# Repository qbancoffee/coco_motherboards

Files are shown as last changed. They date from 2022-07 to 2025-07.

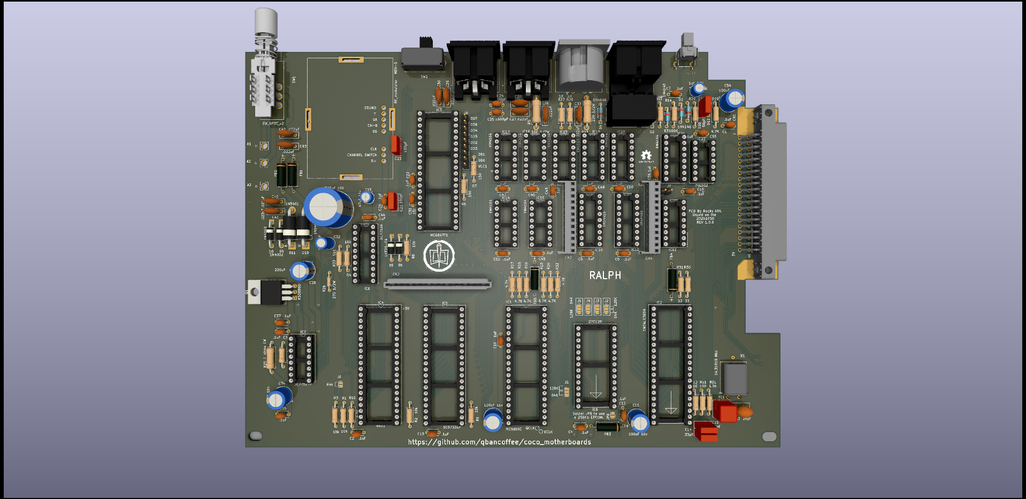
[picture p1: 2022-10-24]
images/26-313xB_rendered.png

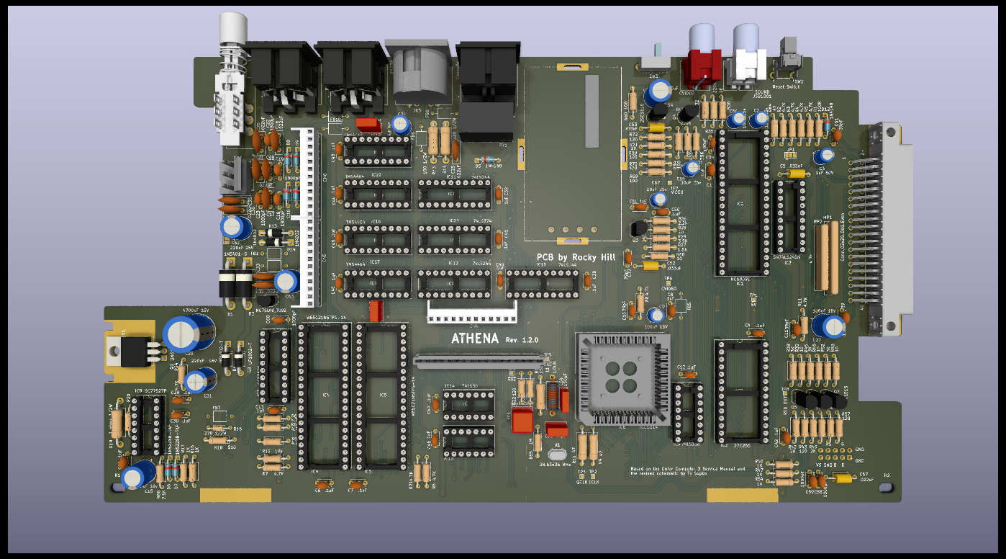
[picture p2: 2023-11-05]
images/26-3334_rendered.png

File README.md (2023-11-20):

# CoCo Motherboards
This repository contains KiCAD project files that contain schematics and board designs for the TRS-80 Tandy Color Computers that I have recreated.
If you want to view and edit these KiCAD projects you'll need KiCAD 7 or higher.
You can generate gerber files and order these boards fom your favorite PCB manufacturer.<br>

In order to get the design files you can either use git to clone the repository or you can click on the code button above and download
a zip file containing the projects.

To use git, open a terminal and type the following.
```bash
git clone https://github.com/qbancoffee/coco_motherboards.git
```
---

# Color Computer 2
- [26-302x](#26-302x)
- [26-313xA](#26-313xA)
- [26-313xB](#26-313xB)
---

# Color Computer 3
- [26-3334](#26-3334)
---

## 26-302x
- [Schematic](pdfs/26-302x_schematic.pdf)
- [Board Layout](pdfs/26-302x_layout.pdf)
- [Rendered Image](images/26-302x_rendered.png)
- [Interactive BOM](https://htmlpreview.github.io/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)
- [Bill Of Materials](https://github.com/qbancoffee/coco_motherboards/blob/main/bom/26-302x_bill_of_materials.csv)
### Current status
- [x] Ordered
- [x] Assembled
- [x] Tested
### Videos
- [Testing the first revision of the board](https://youtu.be/QcRTDDZ0i-s)
- [Testing the second revision of the board](https://youtu.be/V18fohn3YzE)
- [Testing the first revision of the Daiquiri on this board. The Daiquiri has since been fixed ](https://youtu.be/-PZM2CGa1yw)
---

## 26-313xA
- [Schematic](pdfs/26-313xA_schematic.pdf)
- [Board Layout](pdfs/26-313xA_layout.pdf)
- [Rendered Image](images/26-313xA_rendered.png)
- [Interactive BOM](https://htmlpreview.github.io/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)
- [Bill Of Materials](https://github.com/qbancoffee/coco_motherboards/blob/main/bom/26-313xA_bill_of_materials.csv)
### Current status
- [x] Ordered
- [x] Assembled
- [x] Tested
### Videos
- [Copying the board layout and original path of the traces 1](https://youtu.be/ZVgJEOnWDyY)
- [Copying the board layout and original path of the traces 2](https://youtu.be/GyRi-DuZtJM)
- [Checking the board design against an actual board](https://youtu.be/TTYBf1dwHVs)
- [Testing the assembled board](https://youtu.be/1itwh79Q89k)
---

## 26-313xB
- [Schematic](pdfs/26-313xB_schematic.pdf)
- [Board Layout](pdfs/26-313xB_layout.pdf)
- [Rendered Image](images/26-313xB_rendered.png)
- [Interactive BOM](https://htmlpreview.github.io/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)
- [Bill Of Materials](https://github.com/qbancoffee/coco_motherboards/blob/main/bom/26-313xB_bill_of_materials.csv)
### Current status
- [x] Ordered
- [x] Assembled
- [x] Tested/works but draws too much current and I don't know why yet.
### Videos
- [A timelapse of the assembly](https://youtu.be/u0PwnJCS3qc)
---

## 26-3334
- [Changes](log/26-3334_log.txt)
- [Schematic](pdfs/26-3334_schematic.pdf)
- [Board Layout](pdfs/26-3334_layout.pdf)
- [Rendered Image](images/26-3334_rendered.png)
- [Interactive BOM](https://htmlpreview.github.io/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)
- [Bill Of Materials](https://github.com/qbancoffee/coco_motherboards/blob/main/bom/26-3334_bill_of_materials.csv)
### Current status
- [x] Ordered
- [ ] Assembled
- [ ] Tested
### Videos
- [Testing the first revision of the board](https://youtu.be/vjpey5T-lSU)
- [Testing the RGB port](https://youtu.be/EB2sbTMWF-Q)
- [Booting NitrOS 9 Ease Of Use](https://youtu.be/wSlYcxvCpys)
- [Live build of Rev 1.1.0](https://www.youtube.com/live/8h18PMZnpsQ?si=pRSccAcrxts3vaQu)
- [Live build of Rev 1.1.0 part two it's alive!](https://www.youtube.com/live/c8nBd60M5xo?si=J7Mg_S3EWyWba8Rm)
- [Rev 1.2.0 test fit](https://youtube.com/shorts/IoNqxNSzjd0)
---

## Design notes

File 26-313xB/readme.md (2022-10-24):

# TRS-80 Color Computer 2 [26-3134B / 26-3136B]

This directory contains a KiCad project
for the schematic & PCB of the TRS-80 Color Computer 2
models 26-3134B and 26-3136B.

## Sources

### Schematic

Schematics are not available for this model:
The reference board was donated by MrDave6309

## Completed
- [N/A]
 
## Tested
- [N/A]

## Videos
- [N/A]

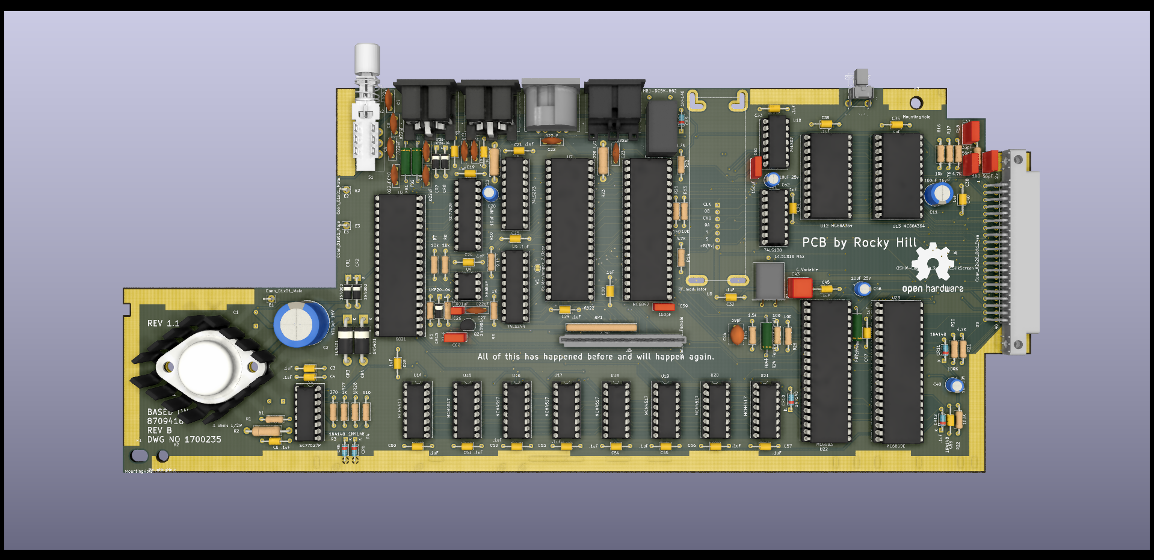
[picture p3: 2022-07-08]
images/26-302x_rendered.png

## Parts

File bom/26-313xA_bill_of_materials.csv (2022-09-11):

Requested Quantity 1 | Part Number | Vendor | Manufacturer Part Number | Description | Reference Designator
1 | ED11524-ND | Digikey | 6331-0-00-15-00-00-08-0 | CONN PC PIN CIRC 0.093DIA GOLD | A1
1 | ED11524-ND | Digikey | 6331-0-00-15-00-00-08-0 | CONN PC PIN CIRC 0.093DIA GOLD | A2
1 | ED11524-ND | Digikey | 6331-0-00-15-00-00-08-0 | CONN PC PIN CIRC 0.093DIA GOLD | A3
21 | 490-8814-ND | Digikey | RDER71H104K0K1H03B | CAP CER 0.1UF 50V X7R RADIAL | C1 C5 C6 C4 C10 C55 C12 C54 C99915 C16 C56 C31 C22 C20 C35 C2 C18 C44 C37 C7 C39
1 | 490-9014-1-ND | Digikey | RDE5C1H390J0M1H03A | CAP CER 39PF 50V C0G/NP0 RADIAL | C13
1 | 445-180775-1-ND | Digikey | FA28NP01H330JNU06 | CAP CER 33PF 50V NP0 RADIAL | C14
2 | 490-9030-1-ND | Digikey | RDE5C1H560J0M1H03A | CAP CER 56PF 50V C0G/NP0 RADIAL | C15 C17
1 | 493-16246-1-ND | Digikey | ULD1C470MDD1TD | CAP ALUM 47UF 20% 16V RADIAL | C19
2 | 445-180756-1-ND | Digikey | FA28C0G2E151JNU06 | CAP CER 150PF 250V C0G RADIAL | C23 C21
2 | 445-180714-1-ND | Digikey | FA28C0G1H182JNU06 | CAP CER 1800PF 50V C0G RADIAL | C24 C25
1 | 493-10824-1-ND | Digikey | UES1E100MDM1TD | CAP ALUM 10UF 20% 25V RADIAL | C32
1 | 1189-2204-ND | Digikey | 16ZLJ4700M16X25 | CAP ALUM 4700UF 20% 16V RADIAL | C36
1 | 493-15896-1-ND | Digikey | URS1C221MPD1TA | CAP ALUM 220UF 20% 16V RADIAL | C38
12 | 399-14073-1-ND | Digikey | C317C223M5U5TA7301 | CAP CER 0.022UF 50V Z5U RADIAL | C57 C59 C27 C33 C26 C28 C29 C30 C40 C41 C42 C43
1 | 399-13913-1-ND | Digikey | C315C102K1R5TA7301 | CAP CER 1000PF 100V X7R RADIAL | C58
1 | 718-2229-ND | Digikey | 515D105M050JA6AE3 | CAP ALUM 1UF 20% 50V RADIAL | C8
3 | P10369CT-ND | Digikey | ECA-1CM101B | CAP ALUM 100UF 20% 16V RADIAL | C9 C11 C34
1 | S9672-ND | Digikey | EBC20DRAS | CONN EDGE DUAL FMALE 40POS 0.100 | CN1
1 | A144434-ND | Digikey | 6-520415-6 | CONN FFC VERT 16POS 2.54MM PCB | CN2
2 | 23-0022182121-ND | Digikey | 22182121 | CONN RCPT 12POS 0.1 GOLD PCB | CN4 CN3
2 | 1N5401GDICT-ND | Digikey | 1N5401G-T | DIODE GEN PURP 100V 3A AXIAL | D10 D11
6 | 1N4148FS-ND | Digikey | 1N4148 | DIODE GEN PURP 100V 200MA DO35 | D12 D4 D13 D2 D1 D3
3 | 1N4148FS-ND | Digikey | 1N4148 | DIODE GEN PURP 100V 200MA DO35 | D7 D5 D6
2 | 1N4002GDICT-ND | Digikey | 1N4002G-T | DIODE GEN PURP 100V 1A DO41 | D8 D9
6 | 1934-1364-ND | Digikey | 2743007111 | FERRITE BEAD AXIAL 1LN | FB6 FB4 FB3 FB5 FB2 FB1
1 | ED3048-5-ND | Digikey | ED40DT | CONN IC DIP SOCKET 40POS TIN | IC1
2 | AE9995-ND | Digikey | A 18-LC-TT | CONN IC DIP SOCKET 18POS TIN | IC10 IC11
1 | A120349-ND | Digikey | 1-2199298-4 | CONN IC DIP SOCKET 16POS TIN | IC12
1 | 296-1639-5-ND | Digikey | SN74LS138N | IC DECODER/DEMUX 1X3:8 16DIP | IC12
2 | AE9989-ND | Digikey | A 14-LC-TT | CONN IC DIP SOCKET 14POS TIN | IC13 IC99913
2 | 296-12770-5-ND | Digikey | CD74HC02E | IC GATE NOR 4CH 2-INP 14DIP | IC13 IC99913
1 | 1175-1479-ND | Digikey | 243-20-1-03 | CONN IC DIP SOCKET 20POS TIN | IC15
1 | 296-1657-5-ND | Digikey | SN74LS273N | IC FF D-TYPE SNGL 8BIT 20DIP | IC15
1 | AE9986-ND | Digikey | A 08-LC-TT | CONN IC DIP SOCKET 8POS TIN | IC16
1 | 296-NE555P-ND | Digikey | NE555P | IC OSC SINGLE TIMER 100KHZ 8-DIP | IC16
1 | ED3048-5-ND | Digikey | ED40DT | CONN IC DIP SOCKET 40POS TIN | IC2
1 | ED3048-5-ND | Digikey | ED40DT | CONN IC DIP SOCKET 40POS TIN | IC3
1 | ED3048-5-ND | Digikey | ED40DT | CONN IC DIP SOCKET 40POS TIN | IC4
1 | ED3048-5-ND | Digikey | ED40DT | CONN IC DIP SOCKET 40POS TIN | IC5
1 | 1175-1479-ND | Digikey | 243-20-1-03 | CONN IC DIP SOCKET 20POS TIN | IC6
1 | A120349-ND | Digikey | 1-2199298-4 | CONN IC DIP SOCKET 16POS TIN | IC7
1 | AE10004-ND | Digikey | A 28-LC-TT | CONN IC DIP SOCKET 28POS TIN | IC8
1 | CP-2360-ND | Digikey | SDS-60J | CONN RCPT FMALE DIN 6POS SOLDER | JK1
1 | CP-2360-ND | Digikey | SDS-60J | CONN RCPT FMALE DIN 6POS SOLDER | JK2
1 | CP-2340-ND | Digikey | SDS-40J | CONN RCPT FMALE DIN 4POS SOLDER | JK3
1 | CP-2350-ND | Digikey | SDS-50J | CONN RCPT FMALE DIN 5POS SOLDER | JK4
1 | KSD880OFS-ND | Digikey | KSD880O | TRANS NPN 60V 3A TO220-3 | Q1
1 | 1514-PN2222APBFREE-ND | Digikey | PN2222A PBFREE | TRANS NPN 40V 0.8A TO92-3 | Q2
3 | 100XBK-ND | Digikey | MFR-25FBF52-100R | RES 100 OHM 1% 1/4W AXIAL | R11 R12 R29
2 | CF14JT100KCT-ND | Digikey | CF14JT100K | RES 100K OHM 5% 1/4W AXIAL | R14 R13
8 | CF14JT4K70CT-ND | Digikey | CF14JT4K70 | RES 4.7K OHM 5% 1/4W AXIAL | R20 R17 R15 R16 R18 R19 R6 R10
1 | 1.50KXBK-ND | Digikey | MFR-25FBF52-1K5 | RES 1.5K OHM 1% 1/4W AXIAL | R21
1 | CF14JT510RCT-ND | Digikey | CF14JT510R | RES 510 OHM 5% 1/4W AXIAL | R22
1 | CF12JT220RCT-ND | Digikey | CF12JT220R | RES 220 OHM 5% 1/2W AXIAL | R23
1 | 2019-CF1/4CT52R510JCT-ND | Digikey | CF1/4CT52R510J | RES 51 OHM 5% 1/4W AXIAL | R24
1 | RSMF1JTR100CT-ND | Digikey | RSMF1JTR100 | RES 0.1 OHM 5% 1W AXIAL | R25
1 | BC4316CT-ND | Digikey | SFR16S0002700JA500 | RES 270 OHM 1/2W 5% AXIAL | R28
2 | CF14JT33R0CT-ND | Digikey | CF14JT33R0 | RES 33 OHM 5% 1/4W AXIAL | R30 R31
3 | CF14JT1K00CT-ND | Digikey | CF14JT1K00 | RES 1K OHM 5% 1/4W AXIAL | R32 R27 R26
1 | CF14JT9K10CT-ND | Digikey | CF14JT9K10 | RES 9.1K OHM 5% 1/4W AXIAL | R33
1 | 13-MFR-25FRF52-2K2CT-ND | Digikey | MFR-25FRF52-2K2 | RES 2.2K OHM 1% 1/4W AXIAL | R34
1 | CF12JT100RCT-ND | Digikey | CF12JT100R | RES 100 OHM 5% 1/2W AXIAL | R5
1 | CF14JT150RCT-ND | Digikey | CF14JT150R | RES 150 OHM 5% 1/4W AXIAL | R7
6 | CF14JT10K0CT-ND | Digikey | CF14JT10K0 | RES 10K OHM 5% 1/4W AXIAL | R8 R2 R3 R4 R9 R1
1 | 2449-J0971CS5VDC.45-ND | Digikey | J0971CS5VDC.45 | RELAY GEN PURPOSE SPDT 10A 5V | RY1
1 | 401-1223-ND | Digikey | F2UEE | SWITCH PUSH DPDT 0.5A 125V | SW1
1 | 563-1558-ND | Digikey | MFS201N-16-Z | SWITCH SLIDE DPDT 1A 125V | SW2
1 | SW410-ND | Digikey | B3F-3152 | SWITCH TACTILE SPST-NO 0.05A 24V | SW3
1 | SW451-ND | Digikey | B32-1010 | CAP TACTILE SQUARE BLACK | SW3
1 | 2447-GKG50015-ND | Digikey | GKG50015 | CAP TRIMMER 10-50PF 100V TH | TC1
1 | CTX088-ND | Digikey | MP143 | CRYSTAL 14.31818MHZ SERIES TH | X1
1 | 595-SN74LS623N | Mouser | SN74LS623N | Transceiver, Non-Inverting | IC14

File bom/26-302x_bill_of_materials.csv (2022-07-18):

Requested Quantity 1 | Digi-Key Part Number 1 | Manufacturer Part Number | Description
1 | 1.50KXBK-ND | MFR-25FBF52-1K5 | RES 1.5K OHM 1% 1/4W AXIAL
3 | 100XBK-ND | MFR-25FBF52-100R | RES 100 OHM 1% 1/4W AXIAL
50 | 1109PHCT-ND | A104K15X7RF5TAA | CAP CER 0.1UF 50V X7R AXIAL
3 | 1175-1479-ND | 243-20-1-03 | CONN IC DIP SOCKET 20POS TIN
2 | 1175-2551-ND | 243-24-1-06 | CONN IC DIP SOCKET 24POS TIN
1 | 1189-1145-ND | 16YXJ4700M16X25 | CAP ALUM 4700UF 20% 16V RADIAL
4 | 1934-1364-ND | 2743007111 | FERRITE BEAD AXIAL 1LN
1 | 2019-CF1/4CT52R510JCT-ND | CF1/4CT52R510J | RES 51 OHM 5% 1/4W AXIAL
1 | 2447-GKG50015-ND | GKG50015 | CAP TRIMMER 10-50PF 100V TH
1 | 2449-J0971CS5VDC.45-ND | J0971CS5VDC.45 | RELAY GEN PURPOSE SPDT 10A 5V
1 | 296-1627-5-ND | SN74LS02N | IC GATE NOR 4CH 2-INP 14DIP
1 | 296-1639-5-ND | SN74LS138N | IC DECODER/DEMUX 1X3:8 16DIP
1 | 296-1653-5-ND | SN74LS244N | IC BUF NON-INVERT 5.25V 20DIP
1 | 296-1657-5-ND | SN74LS273N | IC FF D-TYPE SNGL 8BIT 20DIP
3 | 36-1211-ND | 1211 | CONN QC TAB 0.110 SOLDER
1 | 401-1223-ND | F2UEE | SWITCH PUSH DPDT 0.5A 125V
2 | 445-180756-1-ND | FA28C0G2E151JNU06 | CAP CER 150PF 250V C0G RADIAL
2 | 445-180775-1-ND | FA28NP01H330JNU06 | CAP CER 33PF 50V NP0 RADIAL
1 | 490-9014-1-ND | RDE5C1H390J0M1H03A | CAP CER 39PF 50V C0G/NP0 RADIAL
2 | 490-9030-1-ND | RDE5C1H560J0M1H03A | CAP CER 56PF 50V C0G/NP0 RADIAL
1 | 493-10824-1-ND | UES1E100MDM1TD | CAP ALUM 10UF 20% 25V RADIAL
2 | 493-1809-ND | UPW1E100MDD | CAP ALUM 10UF 20% 25V RADIAL
1 | 718-2229-ND | 515D105M050JA6AE3 | CAP ALUM 1UF 20% 50V RADIAL
11 | A120349-ND | 1-2199298-4 | CONN IC DIP SOCKET 16POS TIN
1 | A144434-ND | 6-520415-6 | CONN FFC VERT 16POS 2.54MM PCB
1 | CF12JT100RCT-ND | CF12JT100R | RES 100 OHM 5% 1/2W AXIAL
1 | CF12JT220RCT-ND | CF12JT220R | RES 220 OHM 5% 1/2W AXIAL
2 | CF14JT100KCT-ND | CF14JT100K | RES 100K OHM 5% 1/4W AXIAL
10 | CF14JT10K0CT-ND | CF14JT10K0 | RES 10K OHM 5% 1/4W AXIAL
1 | CF14JT150RCT-ND | CF14JT150R | RES 150 OHM 5% 1/4W AXIAL
3 | CF14JT1K00CT-ND | CF14JT1K00 | RES 1K OHM 5% 1/4W AXIAL
1 | CF14JT270RCT-ND | CF14JT270R | RES 270 OHM 5% 1/4W AXIAL
10 | CF14JT4K70CT-ND | CF14JT4K70 | RES 4.7K OHM 5% 1/4W AXIAL
1 | CF14JT510RCT-ND | CF14JT510R | RES 510 OHM 5% 1/4W AXIAL
1 | CF14JT9K10CT-ND | CF14JT9K10 | RES 9.1K OHM 5% 1/4W AXIAL
1 | CP-2340-ND | SDS-40J | CONN RCPT FMALE DIN 4POS SOLDER
1 | CP-2350-ND | SDS-50J | CONN RCPT FMALE DIN 5POS SOLDER
2 | CP-2360-ND | SDS-60J | CONN RCPT FMALE DIN 6POS SOLDER
1 | CTX088-ND | MP143 | CRYSTAL 14.31818MHZ SERIES TH
5 | ED3048-5-ND | ED40DT | CONN IC DIP SOCKET 40POS TIN
1 | HS110-ND | 501603B00000G | HEAT SINK TO-3 1.25" COMPACT
1 | S9672-ND | EBC20DRAS | CONN EDGE DUAL FMALE 40POS 0.100
1 | SW410-ND | B3F-3152 | SWITCH TACTILE SPST-NO 0.05A 24V
1 | SW451-ND | B32-1010 | CAP TACTILE SQUARE BLACK
1 | AE9989-ND | A 14-LC-TT | CONN IC DIP SOCKET 14POS TIN
1 | AE9986-ND | A 08-LC-TT | CONN IC DIP SOCKET 8POS TIN
2 | P10369CT-ND | ECA-1CM101B | CAP ALUM 100UF 20% 16V RADIAL
1 | A105964CT-ND | LR1LJR10 | RES 0.1 OHM 5% 1/2W AXIAL
6 | 1N4148FS-ND | 1N4148 | DIODE GEN PURP 100V 200MA DO35
11 | 399-14073-1-ND | C317C223M5U5TA7301 | CAP CER 0.022UF 50V Z5U RADIAL
1 | 4610X-1-472LF-ND | 4610X-101-472LF | RES ARRAY 9 RES 4.7K OHM 10SIP
1 | 399-13913-1-ND | C315C102K1R5TA7301 | CAP CER 1000PF 100V X7R RADIAL
2 | 1N4002GDICT-ND | 1N4002G-T | DIODE GEN PURP 100V 1A DO41
2 | 1N5401GDICT-ND | 1N5401G-T | DIODE GEN PURP 100V 3A AXIAL
1 | 2N3055GOS-ND | 2N3055G | TRANS NPN 60V 15A TO204
1 | 1514-PN2222APBFREE-ND | PN2222A PBFREE | TRANS NPN 40V 0.8A TO92-3
1 | 296-NE555P-ND | NE555P | IC OSC SINGLE TIMER 100KHZ 8-DIP
3 | 1N4148FS-ND | 1N4148 | DIODE GEN PURP 100V 200MA DO35
1 | 493-12679-1-ND | UVP1C100MDD1TD | CAP ALUM 10UF 20% 16V RADIAL
1 | CP1-3533NG-ND | SJ1-3533NG | CONN JACK STEREO 3.5MM R/A
1 | S9716-ND | SBH11-NBPC-D03-ST-BK | CONN HEADER VERT 6POS 2.54MM
1 | 401-1215-ND | F0201 | CAP PUSHBUTTON ROUND BLACK

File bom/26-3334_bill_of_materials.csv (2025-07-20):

Qty | Reference(s) | Value | Manufacturer part# | Vendor | Vendor 2nd part# | Vendor part# | Description 2nd part | MPN | Manufacturer 2nd part#
24 | C1, C4, C6, C7, C8, C12, C13, C14, C26, C28, C30, C38, C39, C40, C41, C42, C43, C44, C45, C46, C47, C48, C50, C51 | .1uF | RDER71H104K0M1H03A | digikey |  | 490-9144-1-ND
4 | C2, C55, C56, C67 | 10uF 25v | UPW1E100MDD | digikey |  | 493-1809-ND
1 | C3 | 1uF 50V | 515D105M050JA6AE3 | digikey |  | 718-2229-ND
3 | C5, C52, C53 | .033uF | C410C333K5R5TA7200 | digikey |  | 399-4470-1-ND
1 | C9 | 100uF 16V | 16ZLH100MEFC5X11 | digikey |  | 1189-1148-ND
4 | C10, C11, C37, C61 | 39pF | K390J15C0GF5TL2 | digikey |  | BC1008CT-ND
2 | C15, C27 | 100uF 16v | UST1C101MDD1TA | digikey |  | 493-17434-1-ND
10 | C16, C17, C20, C21, C25, C32, C33, C35, C36, C49 | .022uF | C317C223M5U5TA7301 | digikey |  | 399-14073-1-ND
4 | C18, C19, C22, C23 | 1800pF | FA28C0G1H182JNU06 | digikey |  | 445-180714-1-ND
1 | C24 | 10uF NP | UVP1E100MDD1TD | digikey |  | 493-12688-1-ND
1 | C29 | 4700uF 16V | 16PK4700MEFC12.5X25 | digikey |  | 1189-1123-ND
1 | C31 | 220uF 16V | URS1C221MPD1TA | digikey |  | 493-15896-1-ND
1 | C34 | 100pF | K101J15C0GF5TH5 | digikey |  | BC1042CT-ND
1 | C54 | 470uF | ECA-1CM471 | digikey |  | P5141-ND
1 | C57 | .022uF | C410C223K5R5TA7200 | digikey |  | 399-4464-1-ND
3 | C58, C59, C68 | 1000pF | K102K10X7RF5UH5 | digikey |  | BC2659CT-ND
1 | C60 | 33pF | FA28NP01H330JNU06 | digikey |  | 445-180775-1-ND
2 | C62, C63 | 220uF 25V | ECA-1EM221 | digikey |  | P5153-ND
1 | C64 | 150pF | FA28C0G2E151JNU06 | digikey |  | 445-180756-1-ND
1 | C65 | 82pF | K820J15C0GF5TH5 | digikey |  | BC1041CT-ND
1 | C66 | 27pF | K270J15C0GF5TH5 | digikey |  | BC1035CT-ND
1 | CN1 | Conn_02x20_Odd_Even | EBC20DRAS | digikey |  | S9672-ND
1 | CN2 | Conn_01x16_Female | 6-520415-6 | digikey |  | A144434-ND
1 | CN3 | Conn_02x05_Odd_Even | PRPC005DAAN-RC | digikey |  | S2011EC-05-ND
3 | CN4, CN5, CN6 | Conn_01x12_Female | 22182121 | digikey |  | 23-0022182121-ND
1 | CN7 | Conn_01x03_Male | 9652038 | digikey |  | WM18824-ND
2 | D1, D2 | 1N5401-G | 1N5401 | digikey |  | 641-1314-1-ND
2 | D3, D4 | UF1002-T | UF1002-T | digikey |  | UF1002DICT-ND
2 | D5, D12 | 1N4148 | 1N4148 | digikey |  | 1N4148FS-ND
2 | D6, D7 | 1N5228B-TAP | 1N5228B-TAP | digikey |  | 1N5228B-TAPGICT-ND
4 | D8, D9, D10, D11 | 1N4148 | DIODE GEN PURP 100V 200MA DO35 | digikey |  | 1N4148FS-ND
2 | D13, D14 | 1N4002 | 1N4002-TP | digikey |  | 1N4002-TPMSCT-ND
8 | FB1, FB2, FB5, FB6, FB7, FB8, FB9, FB10 |  | 28L0138-10R-10 | digikey |  | 240-2438-1-ND
1 | IC1 | MC6809E | ED40DT | digikey |  | ED3048-5-ND
1 | IC2 | 27C256 | AT27C256R-45PU | digikey |  | AT27C256R-45PU-ND
1 | IC3 | SN74LS245N | SN74LS245N | digikey |  | 296-1655-5-ND |  | SN74LS245N
1 | IC4 | W65C21N6TPG-14 | W65C21N6TPG-14 | mouser |  | 955-W65C21N6TPG-14
1 | IC5 | W65C21N6TPG-14 | W65C21N6TPG-14 | mouser |  | 955-W65C21N6TPG-14
1 | IC6 | TCC1014 | A-CCS 068-G-T | digikey |  | AE11249-ND
1 | IC7 | SC77526 | 243-20-1-03 | digikey |  | 1175-1479-ND
1 | IC8 | SC77527P | 1-2199298-4 | digikey |  | A120349-ND
1 | IC9 | 74LS138 | SN74LS138N | digikey |  | 296-1639-5-ND
3 | IC10, IC11, IC12 | 74LS244 | SN74LS244N | digikey |  | 296-1653-5-ND
1 | IC13 | 74LS374 | SN74ALS374AN | digikey |  | 296-1498-5-ND
1 | IC14 | 74LS30 | SN74LS30N | digikey |  | 296-3693-5-ND
1 | IC15 | 74LS04 | SN74LS04N | digikey |  | 296-1629-5-ND
4 | IC16, IC17, IC18, IC19 | TMS4464 | A 18-LC-TT | digikey |  | AE9995-ND
1 | IC36 | MC78L08_TO92 | UA78L08ACLPRE3 | digikey |  | 296-UA78L08ACLPRE3CT-ND
1 | J5A1001 | CVIDEO | KLPX-0848A-2-R | digikey |  | 2092-KLPX-0848A-2-R-ND
1 | J5B1001 | SOUND | KLPX-0848A-2-W | digikey |  | 2092-KLPX-0848A-2-W-ND
1 | JK1 | Left Joystick | 1N4148 | digikey |  | 1N4148FS-ND
1 | JK2 | Right Joystick | SDS-60J | digikey |  | CP-2360-ND
1 | JK3 | RS232 | SDS-40J | digikey |  | CP-2340-ND
1 | JK4 | Cassette | SDS-50J | digikey |  | CP-2350-ND
1 | JP1 | SolderJumper_3_Bridged12
1 | JP2 | SolderJumper_2_Open
1 | L1 | 1.8uH | 1537-18K | digikey |  | 1134-1090-1-ND
1 | MP1 | 4.7k | 770101472P | digikey |  | 770-101-R4.7KP-ND
1 | MP2 | 4.7k | 4609H-101-472LF | digikey |  | 4609H-101-472LF-ND
1 | Q1 | 2N6123 | 2N6123 PBFREE | digikey |  | 1514-2N6123PBFREE-ND | Heatsink
5 | Q2, Q3, Q5, Q6, Q7 | 2SC1815 | 2SC1815 PBFREE | digikey |  | 1514-2SC1815PBFREE-ND
1 | Q4 | BCX38C | BCX38C | digikey |  | BCX38C-ND
1 | R1 | 100K | MFR-25FBF52-100K | digikey |  | 100KXBK-ND
13 | R2, R3, R4, R5, R6, R7, R8, R11, R21, R24, R59, R61, R62 | 4.7K | Stackpole Electronics Inc | digikey |  | CF14JT4K70CT-ND
2 | R9, R10 | 47 | CF12JT47R0 | digikey |  | CF12JT47R0CT-ND
1 | R12 | 10k | CF14JT10K0 | digikey |  | CF14JT10K0CT-ND
1 | R13 | 100 1/2W | CF12JT100R | digikey |  | CF12JT100RCT-ND
1 | R14 | 220 1/2W | CF12JT220R | digikey |  | CF12JT220RCT-ND
1 | R15 | 270 1/2W | SFR16S0002700JA500 | digikey |  | BC4316CT-ND
6 | R16, R17, R36, R40, R47, R54 | 1K | CF14JT1K00 | digikey |  | CF14JT1K00CT-ND
1 | R18 | 510 | CF14JT510R | digikey |  | CF14JT510RCT-ND
1 | R19 | .1 ohms 1/2W | LR1LJR10 | digikey |  | A105964CT-ND
1 | R20 | 51 | CF1/4CT52R510J | digikey |  | 2019-CF1/4CT52R510JCT-ND
5 | R22, R43, R50, R57, R72 | 120 | CF14JT120R | digikey |  | CF14JT120RCT-ND
1 | R23 | 82 | CF1/4CT52R820J | digikey |  | 2019-CF1/4CT52R820JCT-ND
1 | R26 | 2.2K | CF14JT2K20 | digikey |  | CF14JT2K20CT-ND
1 | R27 | 1.5K | RNF14FTD1K50 | digikey |  | RNF14FTD1K50CT-ND
6 | R28, R39, R46, R53, R68, R71 | 10 | CFR-25JB-52-10R | digikey |  | 10QBK-ND
1 | R29 | 3.9K | CF14JT3K90 | digikey |  | CF14JT3K90CT-ND
4 | R30, R34, R60, R69 | 100 | CF14JT100R | digikey |  | CF14JT100RCT-ND
1 | R31 | 39K | CFR-25JB-52-39K | digikey |  | 39KQBK-ND
1 | R32 | 20K | CFR-25JB-52-20K | digikey |  | 20KQBK-ND
2 | R33, R35 | 220K | CF14JT220K | digikey |  | CF14JT220KCT-ND
3 | R38, R45, R52 | 3K | CFR-25JB-52-3K | digikey |  | 3.0KQBK-ND
3 | R42, R49, R56 | 2K | RNF14FTD2K00 | digikey |  | RNF14FTD2K00CT-ND
1 | R63 | 150 | CF12JT150R | digikey |  | CF12JT150RCT-ND
1 | R64 | 47 | CF14JT47R0 | digikey |  | CF14JT47R0CT-ND
1 | R65 | 1M | RNF14FTD1M00 | digikey |  | RNF14FTD1M00CT-ND
1 | R66 | 7.5K | RNF14FTD7K50 | digikey |  | RNF14FTD7K50CT-ND
1 | R70 | 470 | CF14JT470R | digikey |  | CF14JT470RCT-ND
1 | RF1 | CoCo3RFModulator
1 | RY1 | J0971CS5VDC.45 | J0971CS5VDC.45 | digikey |  | 2449-J0971CS5VDC.45-ND
1 | SW1 | SW_DPDT_x2 | F2UEE | digikey |  | 401-1223-ND
1 | SW2 | Reset Switch | B3F-3152 | digikey | SW451-ND | SW410-ND |  |  | B32-1010
1 | SW3 | SW3 | EG1213 | digikey |  | EG1906-ND
1 | TC1 | 10pF-50pF | GKG60015 | digikey |  | 2447-GKG60015-ND
1 | TP1 | 5V
1 | TP2 | ECLK
1 | TP3 | QCLK
1 | TP4 | ~{RAS}
1 | TP5 | ~{CAS}
1 | TP6 | CVIDEO
1 | TP7 | VIDEO
1 | TP8 | RED OUT
1 | X1 | 28.63636 MHz | ECS-286.3-20-46X | digikey |  | XC1766-ND

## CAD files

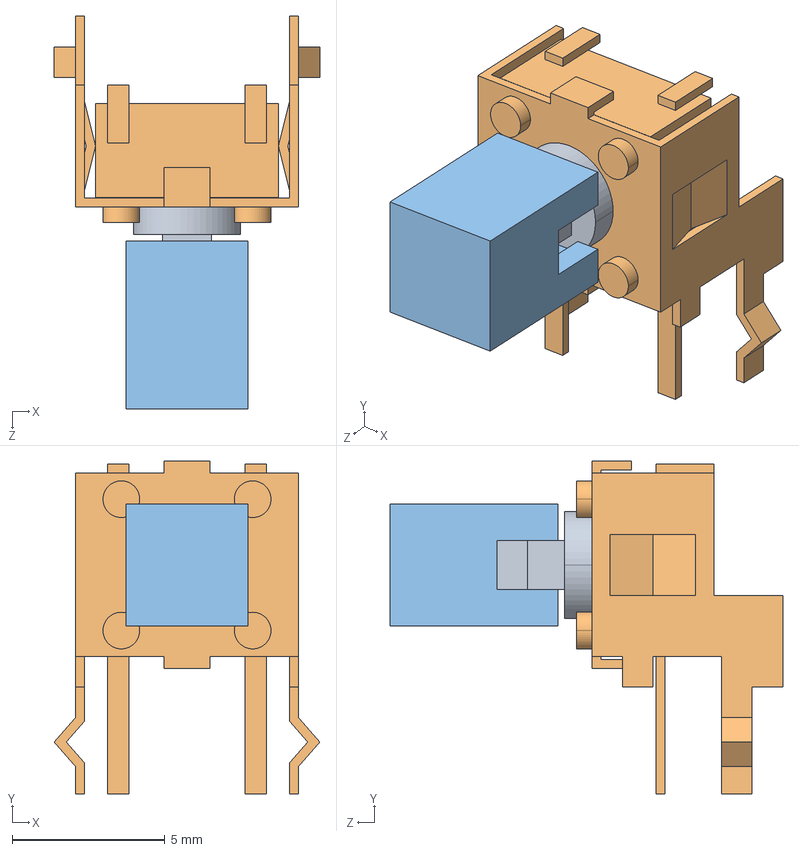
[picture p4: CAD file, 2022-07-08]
26-313xB/3d_models/B3F-3152.step
8.70 x 10.9 x 12.9 mm
B3F_3152_BUTTON
B3F_3152_BASE
B32_1000

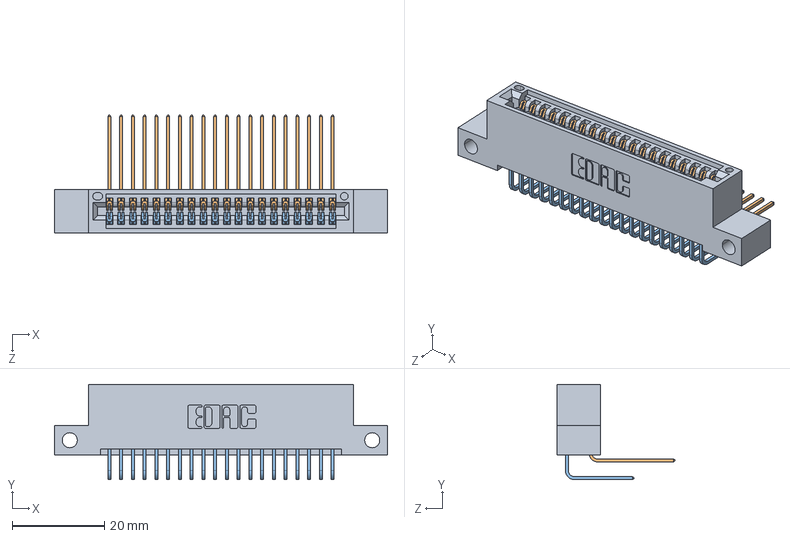
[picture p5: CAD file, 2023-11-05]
26-3334/3d_models/EDAC Card_Edge_Connector.step
72.0 x 20.6 x 25.5 mm
345 Part_Flush Mounting Lugs - Side Mount
345-292-001_558 559 Tail - 1 x 20
345-292-001_559 Tail - 2 x 20

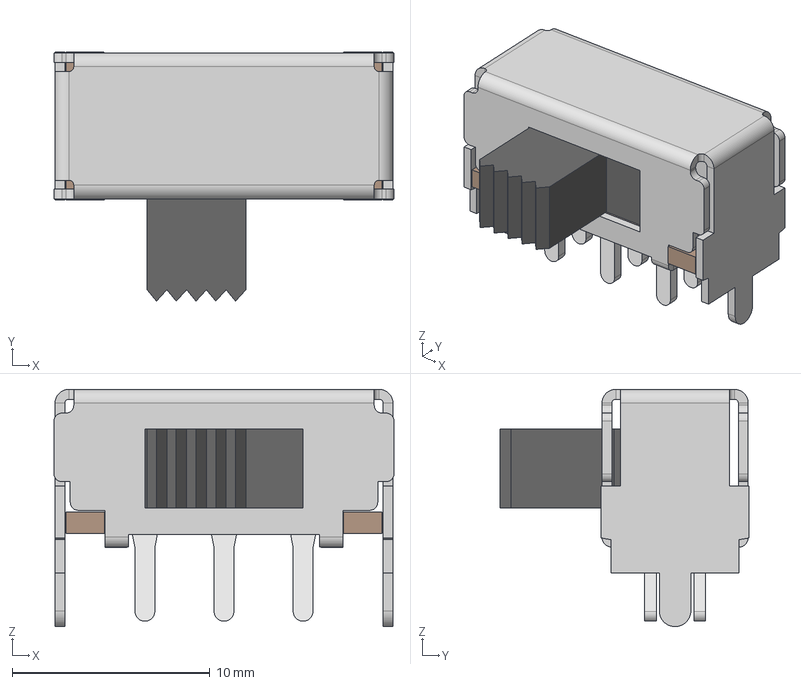
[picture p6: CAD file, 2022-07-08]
26-313xB/3d_models/MFS201N-19-Z.step
17.2 x 12.6 x 12.0 mm
BodyBottomPlate

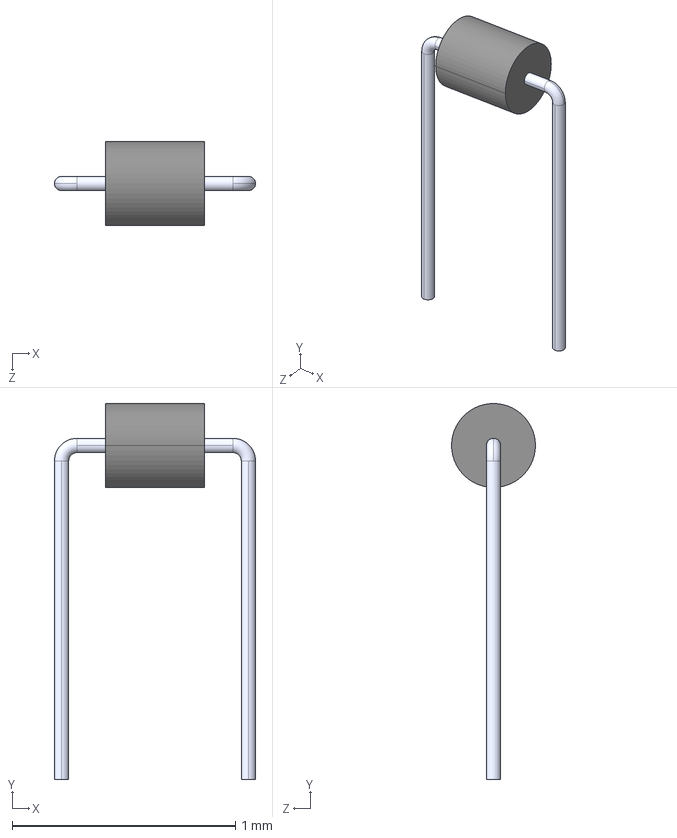
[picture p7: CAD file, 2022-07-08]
26-3334/3d_models/28L0138-10R-10.step
0.901 x 1.68 x 0.376 mm

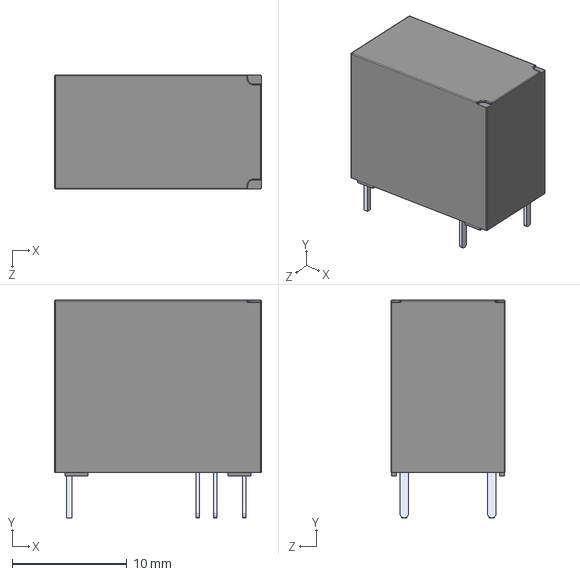
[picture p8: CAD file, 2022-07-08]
26-313xB/3d_models/J0971CS5VDC.45.step
18.0 x 19.0 x 9.95 mm

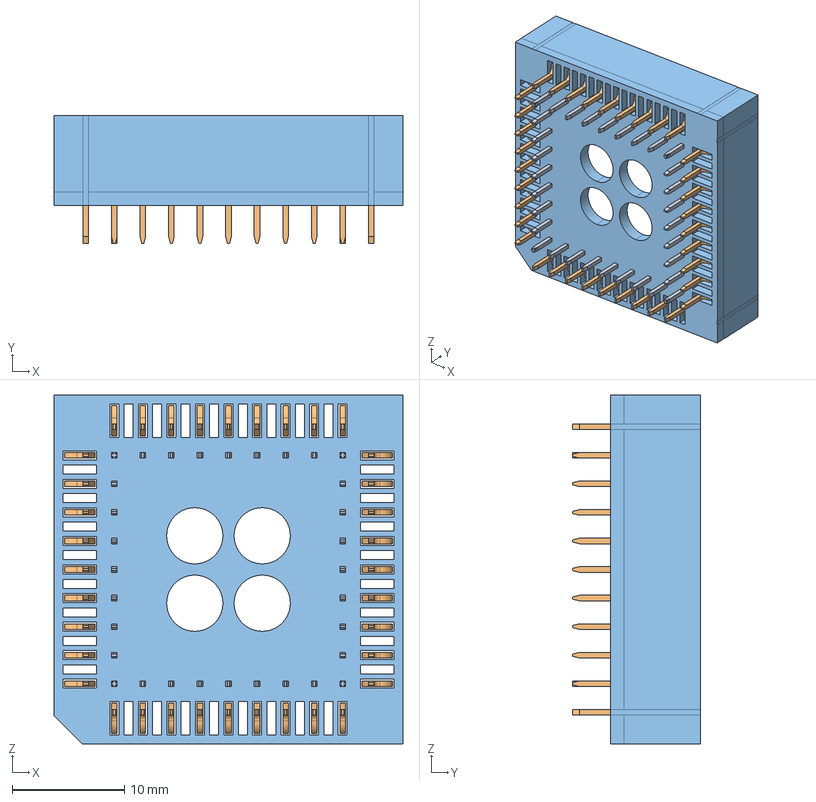
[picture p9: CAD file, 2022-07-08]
26-3334/3d_models/a-ccs_068-z-t.stp
31.1 x 11.4 x 31.1 mm

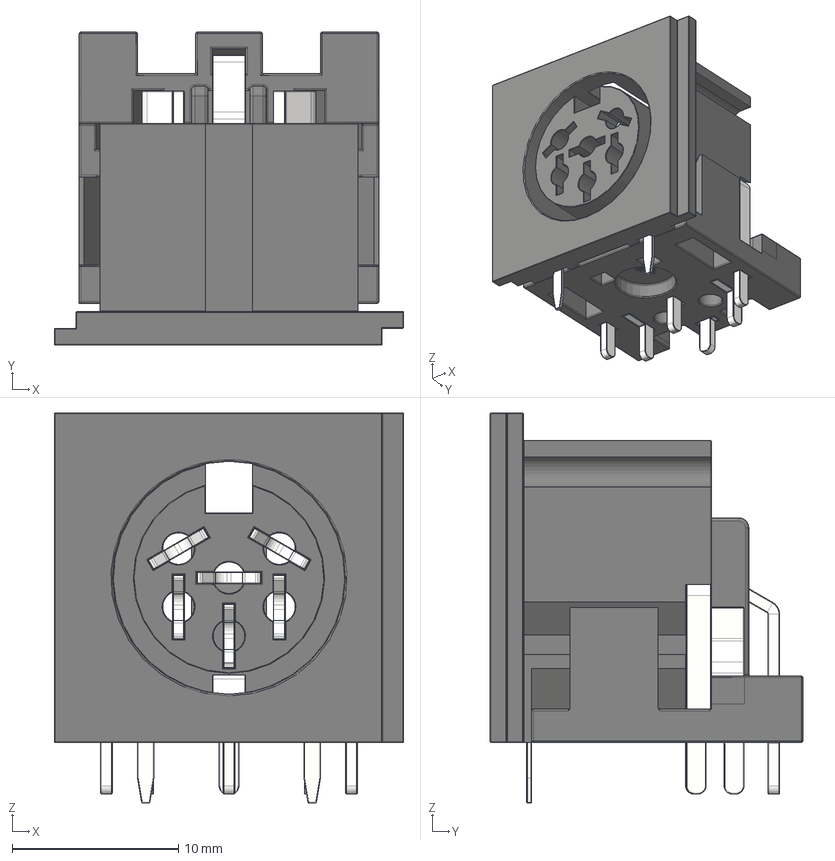
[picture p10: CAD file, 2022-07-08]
26-313xB/3d_models/DIN-6.step
21.0 x 18.8 x 23.4 mm
Baseplate IEC
Pin3
Pin4_2
Pin5_1
Pin6
Gnd pins
Housing

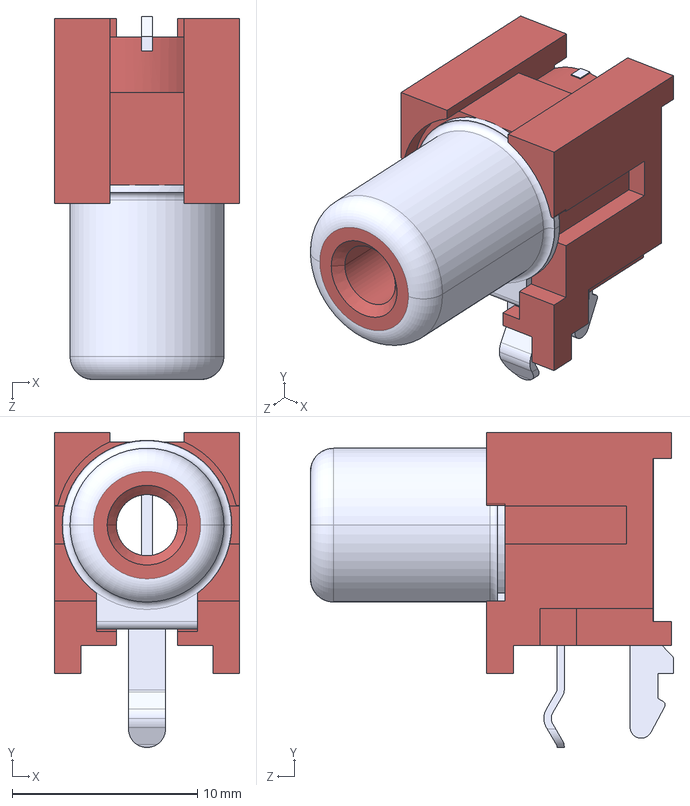
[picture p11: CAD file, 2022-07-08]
26-3334/3d_models/KLPX-0848A-2-R_rA4.STEP
10.0 x 17.0 x 19.6 mm

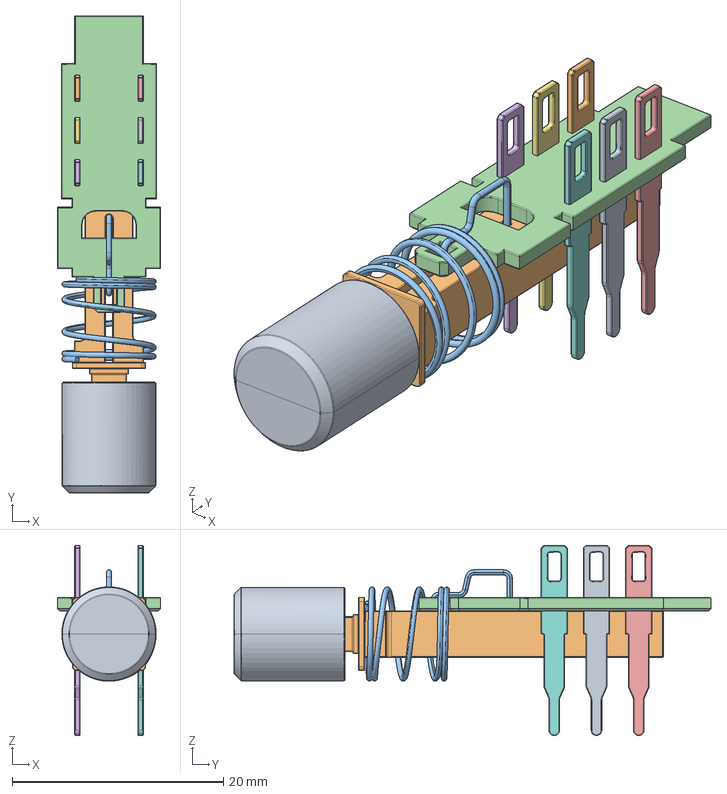
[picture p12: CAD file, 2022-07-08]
26-313xB/3d_models/switch.step
9.80 x 45.2 x 18.0 mm

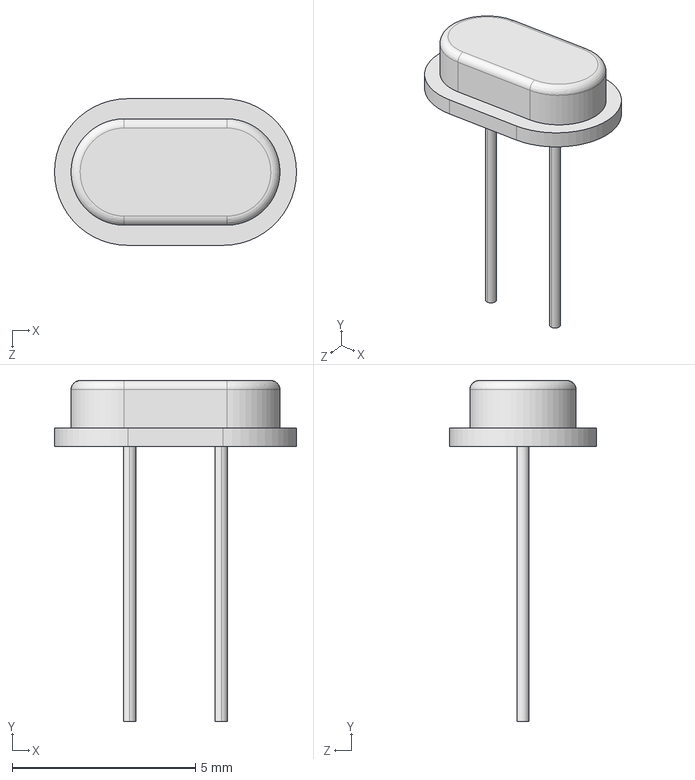
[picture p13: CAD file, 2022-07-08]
26-3334/3d_models/ECS-286.3-20-46X.step
6.60 x 9.30 x 4.00 mm

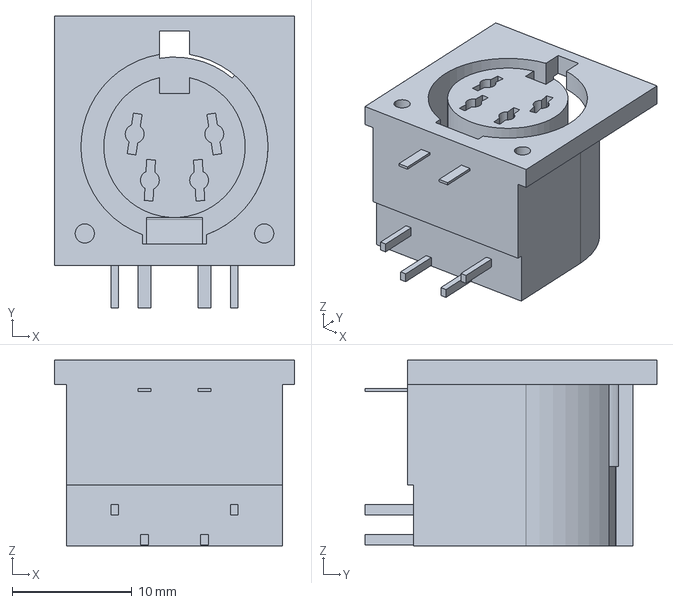
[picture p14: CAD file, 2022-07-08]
26-313xB/3d_models/DIN-4.stp
20.1 x 24.4 x 15.5 mm

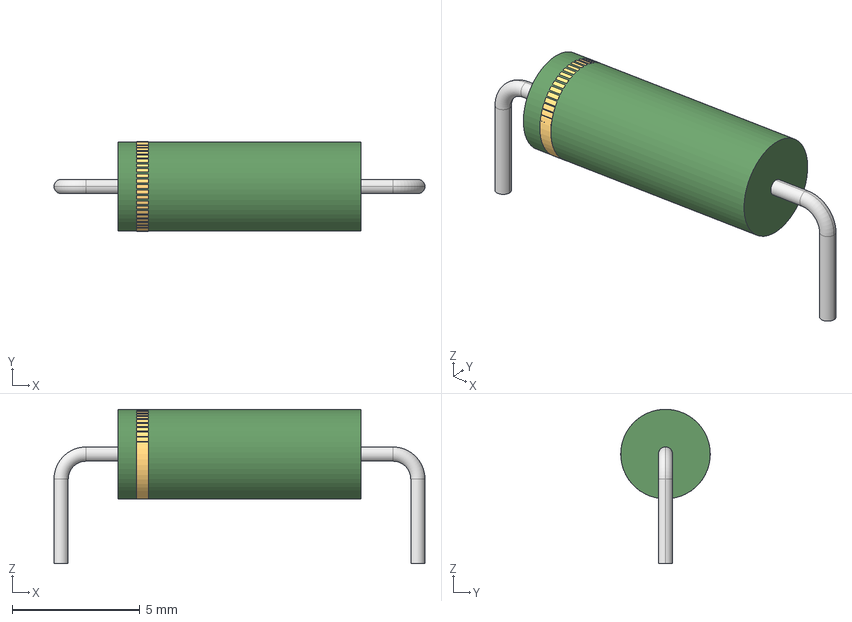
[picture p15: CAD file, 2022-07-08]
26-313xB/3d_models/ferrite_bead.step
14.5 x 3.51 x 6.05 mm

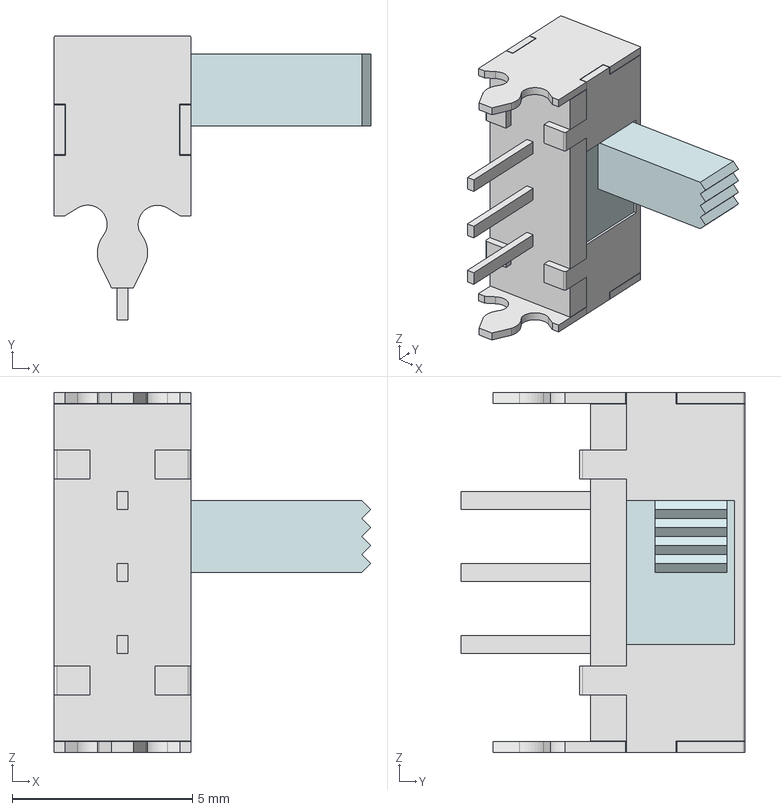
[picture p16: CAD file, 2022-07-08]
26-3334/3d_models/EG1213.stp
8.80 x 7.90 x 10.0 mm
EG1213 SHELL
EG1213 TERM
EG1213 ACTUATOR

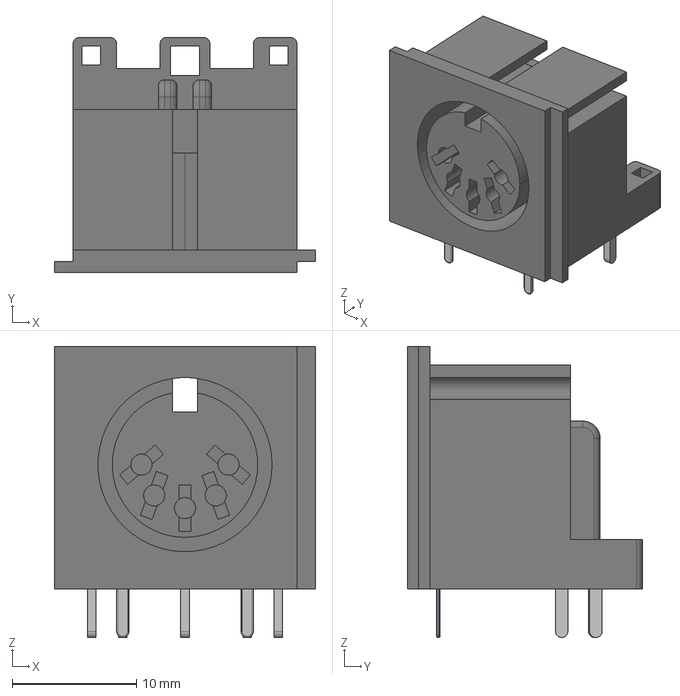
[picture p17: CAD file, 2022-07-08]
26-313xB/3d_models/din-5-jack.step
21.0 x 18.9 x 23.4 mm

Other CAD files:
26-3334/3d_models/KLPX-0848A-2-W_rA4.STEP
26-313xB/3d_models/reset_switch.step
26-313xB/3d_models/channel_switch.stp
26-313xB/3d_models/keyboard_connector.stp
26-313xB/3d_models/022182121.stp
26-313xB/3d_models/power_post.STEP
26-3334/3d_models/009652038.stp
26-3334/3d_models/022182121.step

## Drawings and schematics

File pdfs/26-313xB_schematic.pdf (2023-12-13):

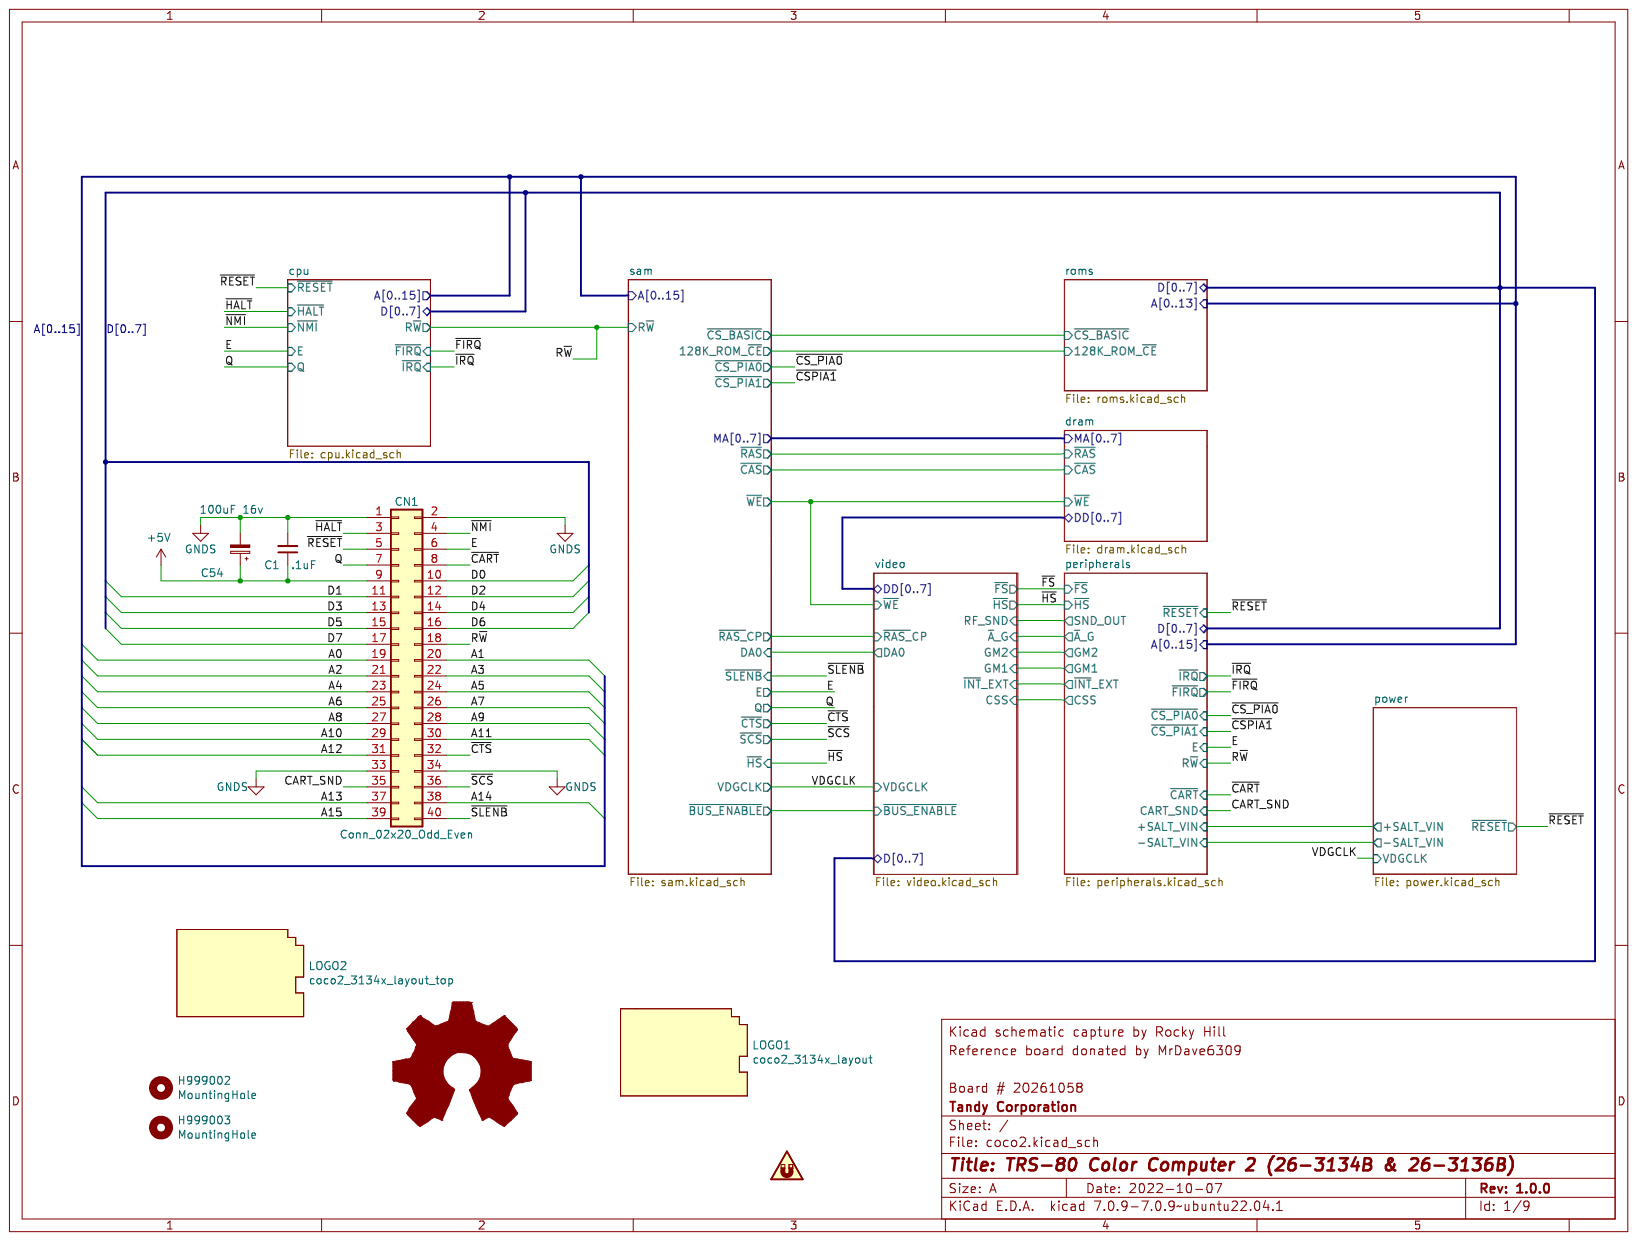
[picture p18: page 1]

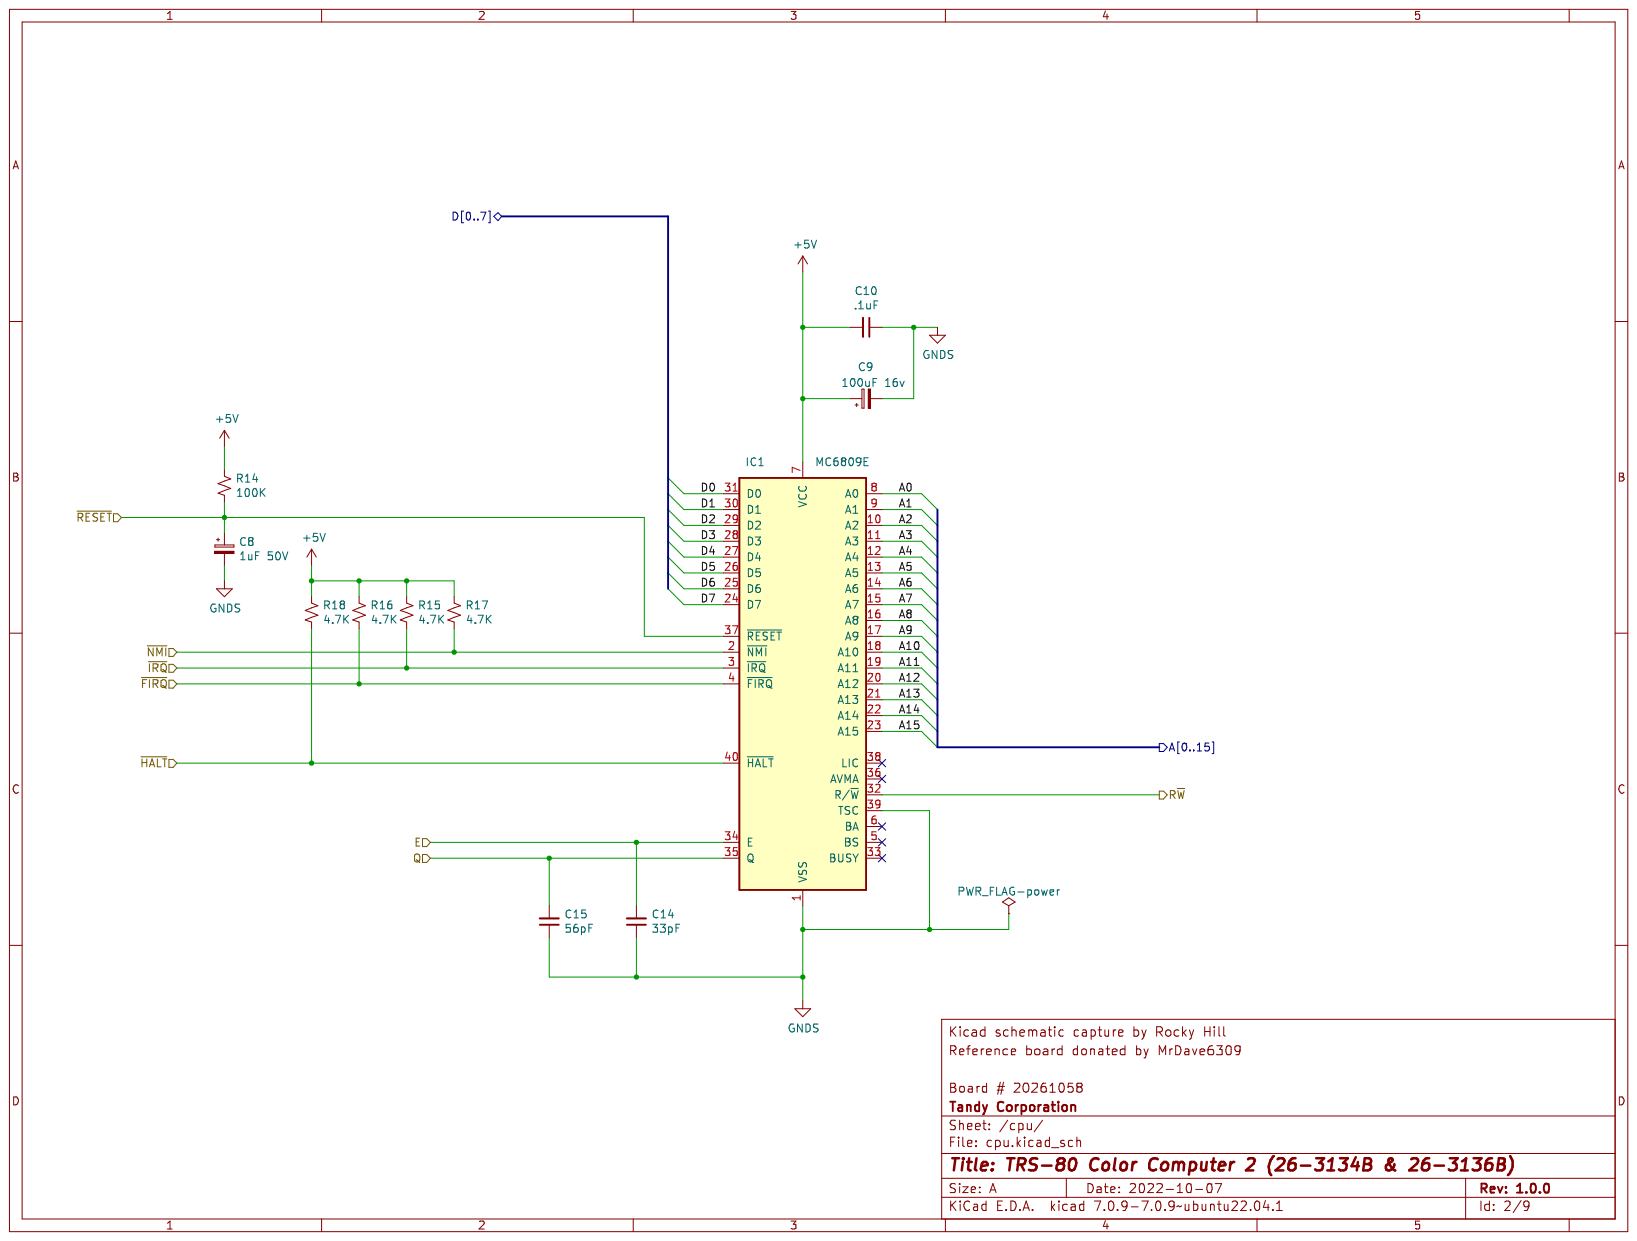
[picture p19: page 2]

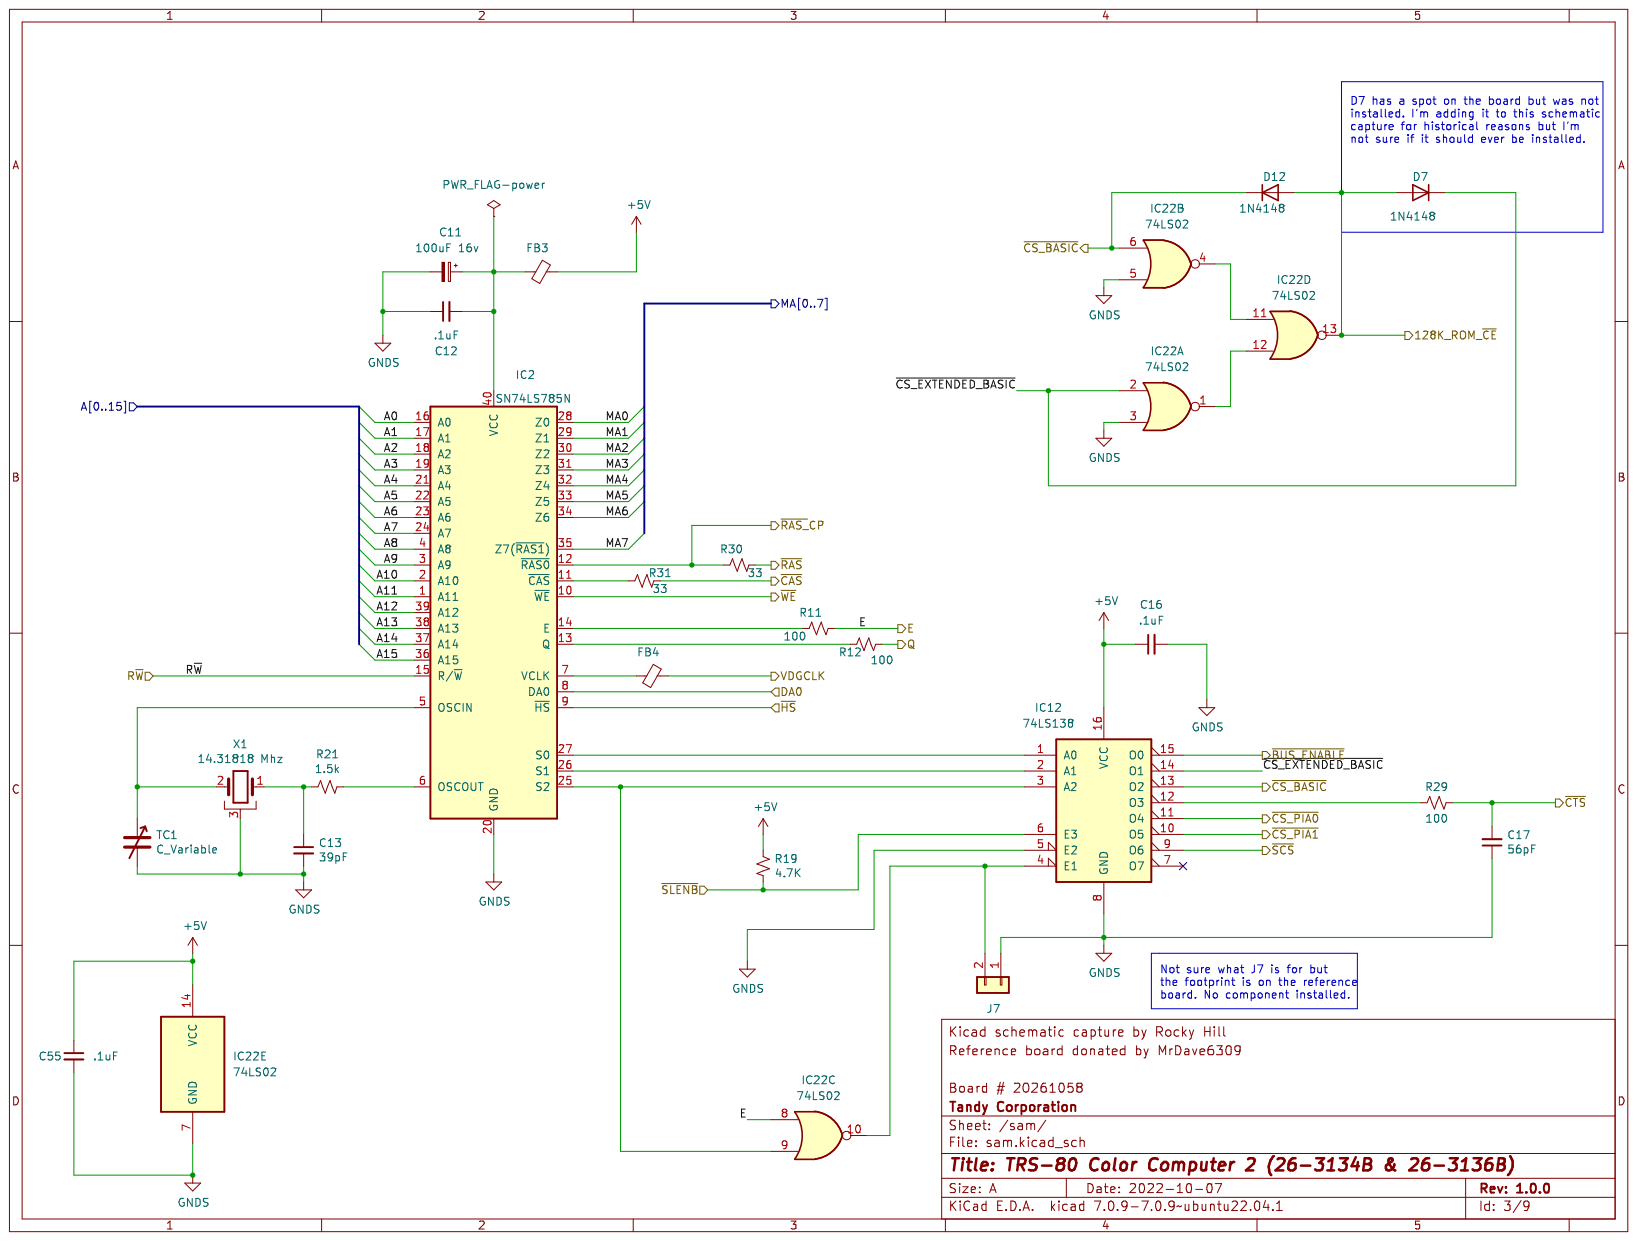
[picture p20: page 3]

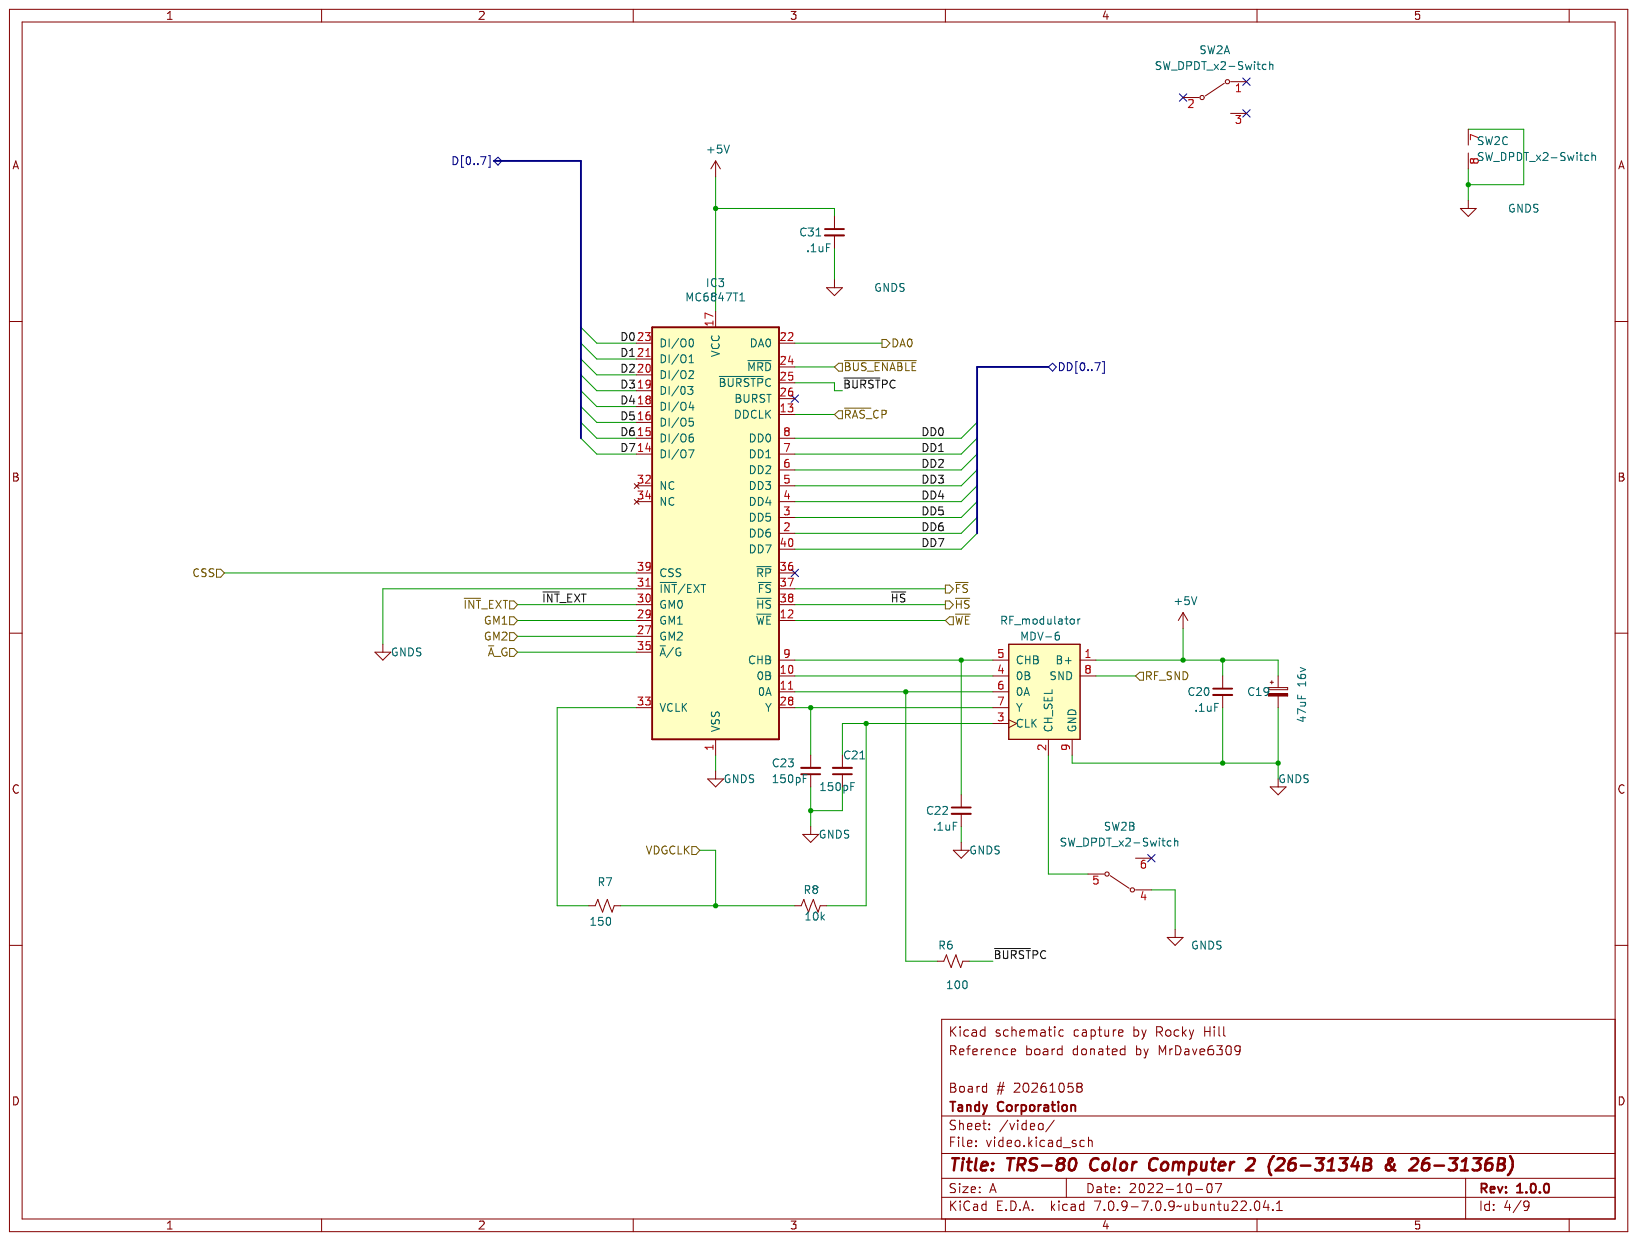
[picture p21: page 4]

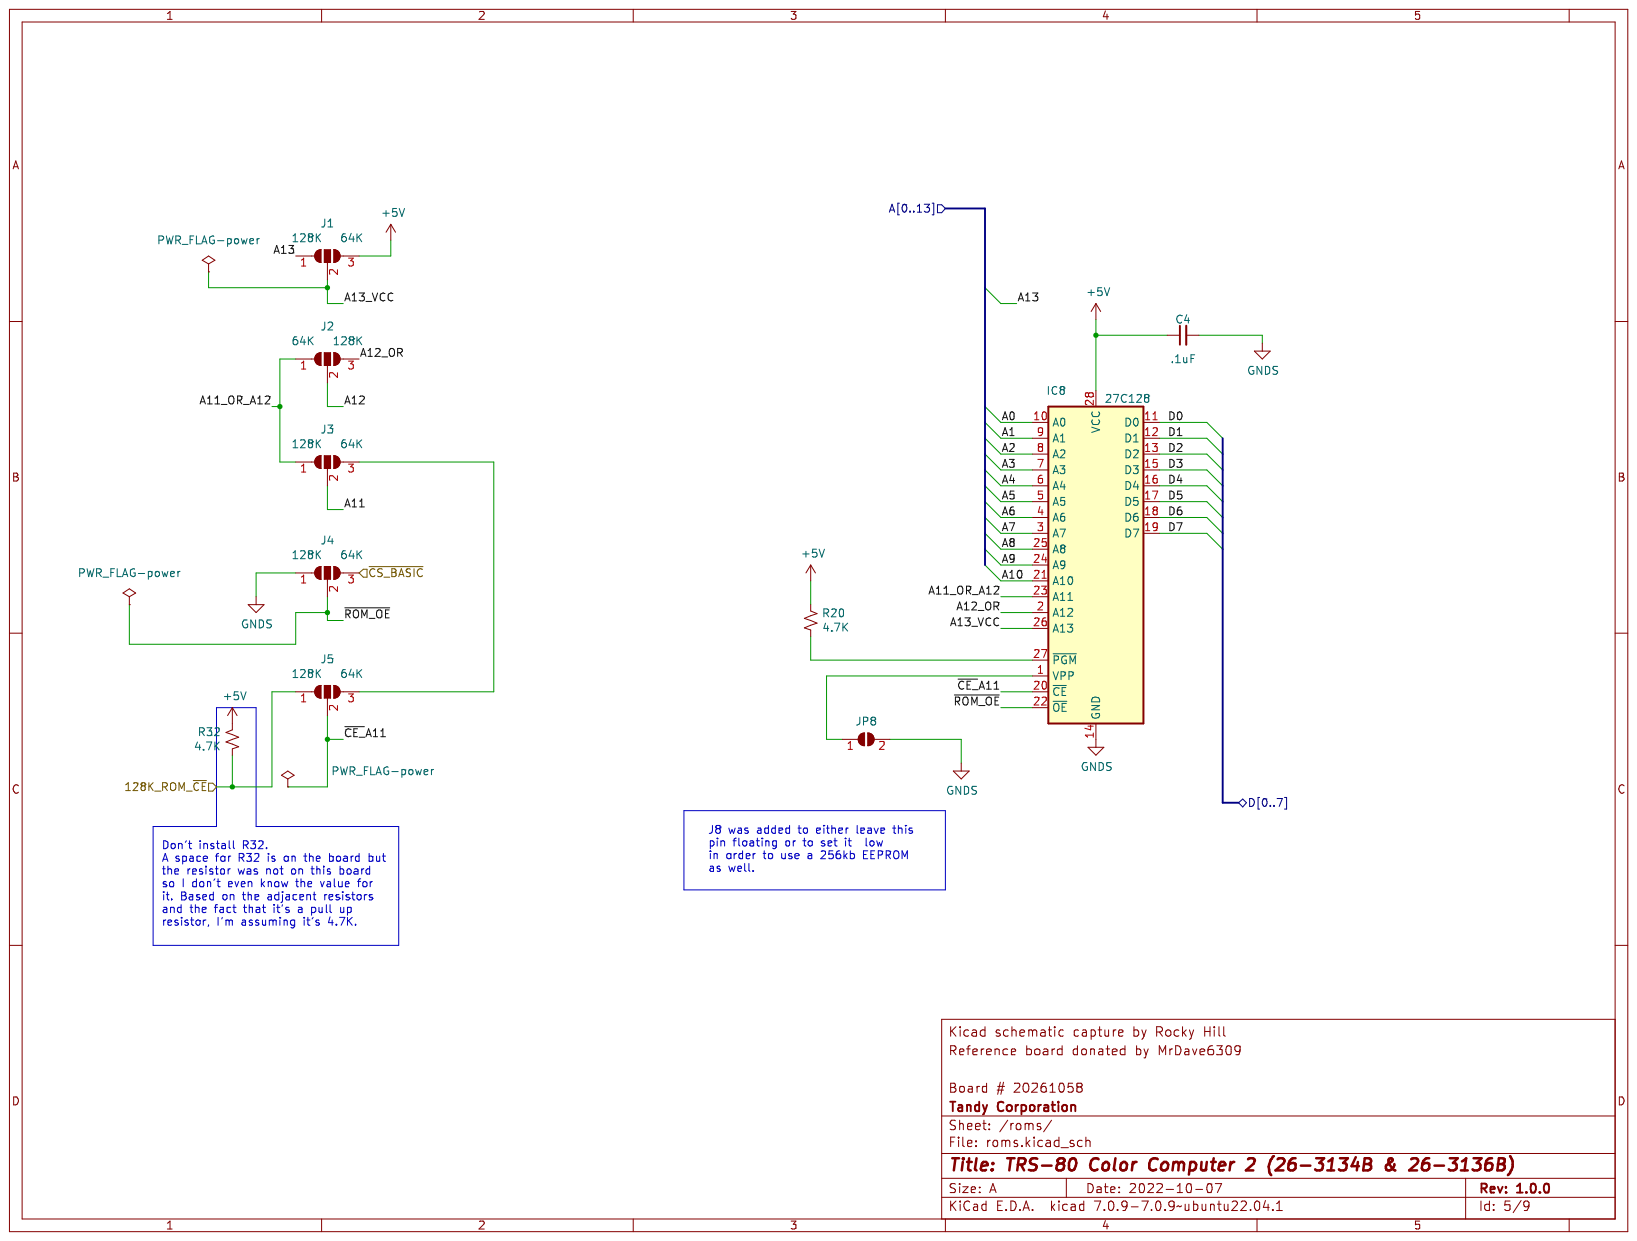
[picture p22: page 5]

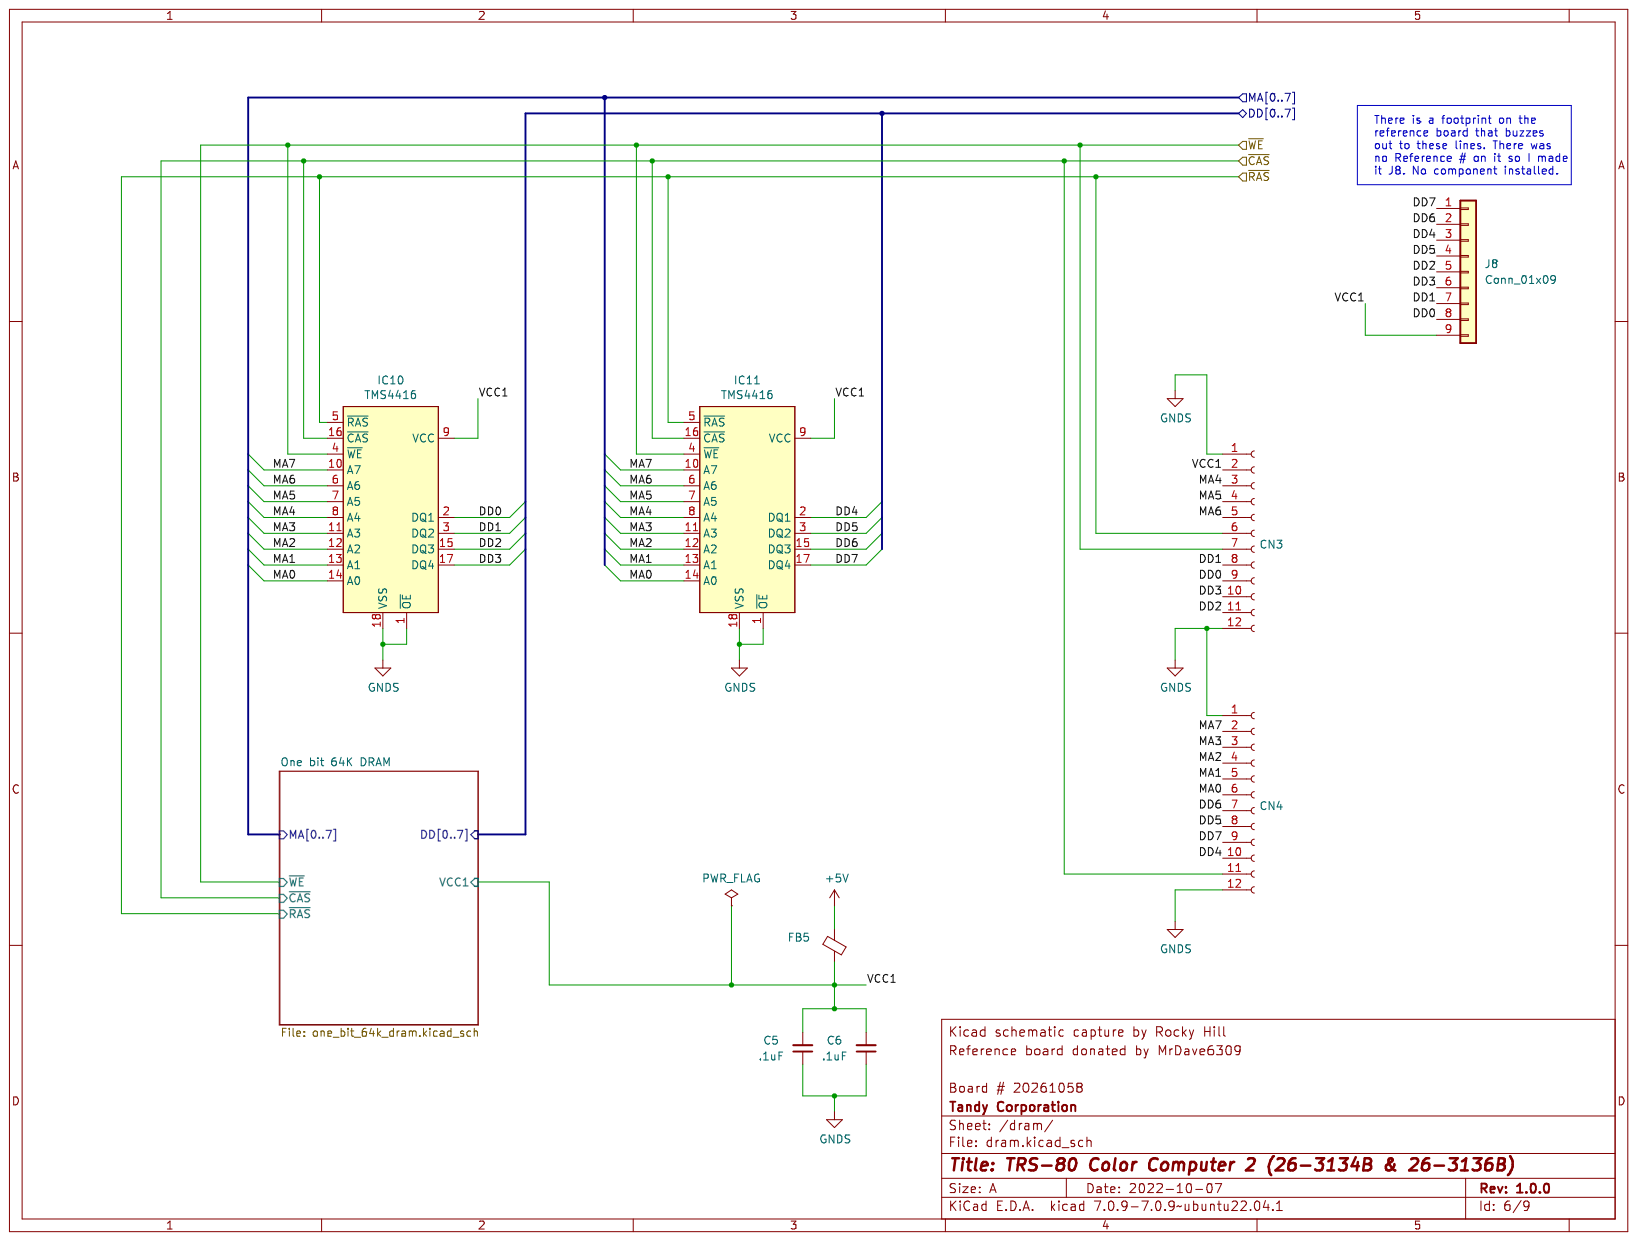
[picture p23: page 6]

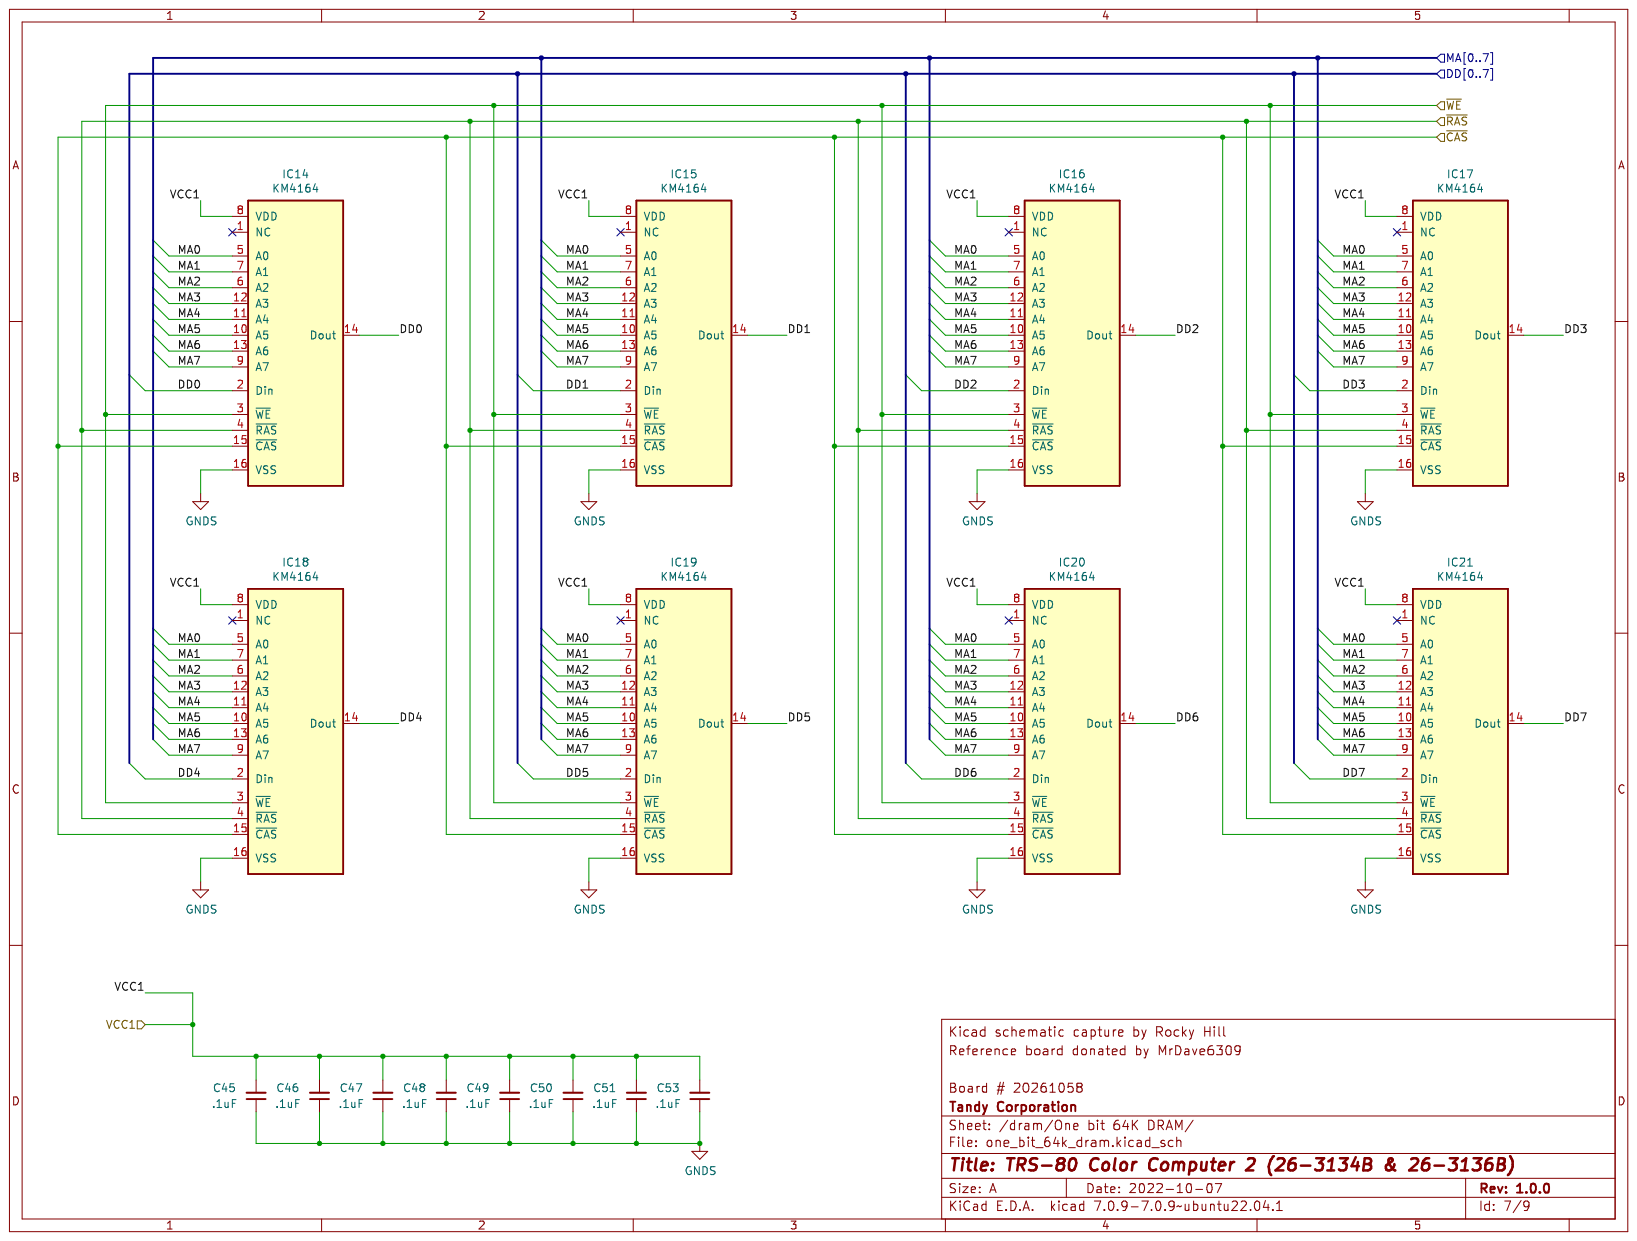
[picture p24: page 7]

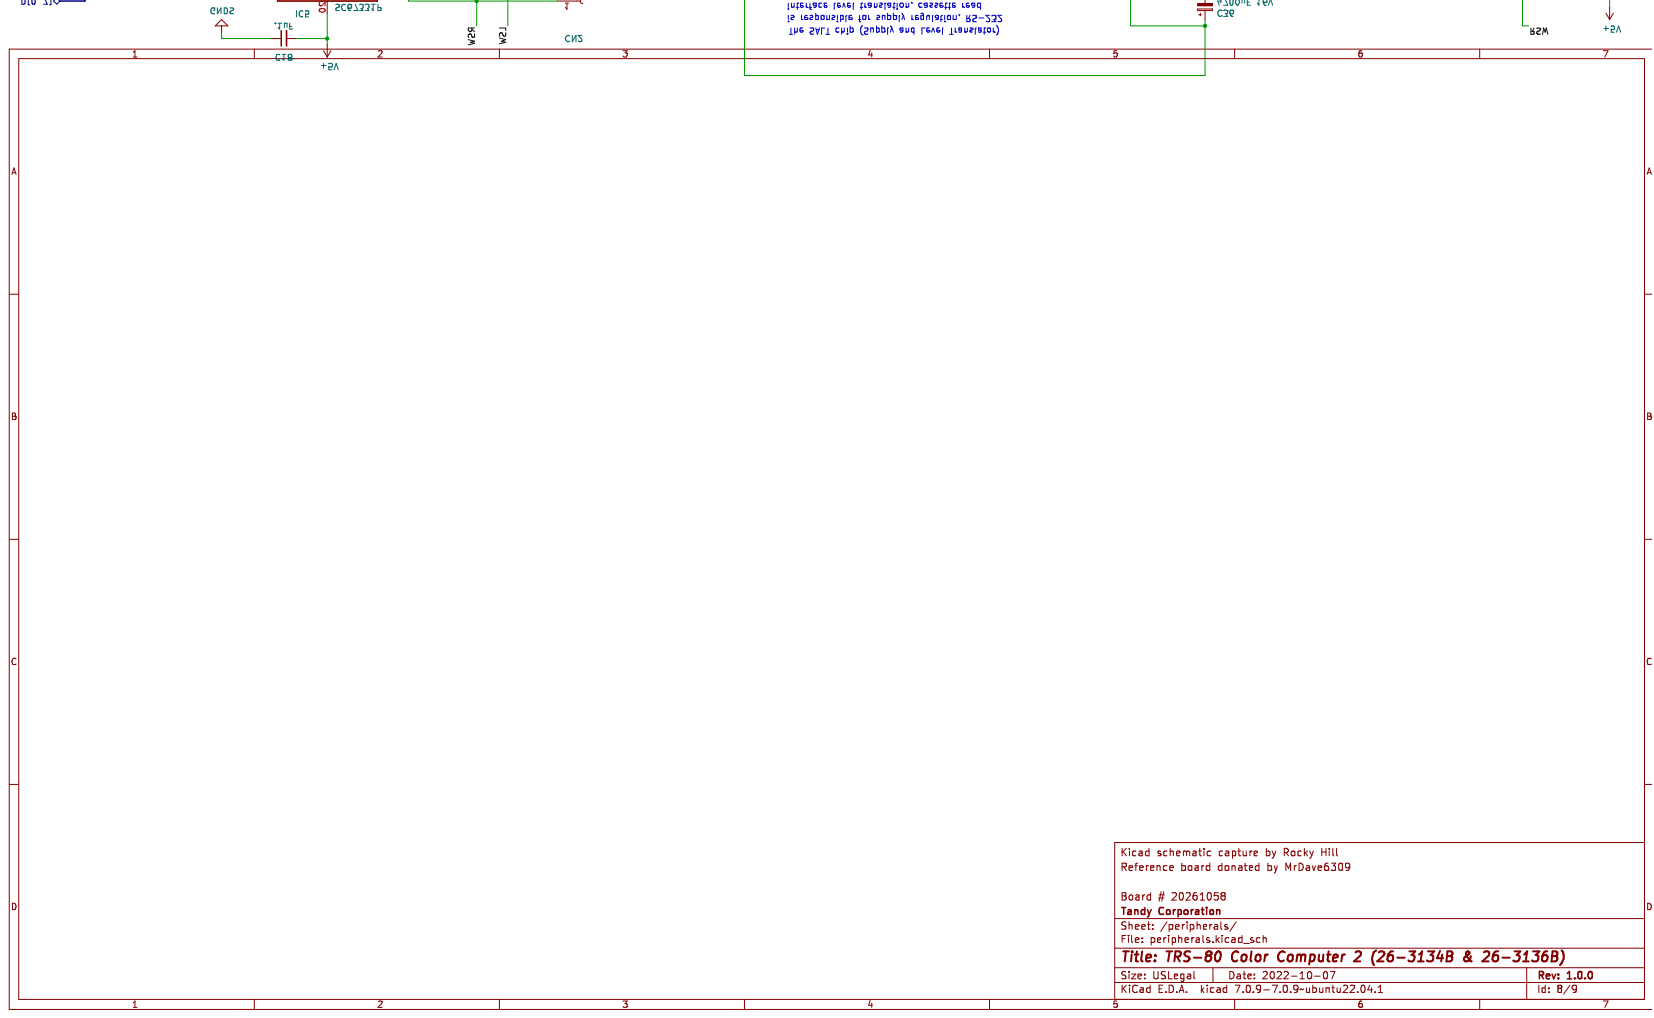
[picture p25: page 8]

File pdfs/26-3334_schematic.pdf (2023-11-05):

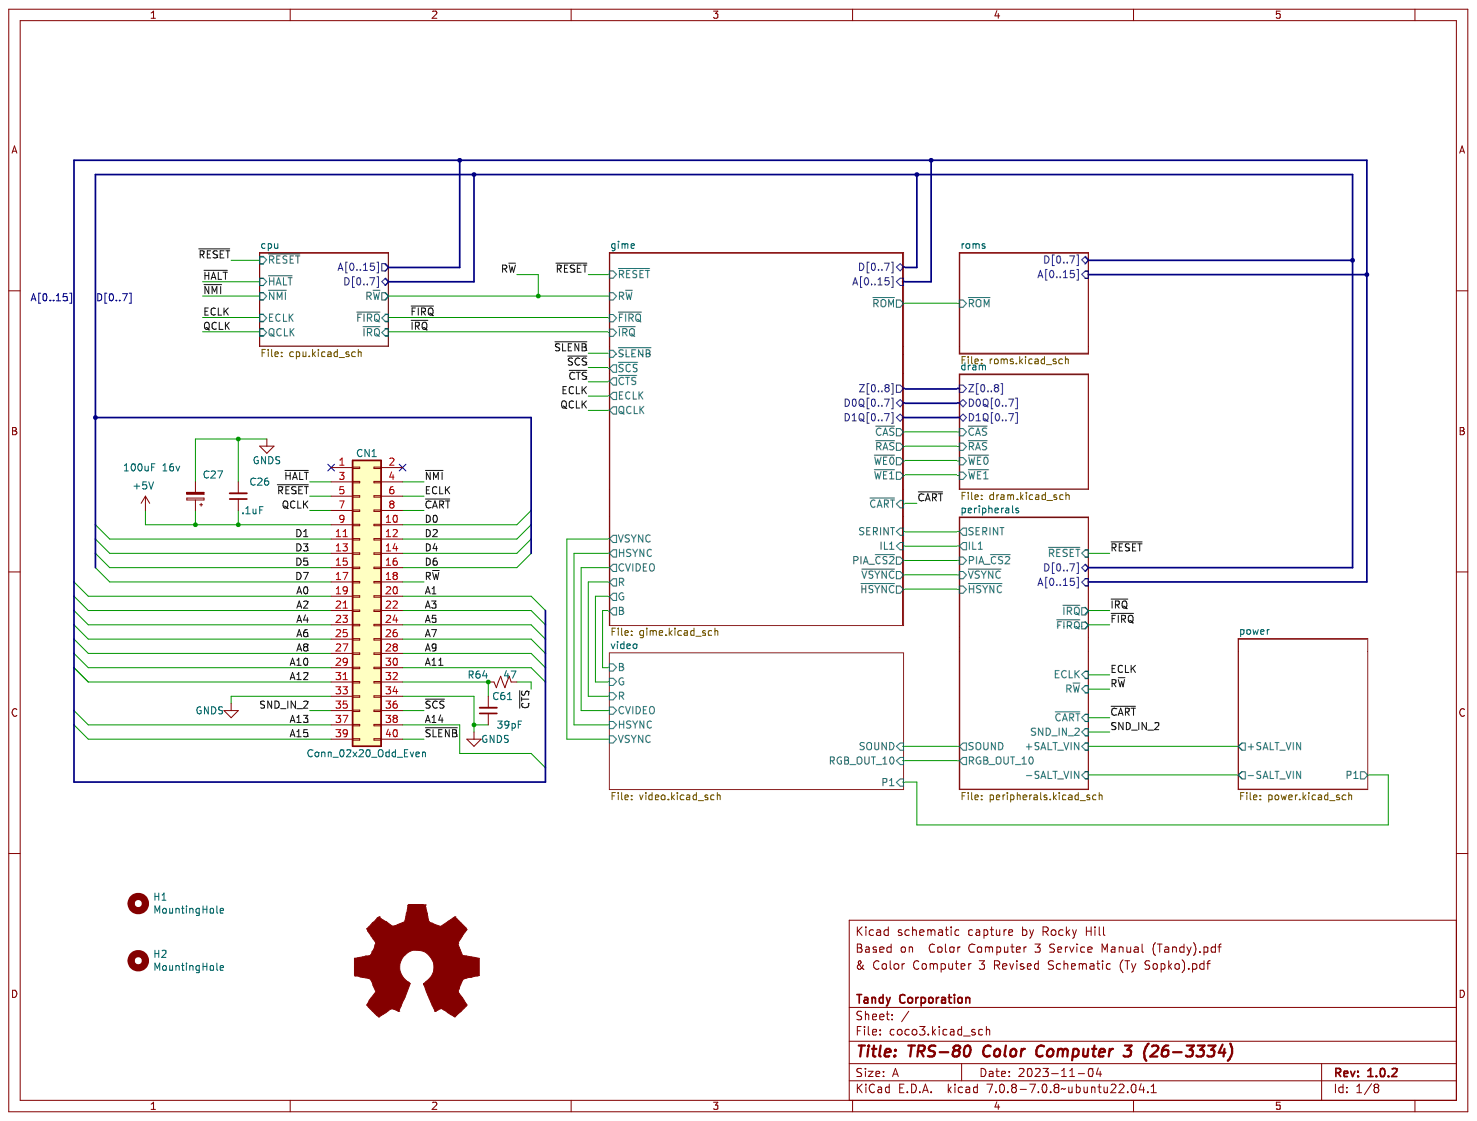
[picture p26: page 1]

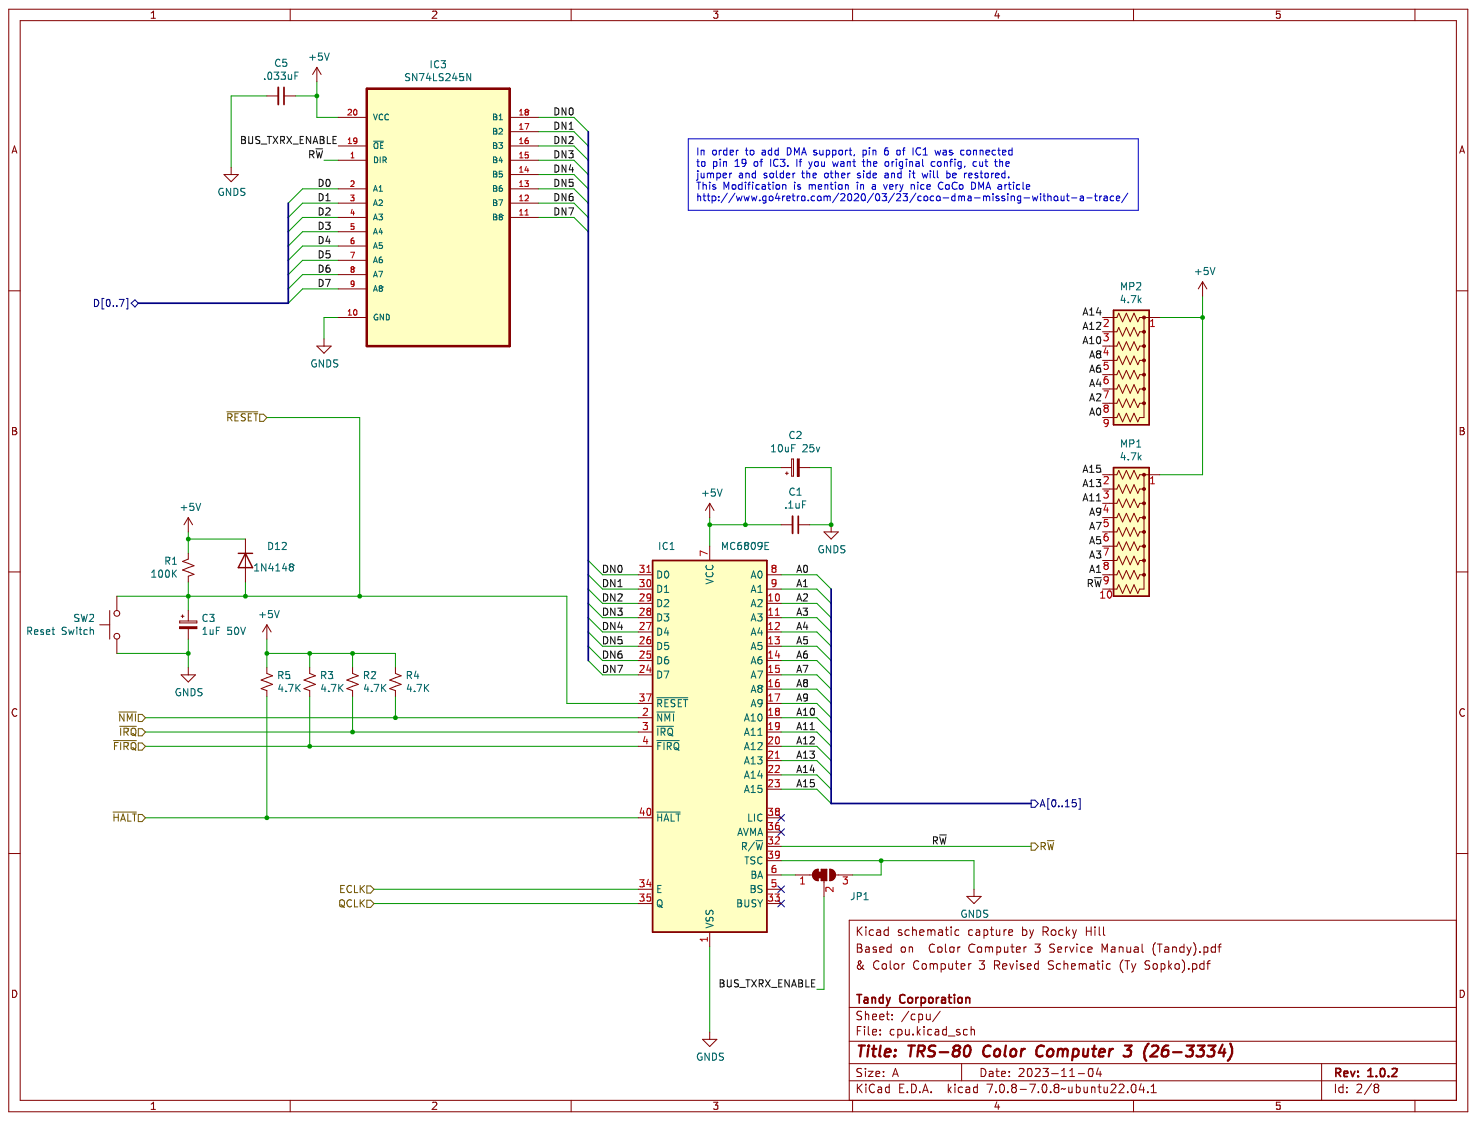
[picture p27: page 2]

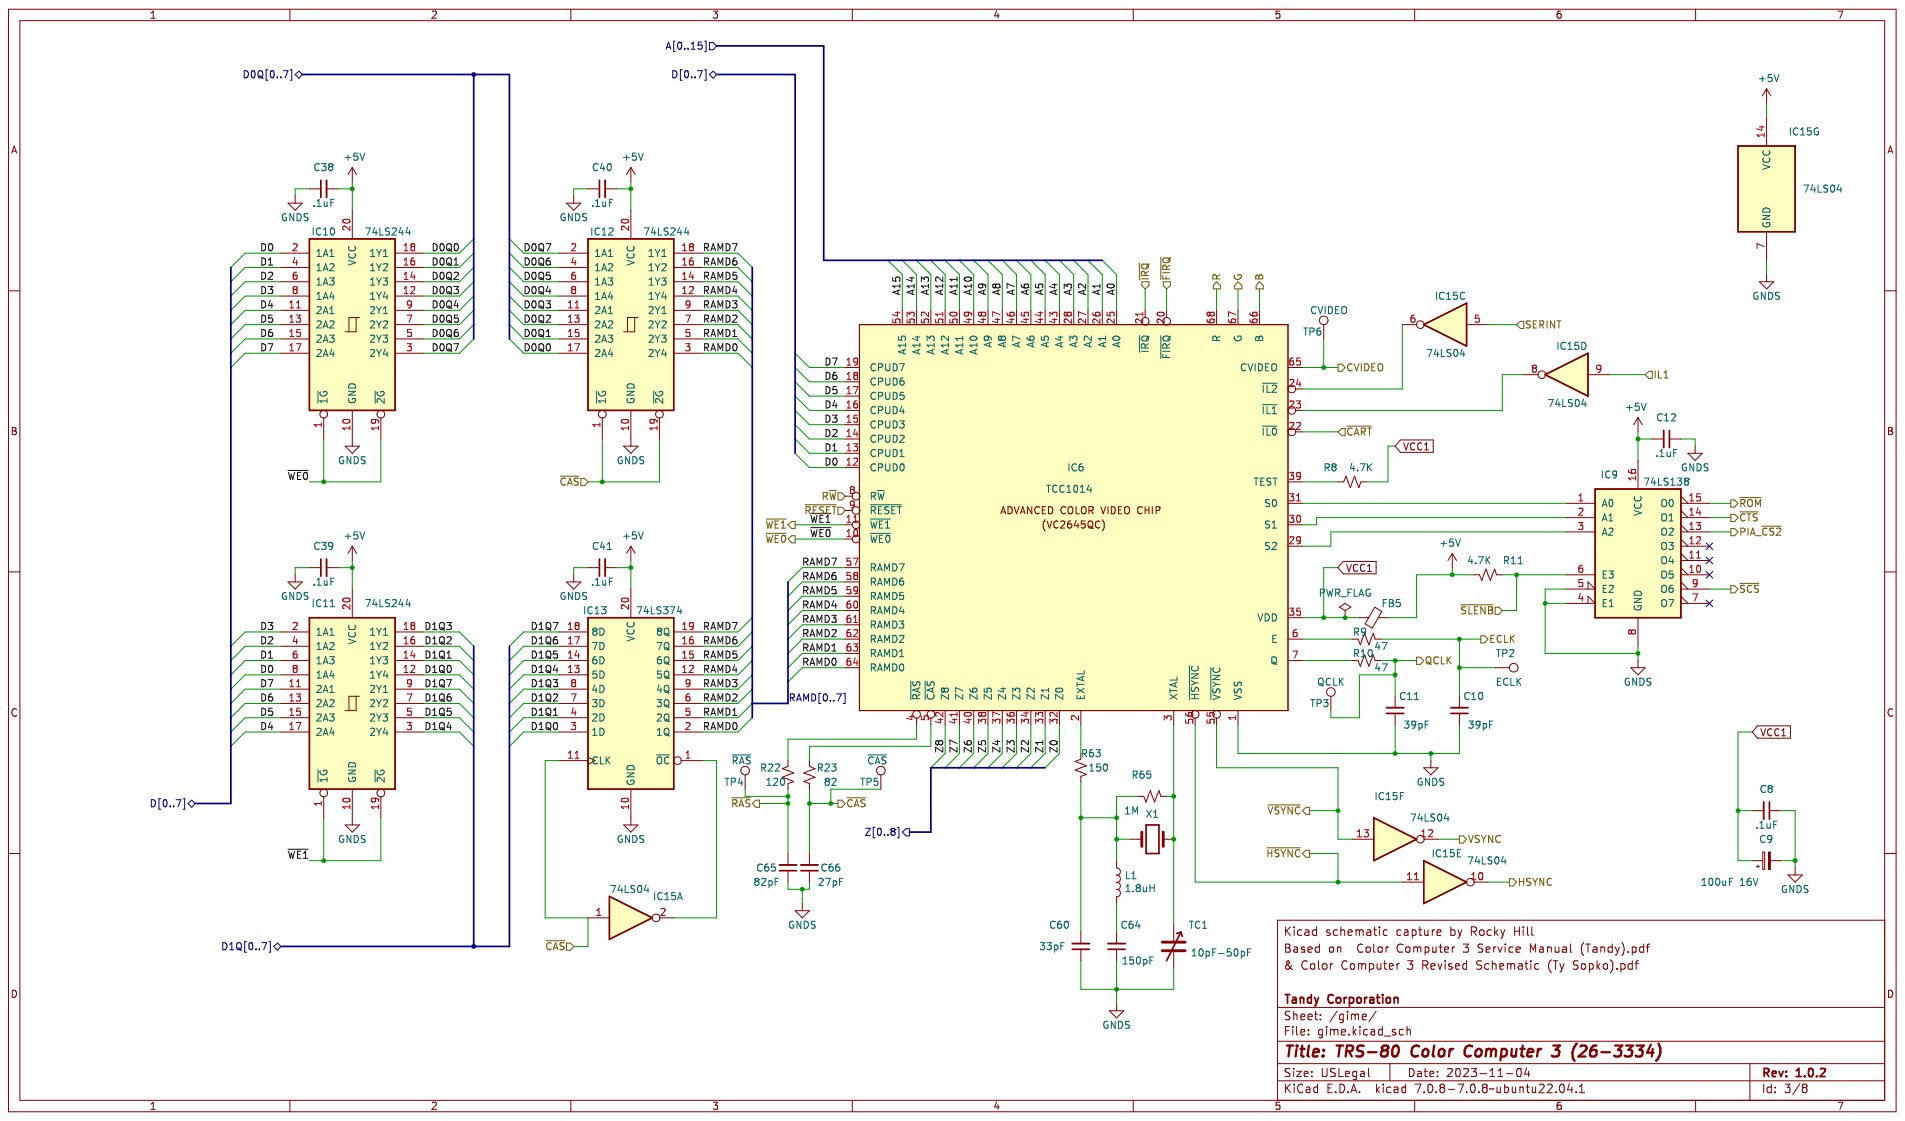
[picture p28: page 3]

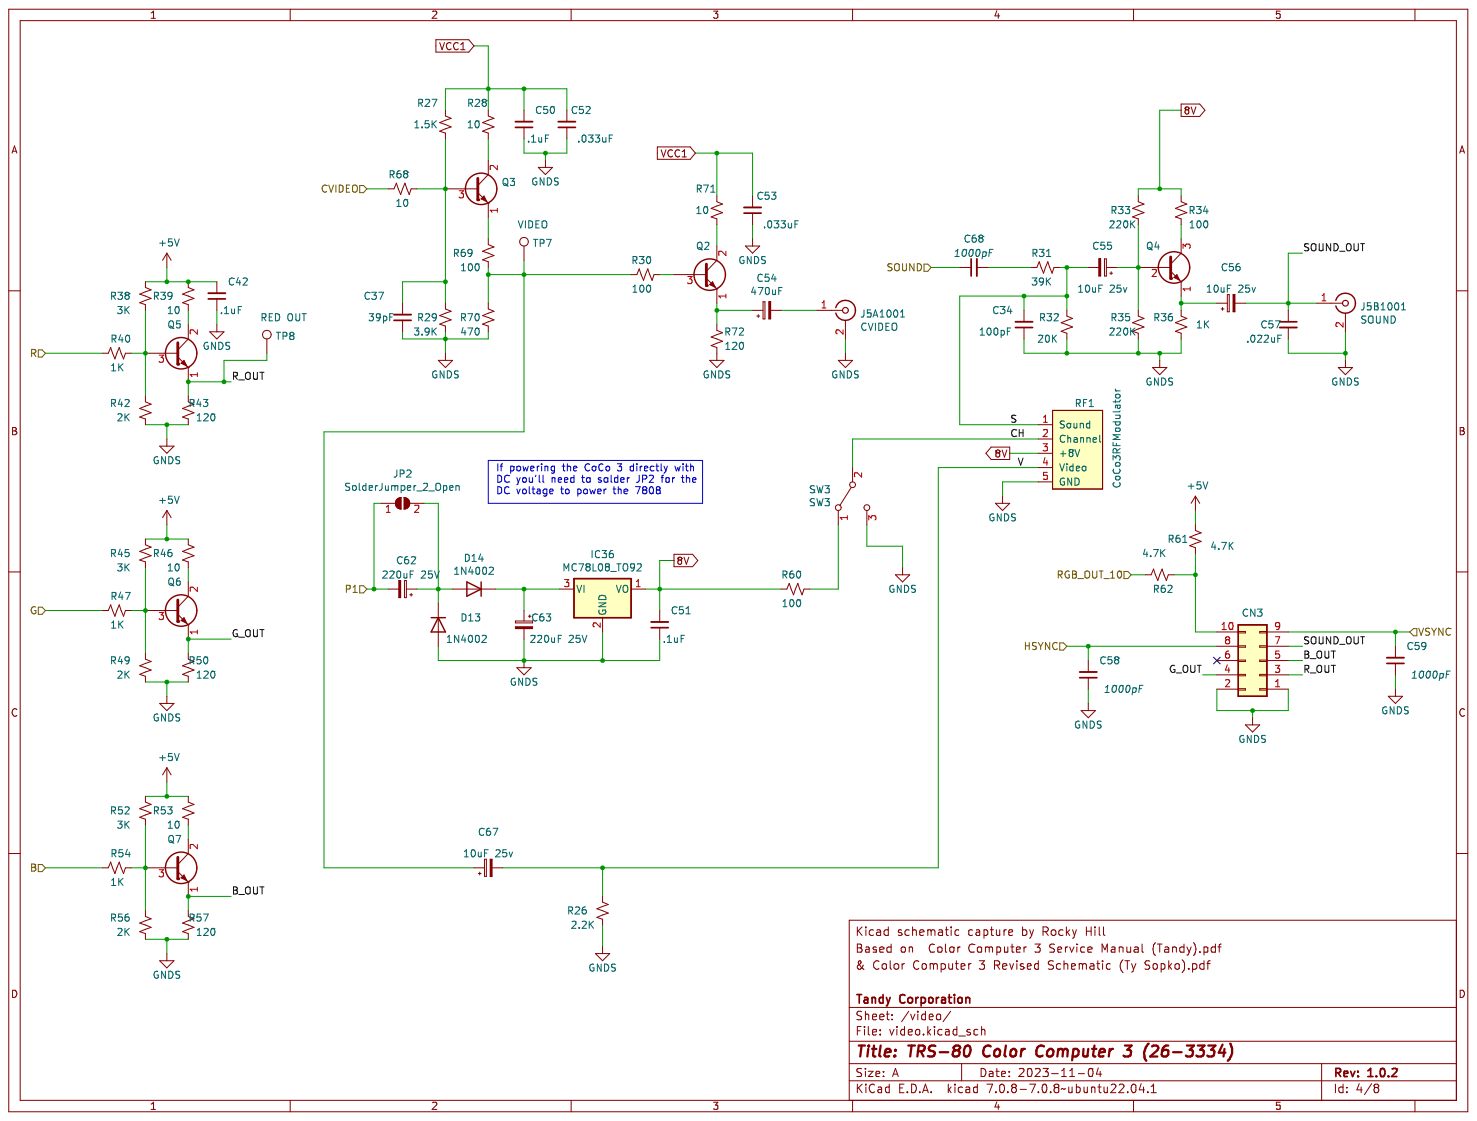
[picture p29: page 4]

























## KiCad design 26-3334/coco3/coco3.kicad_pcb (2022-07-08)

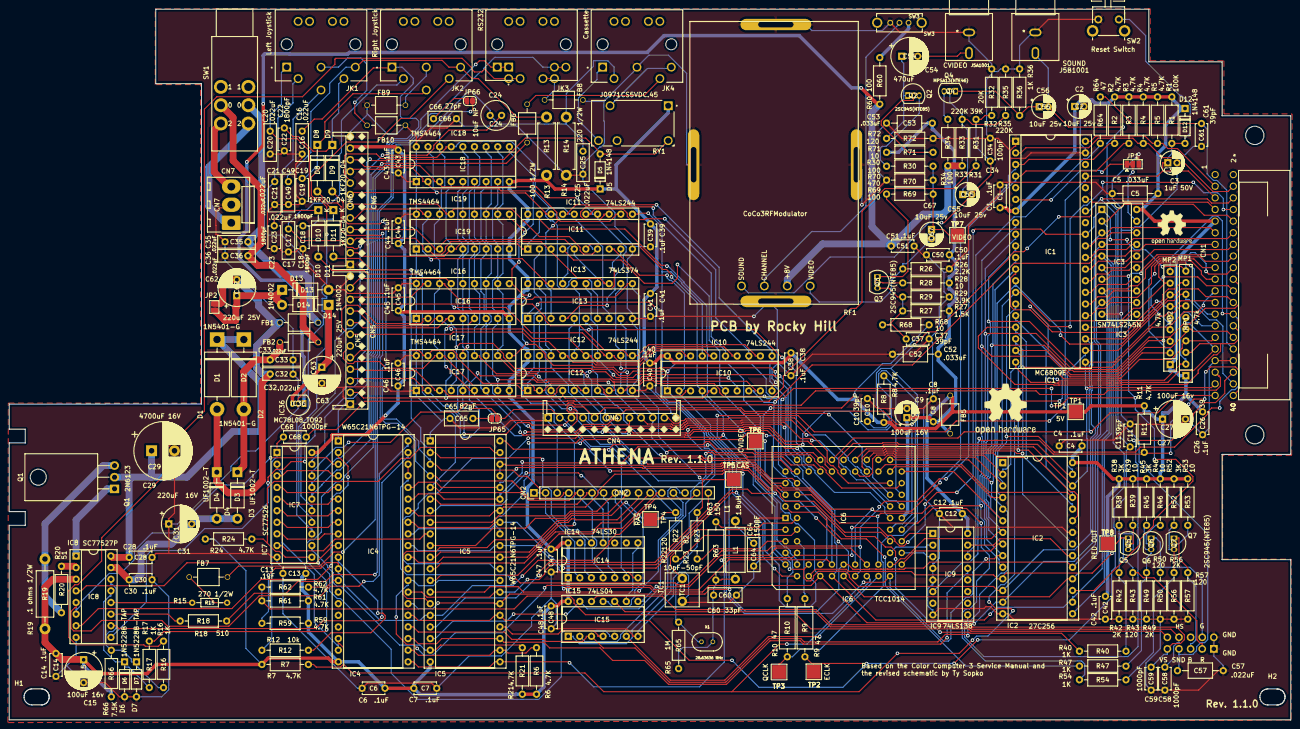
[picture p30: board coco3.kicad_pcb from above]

Board: 2 copper layers, 280.0 x 155.3 mm, 220 parts (1 on the bottom side), 219 nets.

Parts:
C1, C4, C6, C7, C8, C12, C13, C14, C26, C28, C30, C38, C39, C40, C41, C42, C43, C44, C45, C46, C47, C48, C50, C51: .1uF; C_Disc_D4.7mm_W2.5mm_P5.00mm
C2, C55, C56, C67: 10uF 25v; CP_Radial_D5.0mm_P2.00mm
C3: 1uF 50V; CP_Radial_D5.0mm_P2.00mm
C5, C52, C53: .033uF; C_Axial_L5.1mm_D3.1mm_P10.00mm_Horizontal
C9: 100uF 16V; CP_Radial_D5.0mm_P2.00mm
C10, C11, C37, C61: 39pF; C_Disc_D4.7mm_W2.5mm_P5.00mm
C15, C27: 100uF 16v; CP_Radial_D8.0mm_P5.00mm
C16, C17, C20, C21, C25, C32, C33, C35, C36, C49: .022uF; C_Disc_D8.0mm_W2.5mm_P5.00mm
C18, C19, C22, C23: 1800pF; C_Disc_D4.7mm_W2.5mm_P5.00mm
C24: 10uF NP; C_Radial_D6.3mm_H5.0mm_P2.50mm
C29: 4700uF 16V; CP_Radial_D12.5mm_P5.00mm
C31: 220uF 16V; CP_Radial_D8.0mm_P5.00mm
C34: 100pF; C_Disc_D4.3mm_W1.9mm_P5.00mm
C54: 470uF; CP_Radial_D8.0mm_P3.50mm
C57: .022uF; C_Axial_L5.1mm_D3.1mm_P10.00mm_Horizontal
C58, C59, C68: 1000pF; C_Disc_D4.7mm_W2.5mm_P5.00mm
C60: 33pF; C_Rect_L7.2mm_W3.0mm_P5.00mm_FKS2_FKP2_MKS2_MKP2
C62, C63: 220uF 25V; CP_Radial_D8.0mm_P3.50mm
C64: 150pF; C_Rect_L7.2mm_W2.5mm_P5.00mm_FKS2_FKP2_MKS2_MKP2
C65: 82pF; C_Rect_L7.2mm_W3.0mm_P5.00mm_FKS2_FKP2_MKS2_MKP2
C66: 27pF; C_Rect_L7.2mm_W3.0mm_P5.00mm_FKS2_FKP2_MKS2_MKP2
CN1: Conn_02x20_Odd_Even; EBC20DRAS
CN2: Conn_01x16_Female; PinHeader_1x16_P2.54mm_Vertical
CN3: Conn_02x05_Odd_Even; PinHeader_2x05_P2.54mm_Vertical
CN4, CN5, CN6: Conn_01x12_Female; PinSocket_1x12_P2.54mm_for_memory_board_adapter
CN7: Conn_01x03_Male; Molex_KK-396_A-41791-0003_1x03_P3.96mm_Vertical
D1, D2: 1N5401-G; D_DO-201AD_P15.24mm_Horizontal
D3, D4: UF1002-T; D_DO-41_SOD81_P10.16mm_Horizontal
D5, D12: 1N4148; D_DO-35_SOD27_P7.62mm_Horizontal
D6, D7: 1N5228B-TAP; D_DO-35_SOD27_P7.62mm_Horizontal
D8, D9, D10, D11: 1KF20-04; D_A-405_P10.16mm_Horizontal
D13, D14: 1N4002; D_DO-41_SOD81_P10.16mm_Horizontal
FB1, FB2, FB5, FB6, FB7, FB8, FB9, FB10: FB_28L0138-10R-10
H1, H2: MountingHole; MountingHole_3.5mm
H3: MountingHole; coco3_outline_and_layout
IC1: MC6809E; DIP-40_W15.24mm_Socket
IC2: 27C256; DIP-28_W15.24mm_Socket
IC3: SN74LS245N; DIP-20_W7.62mm_Socket
IC4, IC5: W65C21N6TPG-14; DIP-40_W15.24mm_Socket
IC6: TCC1014; PLCC-68_THT-Socket
IC7: SC77526; DIP-20_W7.62mm_Socket
IC8: SC77527P; DIP-16_W7.62mm_Socket
IC9: 74LS138; DIP-16_W7.62mm_Socket
IC10, IC11, IC12: 74LS244; DIP-20_W7.62mm_Socket
IC13: 74LS374; DIP-20_W7.62mm_Socket
IC14: 74LS30; DIP-14_W7.62mm_Socket
IC15: 74LS04; DIP-14_W7.62mm_Socket
IC16, IC17, IC18, IC19: TMS4464; DIP-18_W7.62mm_Socket
IC36: MC78L08_TO92; TO-92_Inline
J5A1001: CVIDEO; KLPX-0848A-2-R
J5B1001: SOUND; KLPX-0848A-2-R
JK1: Left Joystick; CUI_SDS-60J
JK2: Right Joystick; CUI_SDS-60J
JK3: RS232; CUI_SDS-40J
JK4: Cassette; CUI_SDS-50J
JP1: SolderJumper_3_Bridged12; SolderJumper-3_P1.3mm_Bridged12_Pad1.0x1.5mm
JP2: SolderJumper_2_Open; SolderJumper-2_P1.3mm_Open_Pad1.0x1.5mm
JP65, JP66: SolderJumper_2_Open; SolderJumper-2_P1.3mm_Open_RoundedPad1.0x1.5mm
L1: 1.8uH; L_Axial_L9.5mm_D4.0mm_P12.70mm_Horizontal_Fastron_SMCC
MP1: 4.7k; R_Array_SIP10
MP2: 4.7k; R_Array_SIP9
Q1: 2N6123; TO-220-3_Horizontal_TabDown
Q2, Q3, Q5, Q6, Q7: 2SC945(NTE85); TO-92L_Inline
Q4: MPSA13(NTE46); TO-92L_Inline
R1: 100K; R_Axial_DIN0207_L6.3mm_D2.5mm_P10.16mm_Horizontal
R2, R3, R4, R5, R6, R7, R8, R11, R21, R24, R59, R61, R62: 4.7K; R_Axial_DIN0207_L6.3mm_D2.5mm_P10.16mm_Horizontal
R9, R10: 47; R_Axial_DIN0309_L9.0mm_D3.2mm_P12.70mm_Horizontal
R12: 10k; R_Axial_DIN0207_L6.3mm_D2.5mm_P10.16mm_Horizontal
R13: 100 1/2W; R_Axial_DIN0411_L9.9mm_D3.6mm_P12.70mm_Horizontal
R14: 220 1/2W; R_Axial_DIN0411_L9.9mm_D3.6mm_P12.70mm_Horizontal
R15: 270 1/2W; R_Axial_DIN0204_L3.6mm_D1.6mm_P7.62mm_Horizontal
R16, R17, R36, R40, R47, R54: 1K; R_Axial_DIN0207_L6.3mm_D2.5mm_P10.16mm_Horizontal
R18: 510; R_Axial_DIN0207_L6.3mm_D2.5mm_P10.16mm_Horizontal
R19: .1 ohms 1/2W; R_Axial_DIN0411_L9.9mm_D3.6mm_P15.24mm_Horizontal
R20: 51; R_Axial_DIN0207_L6.3mm_D2.5mm_P10.16mm_Horizontal
R22, R43, R50, R57, R72: 120; R_Axial_DIN0207_L6.3mm_D2.5mm_P10.16mm_Horizontal
R23: 82; R_Axial_DIN0207_L6.3mm_D2.5mm_P10.16mm_Horizontal
R26: 2.2K; R_Axial_DIN0207_L6.3mm_D2.5mm_P10.16mm_Horizontal
R27: 1.5K; R_Axial_DIN0207_L6.3mm_D2.5mm_P10.16mm_Horizontal
R28, R39, R46, R53, R68, R71: 10; R_Axial_DIN0207_L6.3mm_D2.5mm_P10.16mm_Horizontal
R29: 3.9K; R_Axial_DIN0207_L6.3mm_D2.5mm_P10.16mm_Horizontal
R30, R34, R60, R69: 100; R_Axial_DIN0207_L6.3mm_D2.5mm_P10.16mm_Horizontal
R31: 39K; R_Axial_DIN0207_L6.3mm_D2.5mm_P10.16mm_Horizontal
R32: 20K; R_Axial_DIN0207_L6.3mm_D2.5mm_P10.16mm_Horizontal
R33, R35: 220K; R_Axial_DIN0207_L6.3mm_D2.5mm_P10.16mm_Horizontal
R38, R45, R52: 3K; R_Axial_DIN0207_L6.3mm_D2.5mm_P10.16mm_Horizontal
R42, R49, R56: 2K; R_Axial_DIN0207_L6.3mm_D2.5mm_P10.16mm_Horizontal
R63: 150; R_Axial_DIN0309_L9.0mm_D3.2mm_P12.70mm_Horizontal
R64: 47; R_Axial_DIN0207_L6.3mm_D2.5mm_P10.16mm_Horizontal
R65: 1M; R_Axial_DIN0207_L6.3mm_D2.5mm_P10.16mm_Horizontal
R66: 7.5K; R_Axial_DIN0207_L6.3mm_D2.5mm_P10.16mm_Horizontal
R70: 470; R_Axial_DIN0207_L6.3mm_D2.5mm_P10.16mm_Horizontal
REF1: OSHW-Logo2_9.8x8mm_SilkScreen
REF2: OSHW-Logo2_14.6x12mm_SilkScreen
RF1: CoCo3RFModulator; CoCo 3 RF Modulator
RY1: J0971CS5VDC.45; RELAY_J0971CS5VDC.45
SW1: SW_DPDT_x2; F2UEE
SW2: Reset Switch; B3F3152
SW3: SW3; SW_EG1213
TC1: 10pF-50pF; C_Rect_L7.2mm_W7.2mm_P5.00mm_FKS2_FKP2_MKS2_MKP2
TP1: 5V; TestPoint_Pad_3.0x3.0mm
TP2: ECLK; TestPoint_Pad_3.0x3.0mm
TP3: QCLK; TestPoint_Pad_3.0x3.0mm
TP4: ~RAS; TestPoint_Pad_3.0x3.0mm
TP5: ~CAS; TestPoint_Pad_3.0x3.0mm
TP6: CVIDEO; TestPoint_Pad_3.0x3.0mm
TP7: VIDEO; TestPoint_Pad_3.0x3.0mm
TP8: RED OUT; TestPoint_Pad_3.0x3.0mm
X1: 28.63636 MHz; XTAL_ECS-286.3-20-46X

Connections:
8V: C51.2, IC36.1, R33.1, R34.2, R60.1, RF1.3
+5V: C1.2, C2.1, C4.1, C5.1, C6.2, C7.2, C12.2, C13.2, C14.2, C15.1, C26.1, C27.1, C38.2, C39.2, C40.2, C41.2, C42.2, C43.2, C44.2, C45.2, C46.2, C47.2, C48.2, CN1.9, CN6.11, D5.1, D12.1, FB5.2, IC1.7, IC2.28, IC3.20, IC4.20, IC5.20, IC7.20, IC8.3, IC9.16, IC10.20, IC11.20, IC12.20, IC13.20, IC14.1, IC14.14, IC15.14, IC16.9, IC17.9, IC18.9, IC19.9, MP1.1, MP2.1, R1.1, R2.1, R3.1, R4.1, R5.1, R6.1, R7.1, R8.2, R11.2, R13.1, R19.1, R21.2, R24.2, R38.2, R39.2, R45.2, R46.2, R52.2, R53.2, R59.1, R61.1, R66.2, RY1.A1, TP1.1
/A0: CN1.19, IC1.8, IC2.10, IC4.36, IC5.36, IC6.25, MP2.2
/A1: CN1.20, IC1.9, IC2.9, IC4.35, IC5.35, IC6.26, MP2.3
/A2: CN1.21, IC1.10, IC2.8, IC6.27, MP2.4
/A3: CN1.22, IC1.11, IC2.7, IC6.28, MP2.5
/A4: CN1.23, IC1.12, IC2.6, IC6.43, MP2.6
/A5: CN1.24, IC1.13, IC2.5, IC4.24, IC6.44, IC15.3, MP2.7
/A6: CN1.25, IC1.14, IC2.4, IC6.45, MP2.8
/A7: CN1.26, IC1.15, IC2.3, IC6.46, MP2.9
/A8: CN1.27, IC1.16, IC2.25, IC6.47, MP1.2
/A9: CN1.28, IC1.17, IC2.24, IC6.48, MP1.3
/A10: CN1.29, IC1.18, IC2.21, IC6.49, MP1.4
/A11: CN1.30, IC1.19, IC2.23, IC6.50, MP1.5
/A12: CN1.31, IC1.20, IC2.2, IC6.51, MP1.6
/A13: CN1.37, IC1.21, IC2.26, IC6.52, MP1.7
/A14: CN1.38, IC1.22, IC2.27, IC6.53, MP1.8
/A15: CN1.39, IC1.23, IC6.54, MP1.9
/D0: CN1.10, IC2.11, IC3.2, IC4.33, IC5.33, IC6.12, IC10.2, IC11.8
/D1: CN1.11, IC2.12, IC3.3, IC4.32, IC5.32, IC6.13, IC10.4, IC11.6
/D2: CN1.12, IC2.13, IC3.4, IC4.31, IC5.31, IC6.14, IC10.6, IC11.4
/D3: CN1.13, IC2.15, IC3.5, IC4.30, IC5.30, IC6.15, IC10.8, IC11.2
/D4: CN1.14, IC2.16, IC3.6, IC4.29, IC5.29, IC6.16, IC10.11, IC11.17
/D5: CN1.15, IC2.17, IC3.7, IC4.28, IC5.28, IC6.17, IC10.13, IC11.15
/D6: CN1.16, IC2.18, IC3.8, IC4.27, IC5.27, IC6.18, IC10.15, IC11.13
/D7: CN1.17, IC2.19, IC3.9, IC4.26, IC5.26, IC6.19, IC10.17, IC11.11
/ECLK: C11.2, CN1.6, IC1.34, IC4.25, IC5.25, R9.1, TP2.1
/QCLK: C10.2, CN1.7, IC1.35, R10.1, TP3.1
/R~W: CN1.18, IC1.32, IC3.1, IC4.21, IC5.21, IC6.8, MP1.10
/SND_IN_2: CN1.35, IC7.18
/cpu/BUS_TXRX_ENABLE: IC3.19, JP1.2
/cpu/DN0: IC1.31, IC3.18
/cpu/DN1: IC1.30, IC3.17
/cpu/DN2: IC1.29, IC3.16
/cpu/DN3: IC1.28, IC3.15
/cpu/DN4: IC1.27, IC3.14
/cpu/DN5: IC1.26, IC3.13
/cpu/DN6: IC1.25, IC3.12
/cpu/DN7: IC1.24, IC3.11
/dram/D0Q0: CN5.7, IC10.18, IC12.17, IC16.2
/dram/D0Q1: CN5.9, IC10.16, IC12.15, IC16.3
/dram/D0Q2: CN5.11, IC10.14, IC12.13, IC16.15
/dram/D0Q3: CN5.10, IC10.12, IC12.11, IC16.17
/dram/D0Q4: CN5.3, IC10.9, IC12.8, IC17.2
/dram/D0Q5: CN5.4, IC10.7, IC12.6, IC17.3
/dram/D0Q6: CN5.2, IC10.5, IC12.4, IC17.15
/dram/D0Q7: CN5.5, IC10.3, IC12.2, IC17.17
/dram/D1Q0: CN6.9, IC11.12, IC13.3, IC18.2
/dram/D1Q1: CN6.10, IC11.14, IC13.4, IC18.3
/dram/D1Q2: CN6.8, IC11.16, IC13.7, IC18.15
/dram/D1Q3: CN6.7, IC11.18, IC13.8, IC18.17
/dram/D1Q4: CN6.3, IC11.3, IC13.13, IC19.2
/dram/D1Q5: CN6.4, IC11.5, IC13.14, IC19.3
/dram/D1Q6: CN6.6, IC11.7, IC13.17, IC19.15
/dram/D1Q7: CN6.5, IC11.9, IC13.18, IC19.17
/dram/Z0: CN4.3, IC6.32, IC16.14, IC17.14, IC18.14, IC19.14
/dram/Z1: CN4.4, IC6.33, IC16.13, IC17.13, IC18.13, IC19.13
/dram/Z2: CN4.5, IC6.34, IC16.12, IC17.12, IC18.12, IC19.12
/dram/Z3: CN4.6, IC6.36, IC16.11, IC17.11, IC18.11, IC19.11
/dram/Z4: CN4.9, IC6.37, IC16.8, IC17.8, IC18.8, IC19.8
/dram/Z5: CN4.8, IC6.38, IC16.7, IC17.7, IC18.7, IC19.7
/dram/Z6: CN4.7, IC6.40, IC16.6, IC17.6, IC18.6, IC19.6
/dram/Z7: CN4.10, IC6.41, IC16.10, IC17.10, IC18.10, IC19.10
/dram/Z8: CN4.11, IC6.42
/dram/~CAS: CN5.6, IC12.1, IC12.19, IC13.11, IC15.1, IC16.16, IC17.16, IC18.16, IC19.16, JP66.1, R23.1, TP5.1
/dram/~RAS: CN4.2, IC16.5, IC17.5, IC18.5, IC19.5, JP65.1, R22.1, TP4.1
/dram/~WE0: CN5.8, IC6.10, IC10.1, IC10.19, IC16.4, IC17.4
/dram/~WE1: CN6.2, IC6.11, IC11.1, IC11.19, IC18.4, IC19.4
/gime/B: IC6.66, R54.2
/gime/CVIDEO: IC6.65, R68.1, TP6.1
/gime/G: IC6.67, R47.2
/gime/HSYNC: C58.2, CN3.8, IC15.10
/gime/IL1: IC14.8, IC15.9
/gime/PIA_~CS2: IC4.23, IC5.23, IC9.13
/gime/R: IC6.68, R40.2
/gime/RAMD0: IC6.64, IC12.3, IC13.2
/gime/RAMD1: IC6.63, IC12.5, IC13.5
/gime/RAMD2: IC6.62, IC12.7, IC13.6
/gime/RAMD3: IC6.61, IC12.9, IC13.9
/gime/RAMD4: IC6.60, IC12.12, IC13.12
/gime/RAMD5: IC6.59, IC12.14, IC13.15
/gime/RAMD6: IC6.58, IC12.16, IC13.16
/gime/RAMD7: IC6.57, IC12.18, IC13.19
/gime/SERINT: IC4.10, IC8.4, IC15.5
/gime/VSYNC: C59.2, CN3.9, IC15.12
/gime/~HSYNC: IC5.40, IC6.56, IC15.11
/gime/~ROM: IC2.20, IC9.15
/gime/~VSYNC: IC5.18, IC6.55, IC15.13
/peripherals/+SALT_VIN: C28.1, C29.1, D1.1, D2.1, IC8.16, Q1.2
/peripherals/-SALT_VIN: C30.2, C31.2, D3.2, D4.2, IC8.15
/peripherals/CASS_DATA_IN: C24.1, C25.2, JK4.4, R14.2, R18.1
/peripherals/CASS_DATA_OUT_TTL: IC4.2, IC8.7
/peripherals/CASS_MTR_OUT: D5.2, IC8.9, RY1.A2
/peripherals/CASS_M_IN_TTL: IC4.39, IC8.10
/peripherals/CD_IN: D6.1, IC8.13, R17.1
/peripherals/CD_OUT_TTL: IC4.40, IC8.5
/peripherals/HI: IC4.22, IC5.22, R6.2
/peripherals/JOY0: C16.1, IC7.16, JK2.1
/peripherals/JOY1: C17.2, IC7.15, JK2.2
/peripherals/JOY2: C20.1, IC7.14, JK1.1
/peripherals/JOY3: C21.2, IC7.13, JK1.2
/peripherals/KR1: CN2.1, D11.2, IC5.2, IC14.3
/peripherals/KR2: CN2.2, D9.2, IC5.3, IC14.2
/peripherals/KR3: CN2.4, D8.2, IC5.4, IC14.12
/peripherals/KR4: CN2.5, D10.2, IC5.5, IC14.4
/peripherals/KR5: CN2.6, IC5.6, IC14.11
/peripherals/KR6: CN2.7, IC5.7, IC14.5
/peripherals/KR7: CN2.8, IC5.8, IC14.6
/peripherals/PA7: IC5.9, IC7.9
/peripherals/RGB_OUT_10: IC4.13, R62.1
/peripherals/SELA: IC5.39, IC7.11, R24.1
/peripherals/SELB: IC5.19, IC7.12, R21.1
/peripherals/SERIAL_DATA_IN: D7.1, IC8.14, R16.2, R66.1
/peripherals/SER_DATA_IN_TTL: IC4.3, IC8.6
/peripherals/SER_DATA_OUT: IC8.12, R15.2
/peripherals/SOUND: C68.1, IC7.1, R12.1
/power/P1: C32.1, C62.2, D1.2, D4.1, FB1.2, JP2.1
/video/B_OUT: CN3.5, Q7.1, R57.2
/video/CH: RF1.2, SW3.2
/video/G_OUT: CN3.4, Q6.1, R50.2
/video/R_OUT: CN3.3, Q5.1, R43.2, TP8.1
/video/S: C34.2, C55.2, R31.2, R32.1, RF1.1
/video/SOUND_OUT: C56.2, C57.1, CN3.7, J5B1001.1
/video/V: C67.2, R26.2, RF1.4
/~CART: CN1.8, IC4.18, IC6.22, R7.2
/~CTS: IC9.14, R64.1
/~FIRQ: IC1.4, IC4.37, IC4.38, IC6.20, R3.2
/~HALT: CN1.3, IC1.40, R5.2
/~IRQ: IC1.3, IC5.37, IC5.38, IC6.21, R2.2
/~NMI: CN1.4, IC1.2, R4.2
/~RESET: C3.1, CN1.5, D12.2, IC1.37, IC4.34, IC5.34, IC6.9, R1.2, SW2.1
/~SCS: CN1.36, IC9.9
/~SLENB: CN1.40, IC9.6, R11.1
GNDS: C1.1, C2.2, C3.2, C4.2, C5.2, C6.1, C7.1, C8.1, C9.2, C10.1, C11.1, C12.1, C13.1, C14.1, C15.2, C16.2, C17.1, C18.2, C19.2, C20.2, C21.1, C22.2, C23.2, C25.1, C26.2, C27.2, C28.2, C29.2, C30.1, C31.1, C32.2, C33.2, C34.1, C35.2, C36.2, C37.1, C38.1, C39.1, C40.1, C41.1, C42.1, C43.1, C44.1, C45.1, C46.1, C47.1, C48.1, C49.1, C50.1, C51.1, C52.1, C53.1, C57.2, C58.1, C59.1, C60.1, C61.1, C63.2, C64.1, C65.1, C66.1, CN1.33, CN1.34, CN2.3, CN3.1, CN3.2, CN4.1, CN4.12, CN5.1, CN5.12, CN6.1, CN6.12, CN7.2, D6.2, D7.2, D13.2, FB8.2, FB9.1, FB10.1, IC1.1, IC1.39, IC2.14, IC2.22, IC3.10, IC4.1, IC5.1, IC6.1, IC7.10, IC8.8, IC9.4, IC9.5, IC9.8, IC10.10, IC11.10, IC12.10, IC13.10, IC14.7, IC15.7, IC16.1, IC16.18, IC17.1, IC17.18, IC18.1, IC18.18, IC19.1, IC19.18, IC36.2, J5A1001.2, J5B1001.2, JK4.2, JP1.3, R14.1, R26.1, R29.1, R32.2, R35.2, R36.2, R42.1, R43.1, R49.1, R50.1, R56.1, R57.1, R70.1, R72.1, RF1.5, SW2.2, SW3.3, TC1.2
unnamed: C18.1, D11.1, JK2.4
unnamed: C19.1, D8.1, JK2.6
unnamed: C22.1, D9.1, JK1.4
unnamed: C23.1, D10.1, JK1.6
unnamed: C24.2, IC7.19
unnamed: C33.1, D2.2, D3.1, FB2.2
unnamed: C35.1, FB1.1, SW1.5
unnamed: C36.1, FB2.1, SW1.2
unnamed: C37.2, Q3.3, R27.1, R29.2, R68.2
unnamed: C49.2, JK1.5, JK2.5, R13.2
unnamed: C54.1, Q2.1, R72.2
unnamed: C54.2, J5A1001.1
unnamed: C55.1, Q4.2, R33.2, R35.1
unnamed: C56.1, Q4.1, R36.1
unnamed: C60.2, L1.1, R63.2, R65.2, X1.1
unnamed: C61.2, CN1.32, R64.2
unnamed: C62.1, D13.1, D14.2, JP2.2
unnamed: C63.1, D14.1, IC36.3
unnamed: C64.2, L1.2
unnamed: C65.2, JP65.2
unnamed: C66.2, JP66.2
unnamed: C67.1, R30.1, R69.1, R70.2, TP7.1
unnamed: C68.2, R31.1
unnamed: CN2.9, IC5.10
unnamed: CN2.10, IC5.11
unnamed: CN2.11, IC5.12
unnamed: CN2.12, IC5.13
unnamed: CN2.13, IC5.14
unnamed: CN2.14, IC5.15
unnamed: CN2.15, IC4.12, IC5.16, R59.2
unnamed: CN2.16, IC5.17
unnamed: CN3.10, R61.2, R62.2
unnamed: CN7.1, SW1.6
unnamed: CN7.3, SW1.3
unnamed: FB6.1, IC7.17
unnamed: FB6.2, JK4.5
unnamed: FB7.1, R15.1
unnamed: FB7.2, JK3.4
unnamed: FB8.1, JK3.3
unnamed: FB9.2, JK2.3
unnamed: FB10.2, JK1.3
unnamed: IC1.6, JP1.1
unnamed: IC4.4, IC7.3
unnamed: IC4.5, IC7.4
unnamed: IC4.6, IC7.5
unnamed: IC4.7, IC7.6
unnamed: IC4.8, IC7.7
unnamed: IC4.9, IC7.8
unnamed: IC4.11, R12.2
unnamed: IC4.19, IC7.2
unnamed: IC6.2, R63.1
unnamed: IC6.3, R65.1, TC1.1, X1.2
unnamed: IC6.4, R22.2
unnamed: IC6.5, R23.2
unnamed: IC6.6, R9.2
unnamed: IC6.7, R10.2
unnamed: IC6.29, IC9.3
unnamed: IC6.30, IC9.2
unnamed: IC6.31, IC9.1
unnamed: IC6.39, R8.1
unnamed: IC8.1, Q1.1
unnamed: IC8.2, R20.2
unnamed: IC8.11, R18.2
unnamed: IC13.1, IC15.2
unnamed: IC5.24, IC15.4
unnamed: IC6.24, IC15.6
unnamed: IC6.23, IC15.8
unnamed: JK3.1, R17.2
unnamed: JK3.2, R16.1
unnamed: JK4.1, RY1.14
unnamed: JK4.3, RY1.11
unnamed: Q1.3, R19.2, R20.1
unnamed: Q2.2, R71.1
unnamed: Q2.3, R30.2
unnamed: Q3.1, R69.2
unnamed: Q3.2, R28.1
unnamed: Q4.3, R34.1
unnamed: Q5.2, R39.1
unnamed: Q5.3, R38.1, R40.1, R42.2
unnamed: Q6.2, R46.1
unnamed: Q6.3, R45.1, R47.1, R49.2
unnamed: Q7.2, R53.1
unnamed: Q7.3, R52.1, R54.1, R56.2
unnamed: R60.2, SW3.1
VCC1: C8.2, C9.1, C50.2, C52.2, C53.2, FB5.1, IC6.35, R27.2, R28.2, R71.2

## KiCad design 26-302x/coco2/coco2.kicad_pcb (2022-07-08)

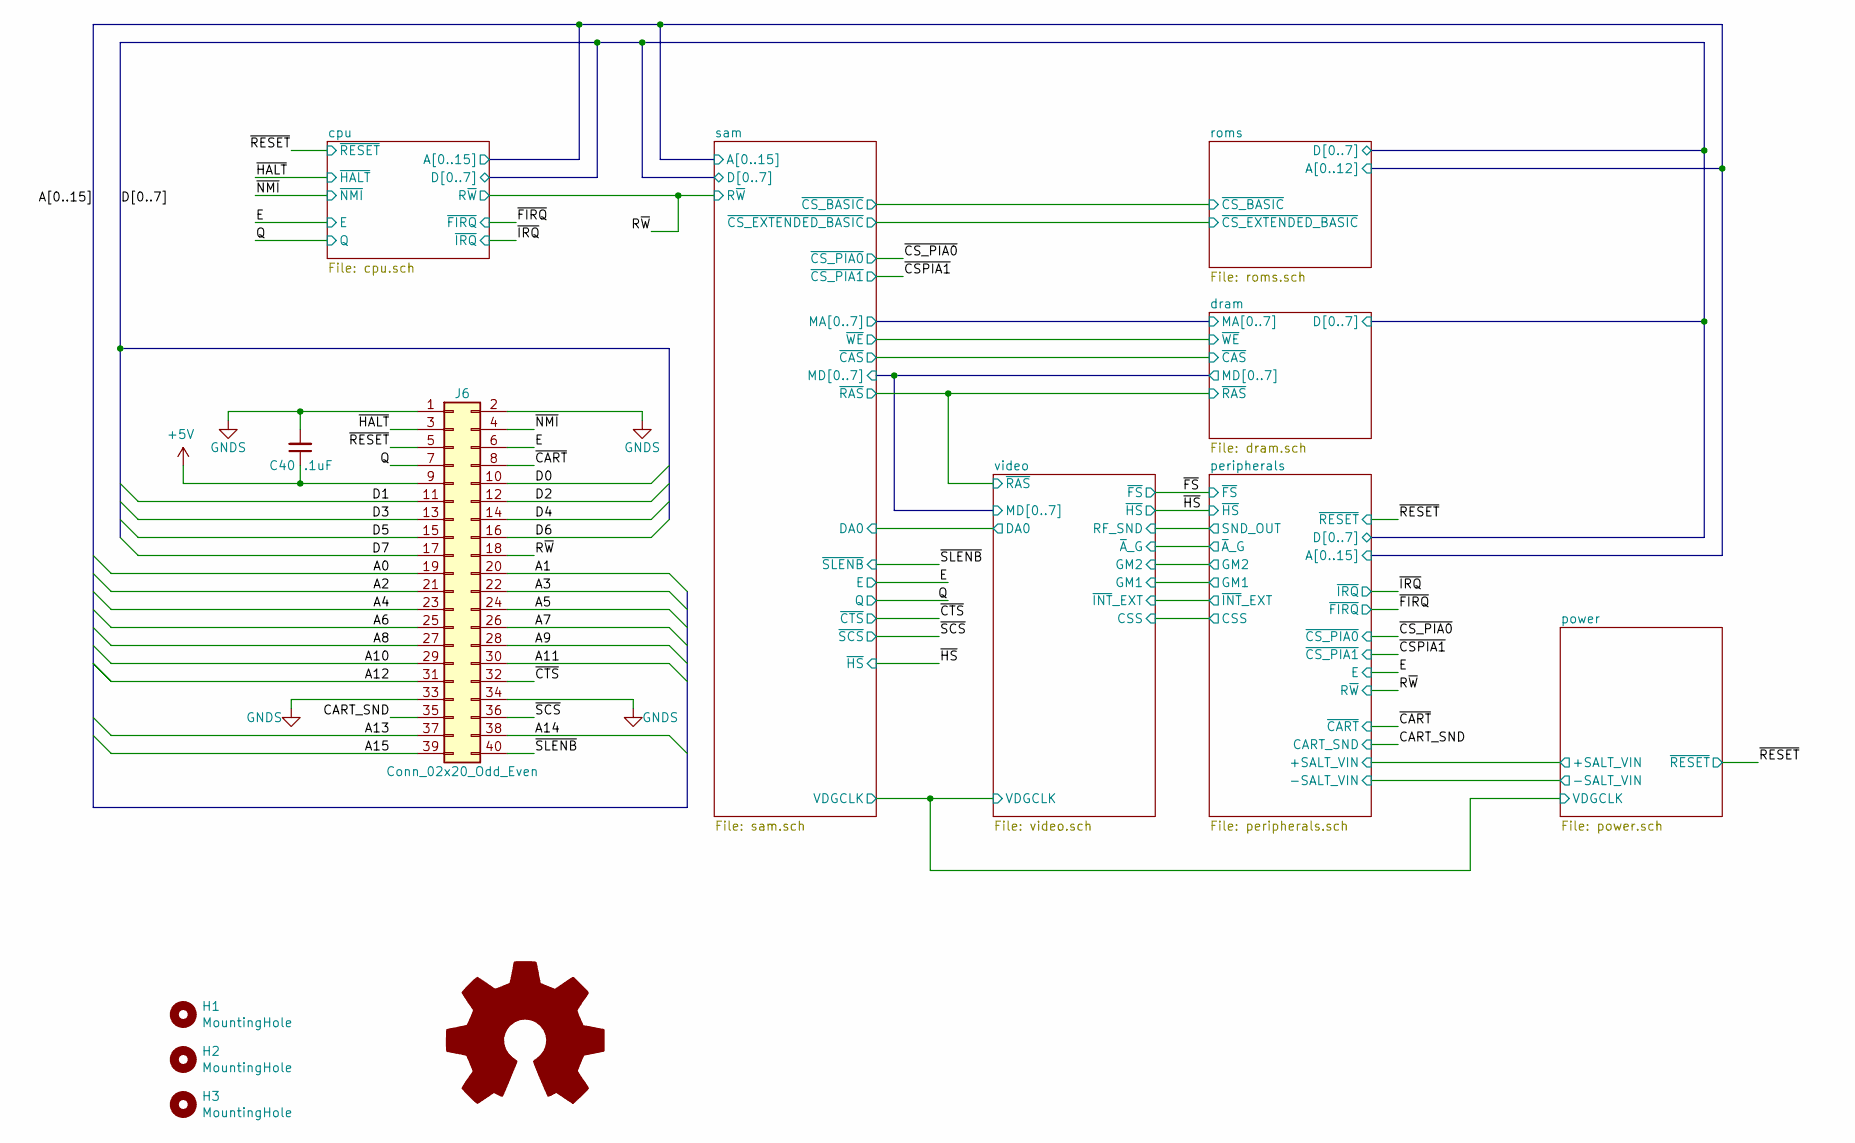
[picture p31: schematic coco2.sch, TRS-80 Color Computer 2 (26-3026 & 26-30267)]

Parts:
C40: .1uF; C_Axial_L3.8mm_D2.6mm_P10.00mm_Horizontal; Manufacturer part# A104K15X7RF5TAA
H1: MountingHole; MountingHole_4.5mm
H2, H3: MountingHole; MountingHole_4mm
J6: Conn_02x20_Odd_Even; EBC20DRAS; Manufacturer part# EBC20DRAS

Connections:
+5V: C40.1, J6.9; also elsewhere on the board
/A0: J6.19; also elsewhere on the board
/A1: J6.20; also elsewhere on the board
/A2: J6.21; also elsewhere on the board
/A3: J6.22; also elsewhere on the board
/A4: J6.23; also elsewhere on the board
/A5: J6.24; also elsewhere on the board
/A6: J6.25; also elsewhere on the board
/A7: J6.26; also elsewhere on the board
/A8: J6.27; also elsewhere on the board
/A9: J6.28; also elsewhere on the board
/A10: J6.29; also elsewhere on the board
/A11: J6.30; also elsewhere on the board
/A12: J6.31; also elsewhere on the board
/A13: J6.37; also elsewhere on the board
/A14: J6.38; also elsewhere on the board
/A15: J6.39; also elsewhere on the board
/CART_SND: J6.35; also elsewhere on the board
/D0: J6.10; also elsewhere on the board
/D1: J6.11; also elsewhere on the board
/D2: J6.12; also elsewhere on the board
/D3: J6.13; also elsewhere on the board
/D4: J6.14; also elsewhere on the board
/D5: J6.15; also elsewhere on the board
/D6: J6.16; also elsewhere on the board
/D7: J6.17; also elsewhere on the board
/E: J6.6; also elsewhere on the board
/Q: J6.7; also elsewhere on the board
/R~W: J6.18; also elsewhere on the board
/~CART: J6.8; also elsewhere on the board
/~CTS: J6.32; also elsewhere on the board
/~HALT: J6.3; also elsewhere on the board
/~NMI: J6.4; also elsewhere on the board
/~RESET: J6.5; also elsewhere on the board
/~SCS: J6.36; also elsewhere on the board
/~SLENB: J6.40; also elsewhere on the board
GNDS: C40.2, J6.1, J6.2, J6.33, J6.34; also elsewhere on the board

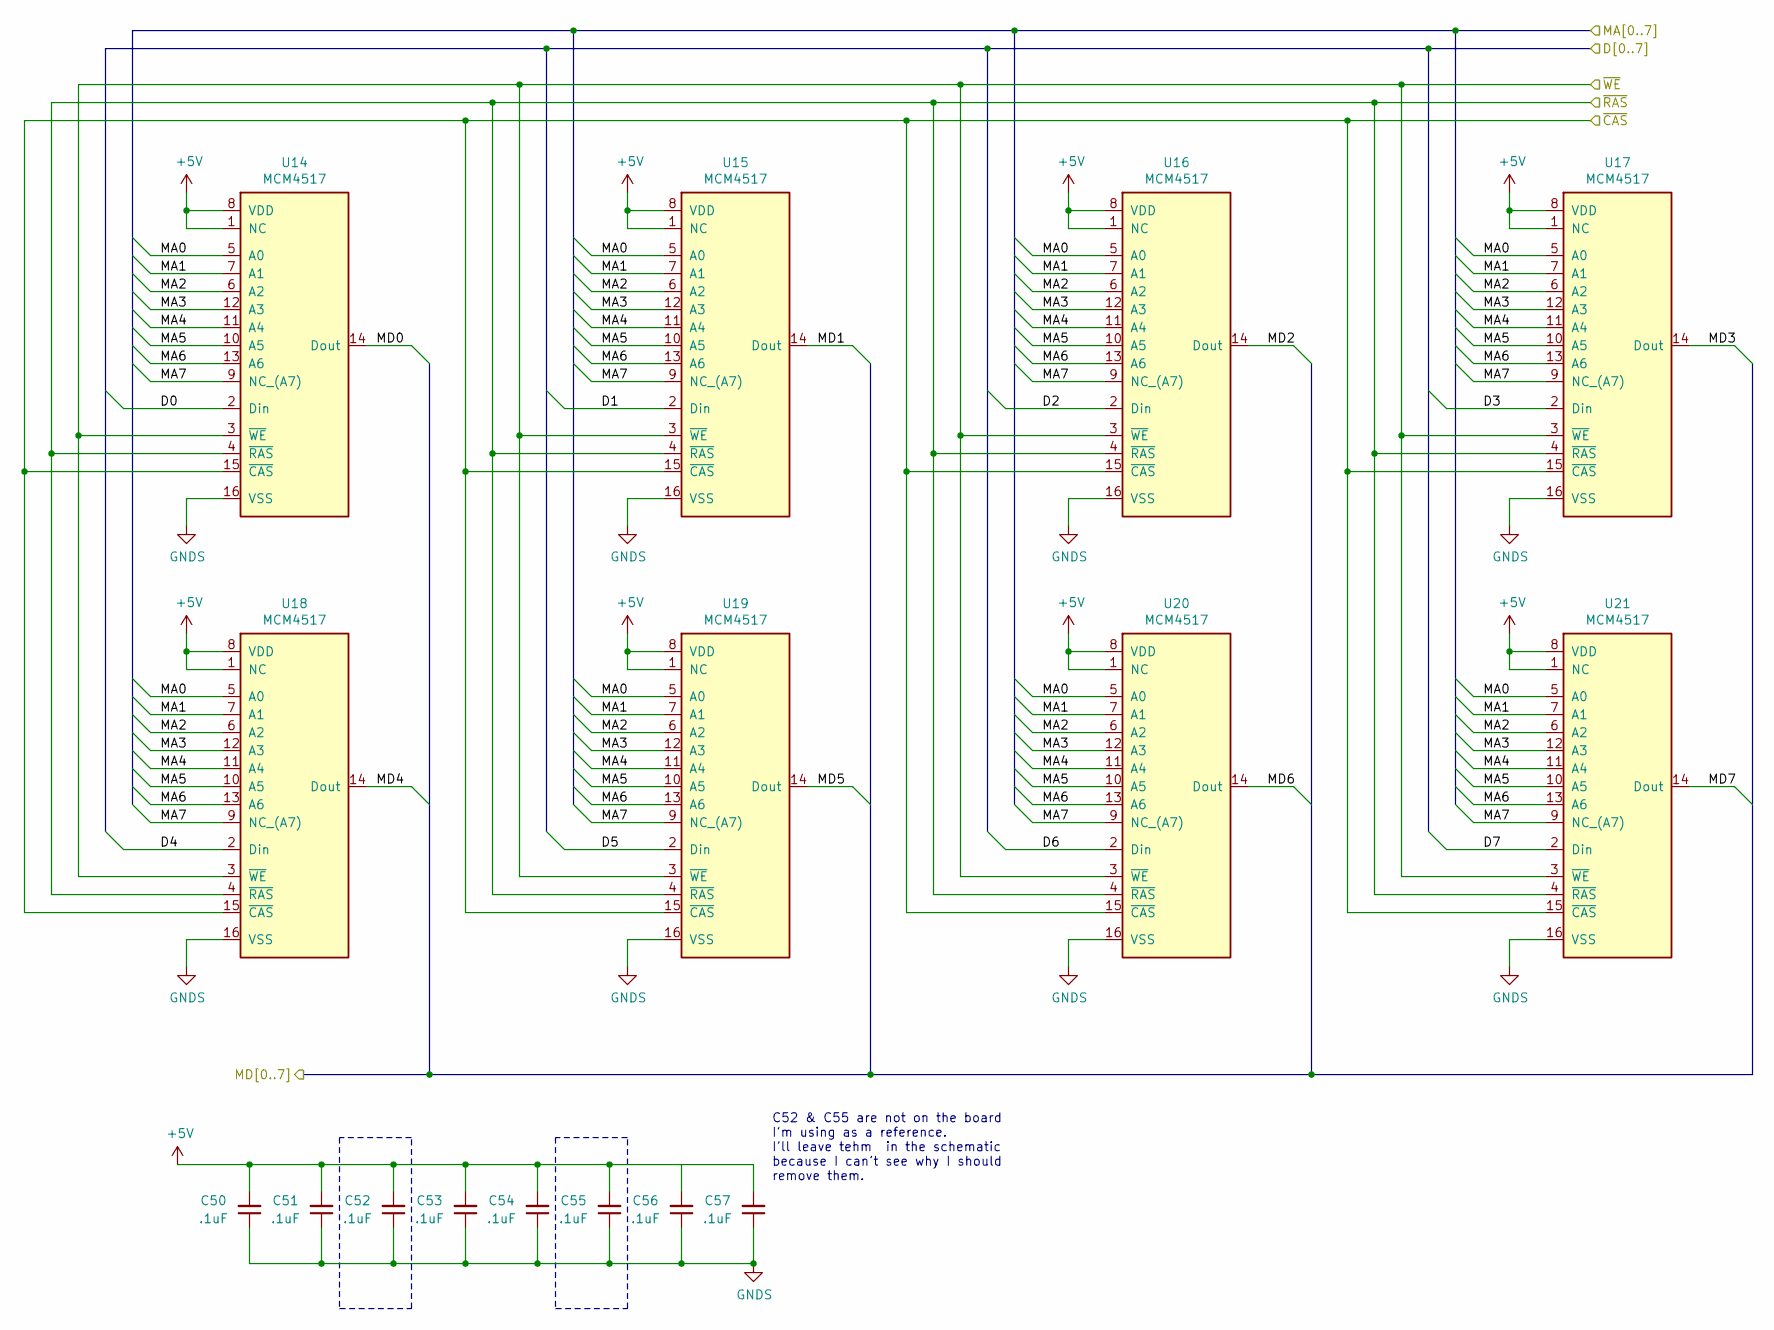
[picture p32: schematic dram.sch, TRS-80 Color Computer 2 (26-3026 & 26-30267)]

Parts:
C50, C51, C52, C53, C54, C55, C56, C57: .1uF; C_Axial_L3.8mm_D2.6mm_P10.00mm_Horizontal; Manufacturer part# A104K15X7RF5TAA
U14, U15, U16, U17, U18, U19, U21: MCM4517; DIP-16_W7.62mm_Socket; Manufacturer part# 1-2199298-4
U20: MCM4517; DIP-16_W7.62mm_Socket

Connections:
+5V: C50.2, C51.2, C52.2, C53.2, C54.2, C55.2, C56.2, C57.2, U14.1 (NC), U14.8 (VDD), U15.1 (NC), U15.8 (VDD), U16.1 (NC), U16.8 (VDD), U17.1 (NC), U17.8 (VDD), U18.1 (NC), U18.8 (VDD), U19.1 (NC), U19.8 (VDD), U20.1 (NC), U20.8 (VDD), U21.1 (NC), U21.8 (VDD); also elsewhere on the board
/D0: U14.2 (Din); also elsewhere on the board
/D1: U15.2 (Din); also elsewhere on the board
/D2: U16.2 (Din); also elsewhere on the board
/D3: U17.2 (Din); also elsewhere on the board
/D4: U18.2 (Din); also elsewhere on the board
/D5: U19.2 (Din); also elsewhere on the board
/D6: U20.2 (Din); also elsewhere on the board
/D7: U21.2 (Din); also elsewhere on the board
/dram/MA0: U14.5 (A0), U15.5 (A0), U16.5 (A0), U17.5 (A0), U18.5 (A0), U19.5 (A0), U20.5 (A0), U21.5 (A0); also elsewhere on the board
/dram/MA1: U14.7 (A1), U15.7 (A1), U16.7 (A1), U17.7 (A1), U18.7 (A1), U19.7 (A1), U20.7 (A1), U21.7 (A1); also elsewhere on the board
/dram/MA2: U14.6 (A2), U15.6 (A2), U16.6 (A2), U17.6 (A2), U18.6 (A2), U19.6 (A2), U20.6 (A2), U21.6 (A2); also elsewhere on the board
/dram/MA3: U14.12 (A3), U15.12 (A3), U16.12 (A3), U17.12 (A3), U18.12 (A3), U19.12 (A3), U20.12 (A3), U21.12 (A3); also elsewhere on the board
/dram/MA4: U14.11 (A4), U15.11 (A4), U16.11 (A4), U17.11 (A4), U18.11 (A4), U19.11 (A4), U20.11 (A4), U21.11 (A4); also elsewhere on the board
/dram/MA5: U14.10 (A5), U15.10 (A5), U16.10 (A5), U17.10 (A5), U18.10 (A5), U19.10 (A5), U20.10 (A5), U21.10 (A5); also elsewhere on the board
/dram/MA6: U14.13 (A6), U15.13 (A6), U16.13 (A6), U17.13 (A6), U18.13 (A6), U19.13 (A6), U20.13 (A6), U21.13 (A6); also elsewhere on the board
/dram/MA7: U14.9 (NC_(A7)), U15.9 (NC_(A7)), U16.9 (NC_(A7)), U17.9 (NC_(A7)), U18.9 (NC_(A7)), U19.9 (NC_(A7)), U20.9 (NC_(A7)), U21.9 (NC_(A7)); also elsewhere on the board
/dram/MD0: U14.14 (Dout); also elsewhere on the board
/dram/MD1: U15.14 (Dout); also elsewhere on the board
/dram/MD2: U16.14 (Dout); also elsewhere on the board
/dram/MD3: U17.14 (Dout); also elsewhere on the board
/dram/MD4: U18.14 (Dout); also elsewhere on the board
/dram/MD5: U19.14 (Dout); also elsewhere on the board
/dram/MD6: U20.14 (Dout); also elsewhere on the board
/dram/MD7: U21.14 (Dout); also elsewhere on the board
/dram/~CAS: U14.15 (~CAS), U15.15 (~CAS), U16.15 (~CAS), U17.15 (~CAS), U18.15 (~CAS), U19.15 (~CAS), U20.15 (~CAS), U21.15 (~CAS); also elsewhere on the board
/dram/~RAS: U14.4 (~RAS), U15.4 (~RAS), U16.4 (~RAS), U17.4 (~RAS), U18.4 (~RAS), U19.4 (~RAS), U20.4 (~RAS), U21.4 (~RAS); also elsewhere on the board
/dram/~WE: U14.3 (~WE), U15.3 (~WE), U16.3 (~WE), U17.3 (~WE), U18.3 (~WE), U19.3 (~WE), U20.3 (~WE), U21.3 (~WE); also elsewhere on the board
GNDS: C50.1, C51.1, C52.1, C53.1, C54.1, C55.1, C56.1, C57.1, U14.16 (VSS), U15.16 (VSS), U16.16 (VSS), U17.16 (VSS), U18.16 (VSS), U19.16 (VSS), U20.16 (VSS), U21.16 (VSS); also elsewhere on the board

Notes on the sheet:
C52 & C55 are not on the board I'm using as a reference. I'll leave tehm in the schematic because I can't see why I should remove them.

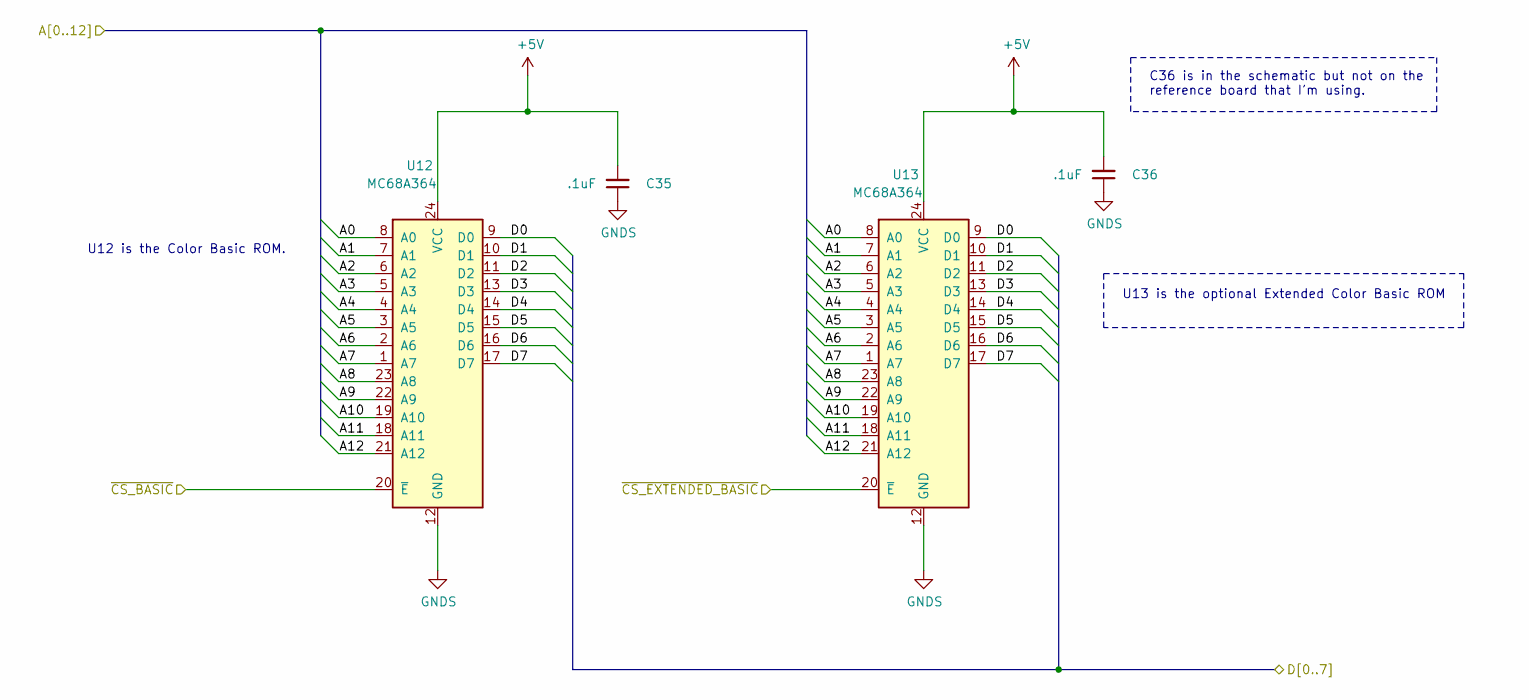
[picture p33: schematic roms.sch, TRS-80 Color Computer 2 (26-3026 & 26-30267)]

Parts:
C35, C36: .1uF; C_Axial_L3.8mm_D2.6mm_P10.00mm_Horizontal; Manufacturer part# A104K15X7RF5TAA
U12, U13: MC68A364; DIP-24_W15.24mm_Socket; Manufacturer part# 243-24-1-06

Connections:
+5V: C35.2, C36.2, U12.24 (VCC), U13.24 (VCC); also elsewhere on the board
/A0: U12.8 (A0), U13.8 (A0); also elsewhere on the board
/A1: U12.7 (A1), U13.7 (A1); also elsewhere on the board
/A2: U12.6 (A2), U13.6 (A2); also elsewhere on the board
/A3: U12.5 (A3), U13.5 (A3); also elsewhere on the board
/A4: U12.4 (A4), U13.4 (A4); also elsewhere on the board
/A5: U12.3 (A5), U13.3 (A5); also elsewhere on the board
/A6: U12.2 (A6), U13.2 (A6); also elsewhere on the board
/A7: U12.1 (A7), U13.1 (A7); also elsewhere on the board
/A8: U12.23 (A8), U13.23 (A8); also elsewhere on the board
/A9: U12.22 (A9), U13.22 (A9); also elsewhere on the board
/A10: U12.19 (A10), U13.19 (A10); also elsewhere on the board
/A11: U12.18 (A11), U13.18 (A11); also elsewhere on the board
/A12: U12.21 (A12), U13.21 (A12); also elsewhere on the board
/D0: U12.9 (D0), U13.9 (D0); also elsewhere on the board
/D1: U12.10 (D1), U13.10 (D1); also elsewhere on the board
/D2: U12.11 (D2), U13.11 (D2); also elsewhere on the board
/D3: U12.13 (D3), U13.13 (D3); also elsewhere on the board
/D4: U12.14 (D4), U13.14 (D4); also elsewhere on the board
/D5: U12.15 (D5), U13.15 (D5); also elsewhere on the board
/D6: U12.16 (D6), U13.16 (D6); also elsewhere on the board
/D7: U12.17 (D7), U13.17 (D7); also elsewhere on the board
/roms/~CS_BASIC: U12.20 (~E); also elsewhere on the board
/roms/~CS_EXTENDED_BASIC: U13.20 (~E); also elsewhere on the board
GNDS: C35.1, C36.1, U12.12 (GND), U13.12 (GND); also elsewhere on the board

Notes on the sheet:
U12 is the Color Basic ROM.
U13 is the optional Extended Color Basic ROM
C36 is in the schematic but not on the reference board that I'm using.

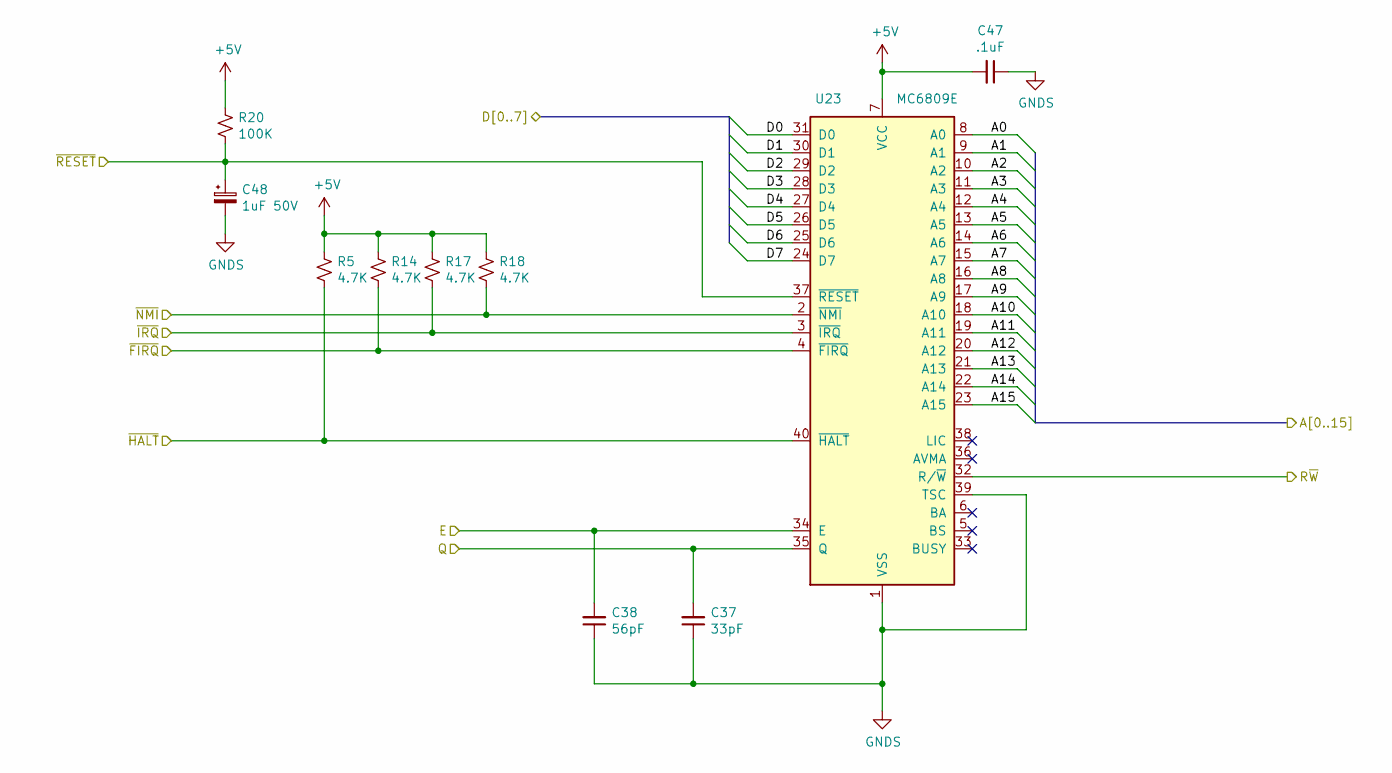
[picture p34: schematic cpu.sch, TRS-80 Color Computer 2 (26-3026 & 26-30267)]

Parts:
C37: 33pF; C_Rect_L7.2mm_W3.0mm_P5.00mm_FKS2_FKP2_MKS2_MKP2; Manufacturer part# FA28NP01H330JNU06
C38: 56pF; C_Rect_L7.2mm_W2.5mm_P5.00mm_FKS2_FKP2_MKS2_MKP2; Manufacturer part# RDE5C1H560J0M1H03A
C47: .1uF; C_Axial_L3.8mm_D2.6mm_P10.00mm_Horizontal; Manufacturer part# A104K15X7RF5TAA
C48: 1uF 50V; CP_Radial_D5.0mm_P2.00mm; Manufacturer part# 515D105M050JA6AE3
R5, R14, R17, R18: 4.7K; R_Axial_DIN0207_L6.3mm_D2.5mm_P10.16mm_Horizontal; Manufacturer part# Stackpole Electronics Inc
R20: 100K; R_Axial_DIN0207_L6.3mm_D2.5mm_P10.16mm_Horizontal; manufacturer part# CF14JT100K
U23: MC6809E; DIP-40_W15.24mm_Socket; Manufacturer part# ED40DT

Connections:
+5V: C47.2, R5.1, R14.1, R17.1, R18.1, R20.1, U23.7 (VCC); also elsewhere on the board
/A0: U23.8 (A0); also elsewhere on the board
/A1: U23.9 (A1); also elsewhere on the board
/A2: U23.10 (A2); also elsewhere on the board
/A3: U23.11 (A3); also elsewhere on the board
/A4: U23.12 (A4); also elsewhere on the board
/A5: U23.13 (A5); also elsewhere on the board
/A6: U23.14 (A6); also elsewhere on the board
/A7: U23.15 (A7); also elsewhere on the board
/A8: U23.16 (A8); also elsewhere on the board
/A9: U23.17 (A9); also elsewhere on the board
/A10: U23.18 (A10); also elsewhere on the board
/A11: U23.19 (A11); also elsewhere on the board
/A12: U23.20 (A12); also elsewhere on the board
/A13: U23.21 (A13); also elsewhere on the board
/A14: U23.22 (A14); also elsewhere on the board
/A15: U23.23 (A15); also elsewhere on the board
/D0: U23.31 (D0); also elsewhere on the board
/D1: U23.30 (D1); also elsewhere on the board
/D2: U23.29 (D2); also elsewhere on the board
/D3: U23.28 (D3); also elsewhere on the board
/D4: U23.27 (D4); also elsewhere on the board
/D5: U23.26 (D5); also elsewhere on the board
/D6: U23.25 (D6); also elsewhere on the board
/D7: U23.24 (D7); also elsewhere on the board
/E: C38.2, U23.34 (E); also elsewhere on the board
/Q: C37.2, U23.35 (Q); also elsewhere on the board
/R~W: U23.32 (R/~W); also elsewhere on the board
/~FIRQ: R14.2, U23.4 (~FIRQ); also elsewhere on the board
/~HALT: R5.2, U23.40 (~HALT); also elsewhere on the board
/~IRQ: R17.2, U23.3 (~IRQ); also elsewhere on the board
/~NMI: R18.2, U23.2 (~NMI); also elsewhere on the board
/~RESET: C48.1, R20.2, U23.37 (~RESET); also elsewhere on the board
GNDS: C37.1, C38.1, C47.1, C48.2, U23.1 (VSS), U23.39 (TSC); also elsewhere on the board

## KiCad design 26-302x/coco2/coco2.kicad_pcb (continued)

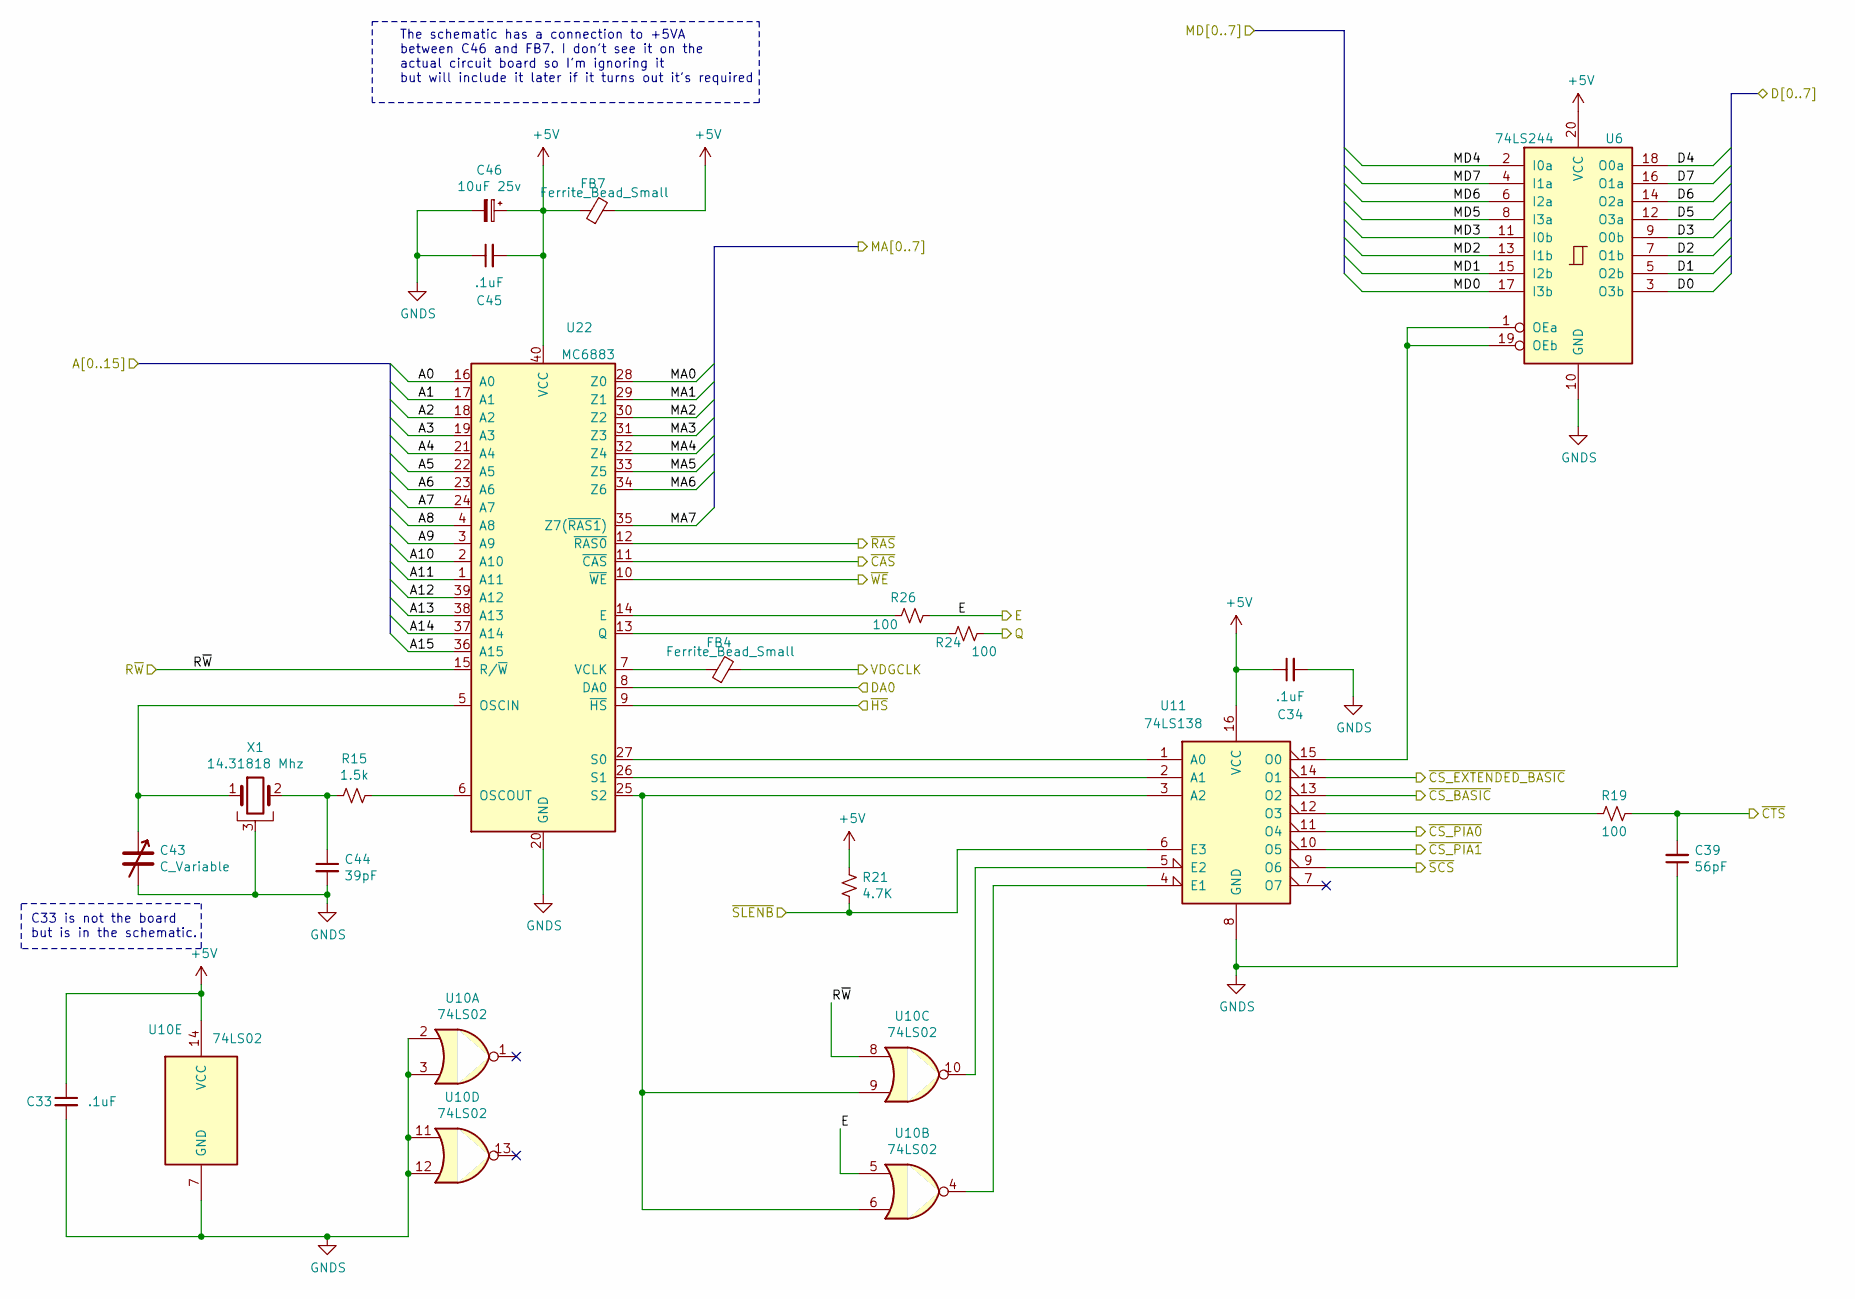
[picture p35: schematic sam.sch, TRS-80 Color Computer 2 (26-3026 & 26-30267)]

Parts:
C33, C34, C45: .1uF; C_Axial_L3.8mm_D2.6mm_P10.00mm_Horizontal; Manufacturer part# A104K15X7RF5TAA
C39: 56pF; C_Rect_L7.2mm_W2.5mm_P5.00mm_FKS2_FKP2_MKS2_MKP2; Manufacturer part# RDE5C1H560J0M1H03A
C43: C_Variable; C_Rect_L7.2mm_W7.2mm_P5.00mm_FKS2_FKP2_MKS2_MKP2; Manufacturer part# GKG50015
C44: 39pF; C_Disc_D7.5mm_W5.0mm_P5.00mm; Manufacturer part# RDE5C1H390J0M1H03A
C46: 10uF 25v; CP_Radial_D5.0mm_P2.00mm; Manufacturer part# UPW1E100MDD
FB4, FB7: Ferrite_Bead_Small; ferrite_bead; Manufacturer part# 2743007111
R15: 1.5k; R_Axial_DIN0207_L6.3mm_D2.5mm_P10.16mm_Horizontal; Manufacturer part# MFR-25FBF52-1K5
R19, R24, R26: 100; R_Axial_DIN0207_L6.3mm_D2.5mm_P10.16mm_Horizontal; Manufacturer part# MFR-25FBF52-100R
R21: 4.7K; R_Axial_DIN0207_L6.3mm_D2.5mm_P10.16mm_Horizontal; Manufacturer part# Stackpole Electronics Inc
U6: 74LS244; DIP-20_W7.62mm_Socket; Manufacturer part# 243-20-1-03
U10: 74LS02; DIP-14_W7.62mm_Socket; Manufacturer part# 1-2199298-4
U11: 74LS138; DIP-16_W7.62mm_Socket; Manufacturer part# 1-2199298-4
U22: MC6883; DIP-40_W15.24mm_Socket; Manufacturer part# ED40DT
X1: 14.31818 Mhz; Crystal_HC49-U_Horizontal; Manufacturer part# MP143

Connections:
+5V: C33.1, C34.1, C45.2, C46.1, FB7.1, FB7.2, R21.1, U6.20 (VCC), U10.14 (VCC), U11.16 (VCC), U22.40 (VCC); also elsewhere on the board
/A0: U22.16 (A0); also elsewhere on the board
/A1: U22.17 (A1); also elsewhere on the board
/A2: U22.18 (A2); also elsewhere on the board
/A3: U22.19 (A3); also elsewhere on the board
/A4: U22.21 (A4); also elsewhere on the board
/A5: U22.22 (A5); also elsewhere on the board
/A6: U22.23 (A6); also elsewhere on the board
/A7: U22.24 (A7); also elsewhere on the board
/A8: U22.4 (A8); also elsewhere on the board
/A9: U22.3 (A9); also elsewhere on the board
/A10: U22.2 (A10); also elsewhere on the board
/A11: U22.1 (A11); also elsewhere on the board
/A12: U22.39 (A12); also elsewhere on the board
/A13: U22.38 (A13); also elsewhere on the board
/A14: U22.37 (A14); also elsewhere on the board
/A15: U22.36 (A15); also elsewhere on the board
/D0: U6.3 (O3b); also elsewhere on the board
/D1: U6.5 (O2b); also elsewhere on the board
/D2: U6.7 (O1b); also elsewhere on the board
/D3: U6.9 (O0b); also elsewhere on the board
/D4: U6.18 (O0a); also elsewhere on the board
/D5: U6.12 (O3a); also elsewhere on the board
/D6: U6.14 (O2a); also elsewhere on the board
/D7: U6.16 (O1a); also elsewhere on the board
/E: R26.1, U10.5; also elsewhere on the board
/Q: R24.1; also elsewhere on the board
/R~W: U10.8, U22.15 (R/~W); also elsewhere on the board
/dram/MA0: U22.28 (Z0); also elsewhere on the board
/dram/MA1: U22.29 (Z1); also elsewhere on the board
/dram/MA2: U22.30 (Z2); also elsewhere on the board
/dram/MA3: U22.31 (Z3); also elsewhere on the board
/dram/MA4: U22.32 (Z4); also elsewhere on the board
/dram/MA5: U22.33 (Z5); also elsewhere on the board
/dram/MA6: U22.34 (Z6); also elsewhere on the board
/dram/MA7: U22.35 (Z7(~RAS1~)); also elsewhere on the board
/dram/MD0: U6.17 (I3b); also elsewhere on the board
/dram/MD1: U6.15 (I2b); also elsewhere on the board
/dram/MD2: U6.13 (I1b); also elsewhere on the board
/dram/MD3: U6.11 (I0b); also elsewhere on the board
/dram/MD4: U6.2 (I0a); also elsewhere on the board
/dram/MD5: U6.8 (I3a); also elsewhere on the board
/dram/MD6: U6.6 (I2a); also elsewhere on the board
/dram/MD7: U6.4 (I1a); also elsewhere on the board
/dram/~CAS: U22.11 (~CAS); also elsewhere on the board
/dram/~RAS: U22.12 (~RAS0); also elsewhere on the board
/dram/~WE: U22.10 (~WE); also elsewhere on the board
/power/VDGCLK: FB4.2; also elsewhere on the board
/roms/~CS_BASIC: U11.13 (O2); also elsewhere on the board
/roms/~CS_EXTENDED_BASIC: U11.14 (O1); also elsewhere on the board
/sam/DA0: U22.8 (DA0); also elsewhere on the board
/~CSPIA1: U11.10 (O5); also elsewhere on the board
/~CS_PIA0: U11.11 (O4); also elsewhere on the board
/~CTS: C39.2, R19.1; also elsewhere on the board
/~HS: U22.9 (~HS); also elsewhere on the board
/~SCS: U11.9 (O6); also elsewhere on the board
/~SLENB: R21.2, U11.6 (E3); also elsewhere on the board
GNDS: C33.2, C34.2, C39.1, C43.2, C44.2, C45.1, C46.2, U6.10 (GND), U10.2, U10.3, U10.7 (GND), U10.11, U10.12, U11.8 (GND), U22.20 (GND), X1.3; also elsewhere on the board
unnamed: C43.1, U22.5 (OSCIN), X1.1
unnamed: C44.1, R15.2, X1.2
unnamed: FB4.1, U22.7 (VCLK)
unnamed: R15.1, U22.6 (OSCOUT)
unnamed: R19.2, U11.12 (O3)
unnamed: R24.2, U22.13 (Q)
unnamed: R26.2, U22.14 (E)
unnamed: U10.4, U11.4 (E1)
unnamed: U10.6, U10.9, U11.3 (A2), U22.25 (S2)
unnamed: U10.10, U11.5 (E2)
unnamed: U11.1 (A0), U22.27 (S0)
unnamed: U11.2 (A1), U22.26 (S1)
unnamed: U6.1 (OEa), U6.19 (OEb), U11.15 (O0)

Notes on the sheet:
The schematic has a connection to +5VA between C46 and FB7. I don't see it on the actual circuit board so I'm ignoring it but will include it later if it turns out it's required
C33 is not the board but is in the schematic.

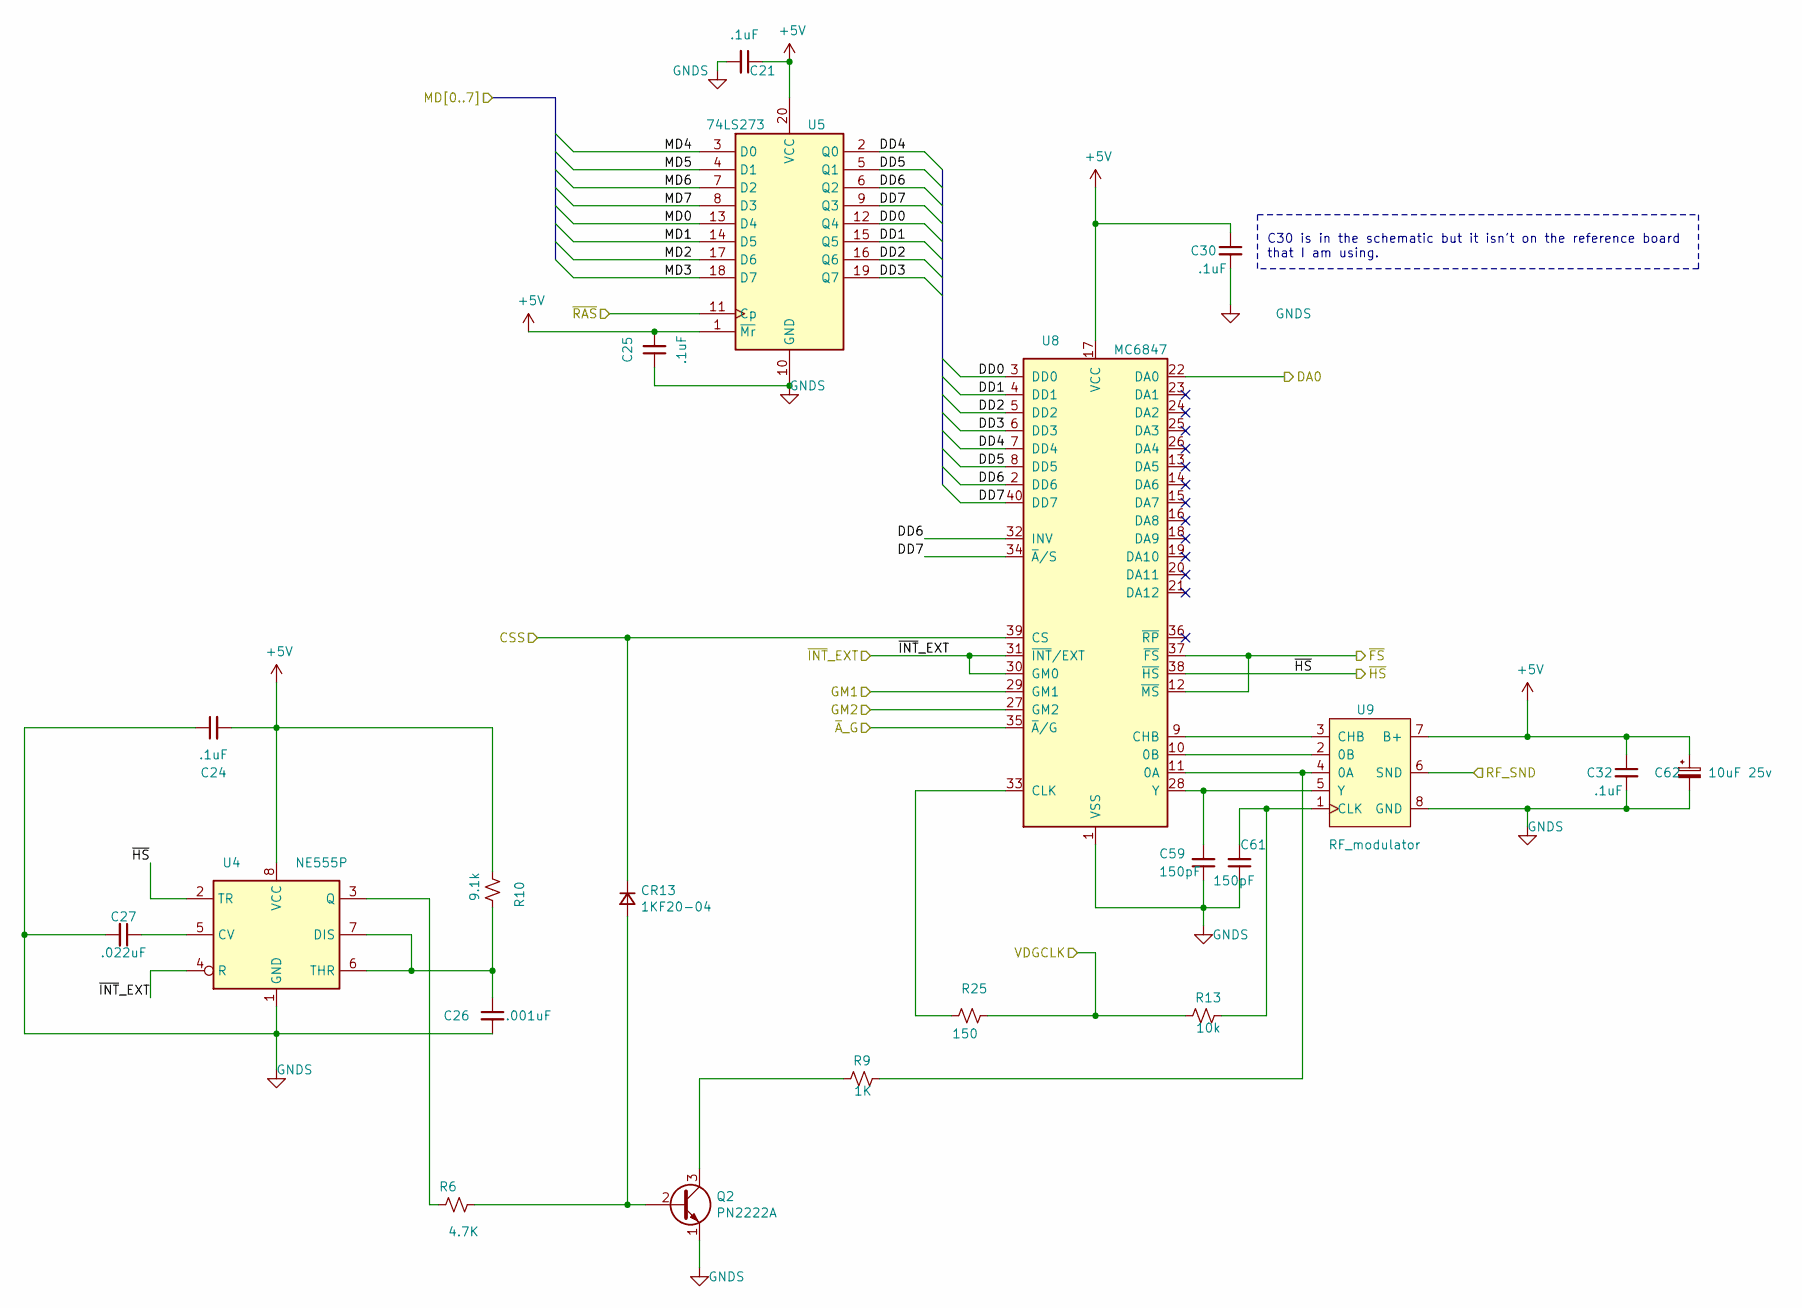
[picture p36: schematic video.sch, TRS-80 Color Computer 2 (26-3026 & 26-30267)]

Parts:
C21, C24, C25, C30, C32: .1uF; C_Axial_L3.8mm_D2.6mm_P10.00mm_Horizontal; Manufacturer part# A104K15X7RF5TAA
C26: .001uF; C_Rect_L4.0mm_W2.5mm_P2.50mm; Manufacturer part# C315C102K1R5TA7301
C27: .022uF; C_Disc_D8.0mm_W2.5mm_P5.00mm; Manufacturer part# C317C223M5U5TA7301
C59, C61: 150pF; C_Rect_L7.2mm_W2.5mm_P5.00mm_FKS2_FKP2_MKS2_MKP2; Manufacturer part# FA28C0G2E151JNU06
C62: 10uF 25v; CP_Radial_D5.0mm_P2.00mm; Manufacturer part# UPW1E100MDD
CR13: 1KF20-04; D_A-405_P10.16mm_Horizontal; Manufacturer part# 1N4148
Q2: PN2222A; TO-92_Inline; Manufacturer part# PN2222A PBFREE
R6: 4.7K; R_Axial_DIN0207_L6.3mm_D2.5mm_P10.16mm_Horizontal; Manufacturer part# Stackpole Electronics Inc
R9: 1K; R_Axial_DIN0207_L6.3mm_D2.5mm_P10.16mm_Horizontal; Manufacturer part# CF14JT1K00
R10: 9.1k; R_Axial_DIN0207_L6.3mm_D2.5mm_P10.16mm_Horizontal; Manufacturer part# CF14JT9K10
R13: 10k; R_Axial_DIN0207_L6.3mm_D2.5mm_P10.16mm_Horizontal; Manufacturer part# CF14JT10K0
R25: 150; R_Axial_DIN0207_L6.3mm_D2.5mm_P10.16mm_Horizontal; Manufacturer part# CF14JT150R
U4: NE555P; DIP-8_W7.62mm_Socket; Manufacturer part# A 08-LC-TT
U5: 74LS273; DIP-20_W7.62mm_Socket; Manufacturer part# 243-20-1-03
U8: MC6847; DIP-40_W15.24mm_Socket; Manufacturer part# ED40DT
U9: RF_modulator; coco2_vertical_rf_sheild_3

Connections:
+5V: C21.1, C24.2, C25.2, C30.1, C32.1, C62.1, R10.2, U4.8 (VCC), U5.1 (~Mr), U5.20 (VCC), U8.17 (VCC), U9.7 (B+); also elsewhere on the board
/dram/MD0: U5.13 (D4); also elsewhere on the board
/dram/MD1: U5.14 (D5); also elsewhere on the board
/dram/MD2: U5.17 (D6); also elsewhere on the board
/dram/MD3: U5.18 (D7); also elsewhere on the board
/dram/MD4: U5.3 (D0); also elsewhere on the board
/dram/MD5: U5.4 (D1); also elsewhere on the board
/dram/MD6: U5.7 (D2); also elsewhere on the board
/dram/MD7: U5.8 (D3); also elsewhere on the board
/dram/~RAS: U5.11 (Cp); also elsewhere on the board
/peripherals/CSS: CR13.1 (K), U8.39 (CS); also elsewhere on the board
/peripherals/GM1: U8.29 (GM1); also elsewhere on the board
/peripherals/GM2: U8.27 (GM2); also elsewhere on the board
/peripherals/~A~_G: U8.35 (~A~/G); also elsewhere on the board
/peripherals/~INT~_EXT: U4.4 (R), U8.30 (GM0), U8.31 (~INT~/EXT); also elsewhere on the board
/power/VDGCLK: R13.2, R25.1; also elsewhere on the board
/sam/DA0: U8.22 (DA0); also elsewhere on the board
/video/DD0: U5.12 (Q4), U8.3 (DD0)
/video/DD1: U5.15 (Q5), U8.4 (DD1)
/video/DD2: U5.16 (Q6), U8.5 (DD2)
/video/DD3: U5.19 (Q7), U8.6 (DD3)
/video/DD4: U5.2 (Q0), U8.7 (DD4)
/video/DD5: U5.5 (Q1), U8.8 (DD5)
/video/DD6: U5.6 (Q2), U8.2 (DD6), U8.32 (INV)
/video/DD7: U5.9 (Q3), U8.34 (~A~/S), U8.40 (DD7)
/video/RF_SND: U9.6 (SND); also elsewhere on the board
/~FS: U8.12 (~MS), U8.37 (~FS); also elsewhere on the board
/~HS: U4.2 (TR), U8.38 (~HS); also elsewhere on the board
GNDS: C21.2, C24.1, C25.1, C26.2, C27.2, C30.2, C32.2, C59.1, C61.1, C62.2, Q2.1 (E), U4.1 (GND), U5.10 (GND), U8.1 (VSS), U9.8 (GND); also elsewhere on the board
unnamed: C26.1, R10.1, U4.6 (THR), U4.7 (DIS)
unnamed: C27.1, U4.5 (CV)
unnamed: C59.2, U8.28 (Y), U9.5 (Y)
unnamed: C61.2, R13.1, U9.1 (CLK)
unnamed: CR13.2 (A), Q2.2 (B), R6.1
unnamed: Q2.3 (C), R9.2
unnamed: R6.2, U4.3 (Q)
unnamed: R9.1, U8.11 (0A), U9.4 (0A)
unnamed: R25.2, U8.33 (CLK)
unnamed: U8.9 (CHB), U9.3 (CHB)
unnamed: U8.10 (0B), U9.2 (0B)

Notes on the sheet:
C30 is in the schematic but it isn't on the reference board that I am using.

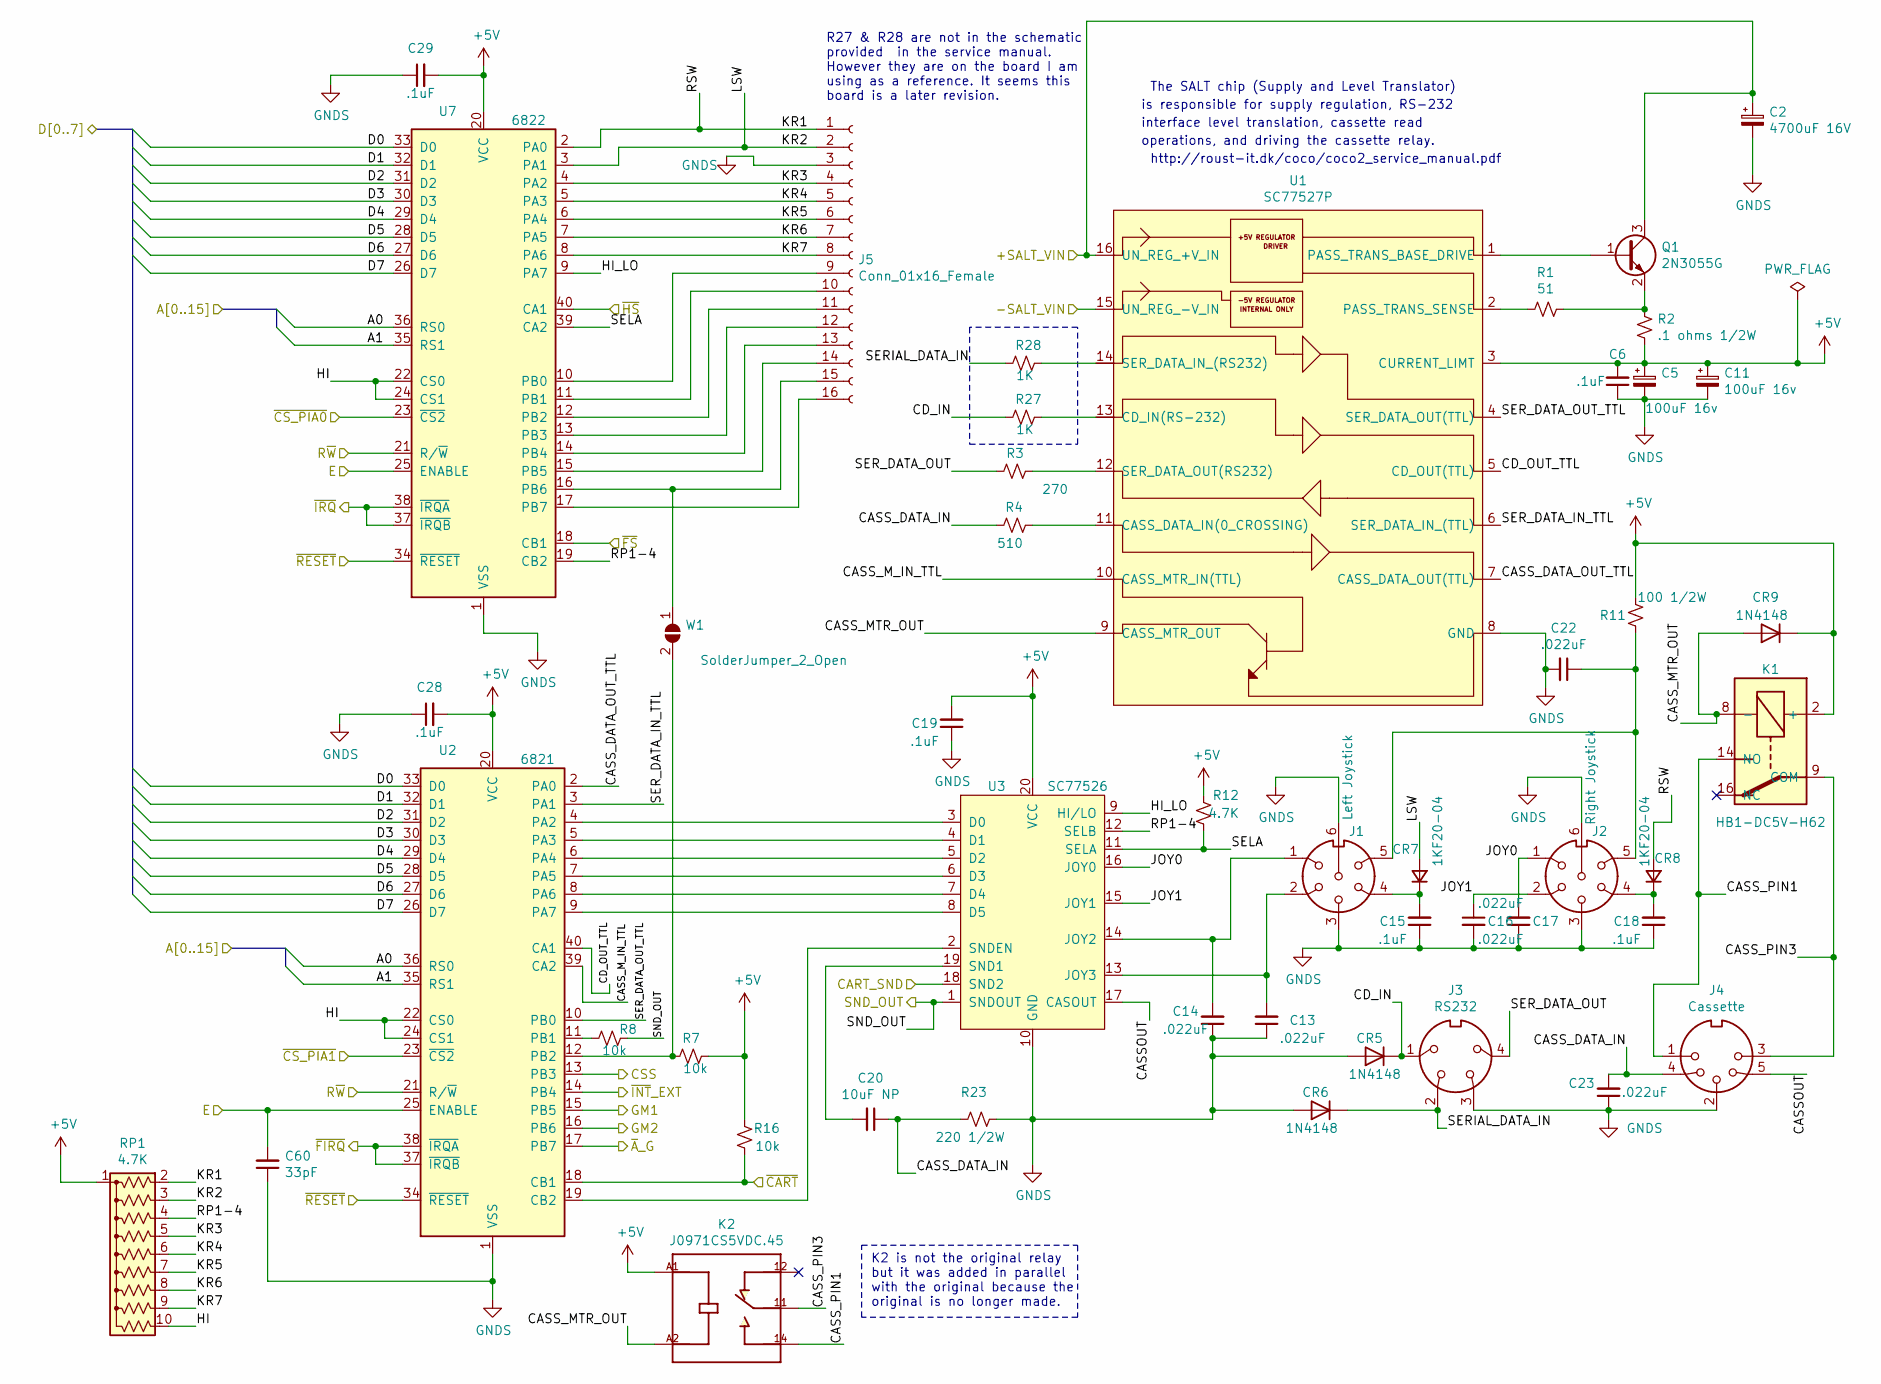
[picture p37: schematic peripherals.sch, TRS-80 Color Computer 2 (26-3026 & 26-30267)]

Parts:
C2: 4700uF 16V; CP_Radial_D16.0mm_P7.50mm; Manufacturer part# 16YXJ4700M16X25
C5, C11: 100uF 16v; CP_Radial_D8.0mm_P5.00mm; Manufacturer part# UST1C101MDD1TA
C6, C15, C18, C19, C28, C29: .1uF; C_Axial_L3.8mm_D2.6mm_P10.00mm_Horizontal; Manufacturer part# A104K15X7RF5TAA
C13, C14, C16, C17, C22, C23: .022uF; C_Disc_D8.0mm_W2.5mm_P5.00mm; Manufacturer part# C317C223M5U5TA7301
C20: 10uF NP; C_Radial_D5.0mm_H11.0mm_P2.00mm; Manufacturer part# UVP1C100MDD1TD
C60: 33pF; C_Rect_L7.2mm_W3.0mm_P5.00mm_FKS2_FKP2_MKS2_MKP2; Manufacturer part# FA28NP01H330JNU06
CR5, CR6, CR9: 1N4148; D_DO-35_SOD27_P7.62mm_Horizontal; Manufacturer part# 1N4148
CR7, CR8: 1KF20-04; D_A-405_P10.16mm_Horizontal; Manufacturer part# 1N4148
J1: Left Joystick; CUI_SDS-60J; Manufacturer part# SDS-60J
J2: Right Joystick; CUI_SDS-60J; Manufacturer part# SDS-60J
J3: RS232; CUI_SDS-40J; Manufacturer part# SDS-40J
J4: Cassette; CUI_SDS-50J; Manufacturer part# SDS-50J
J5: Conn_01x16_Female; PinHeader_1x16_P2.54mm_Vertical; Manufacturer part# 6-520415-6
K1: HB1-DC5V-H62; HB1-DC5V-H62_W7.62mm
K2: J0971CS5VDC.45; RELAY_J0971CS5VDC.45; Manufacturer part# J0971CS5VDC.45
Q1: 2N3055G; TO-3; Manufacturer part# 2N3055G
R1: 51; R_Axial_DIN0207_L6.3mm_D2.5mm_P10.16mm_Horizontal; Manufacturer part# CF1/4CT52R510J
R2: .1 ohms 1/2W; R_Axial_DIN0411_L9.9mm_D3.6mm_P15.24mm_Horizontal; Manufacturer part# LR1LJR10
R3: 270; R_Axial_DIN0207_L6.3mm_D2.5mm_P10.16mm_Horizontal; Manufacturer part# CF14JT270R
R4: 510; R_Axial_DIN0207_L6.3mm_D2.5mm_P10.16mm_Horizontal; Manufacturer part# CF14JT510R
R7, R8, R16: 10k; R_Axial_DIN0207_L6.3mm_D2.5mm_P10.16mm_Horizontal; Manufacturer part# CF14JT10K0
R11: 100 1/2W; R_Axial_DIN0411_L9.9mm_D3.6mm_P12.70mm_Horizontal; Manufacturer part# CF12JT100R
R12: 4.7K; R_Axial_DIN0207_L6.3mm_D2.5mm_P10.16mm_Horizontal; Manufacturer part# Stackpole Electronics Inc
R23: 220 1/2W; R_Axial_DIN0411_L9.9mm_D3.6mm_P12.70mm_Horizontal; Manufacturer part# CF12JT220R
R27, R28: 1K; R_Axial_DIN0207_L6.3mm_D2.5mm_P10.16mm_Horizontal; Manufacturer part# CF14JT1K00
RP1: 4.7K; R_Array_SIP10; Manufacturer part# 4610X-101-472LF
U1: SC77527P; DIP-16_W7.62mm_Socket; Manufacturer part# 1-2199298-4
U2: 6821; DIP-40_W15.24mm_Socket; Manufacturer part# ED40DT
U3: SC77526; DIP-20_W7.62mm_Socket; Manufacturer part# 243-20-1-03
U7: 6822; DIP-40_W15.24mm_Socket; Manufacturer part# ED40DT
W1: SolderJumper_2_Open; SolderJumper-2_P1.3mm_Open_RoundedPad1.0x1.5mm

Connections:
+5V: C5.1, C6.2, C11.1, C19.2, C28.2, C29.2, CR9.1 (K), K1.2 (+), K2.A1, R2.1, R7.1, R11.1, R12.2, R16.2, RP1.1 (common), U1.3 (CURRENT_LIMT), U2.20 (VCC), U3.20 (VCC), U7.20 (VCC); also elsewhere on the board
/A0: U2.36 (RS0), U7.36 (RS0); also elsewhere on the board
/A1: U2.35 (RS1), U7.35 (RS1); also elsewhere on the board
/CART_SND: U3.18 (SND2); also elsewhere on the board
/D0: U2.33 (D0), U7.33 (D0); also elsewhere on the board
/D1: U2.32 (D1), U7.32 (D1); also elsewhere on the board
/D2: U2.31 (D2), U7.31 (D2); also elsewhere on the board
/D3: U2.30 (D3), U7.30 (D3); also elsewhere on the board
/D4: U2.29 (D4), U7.29 (D4); also elsewhere on the board
/D5: U2.28 (D5), U7.28 (D5); also elsewhere on the board
/D6: U2.27 (D6), U7.27 (D6); also elsewhere on the board
/D7: U2.26 (D7), U7.26 (D7); also elsewhere on the board
/E: C60.2, U2.25 (ENABLE), U7.25 (ENABLE); also elsewhere on the board
/R~W: U2.21 (R/~W), U7.21 (R/~W); also elsewhere on the board
/peripherals/+SALT_VIN: C2.1, Q1.3 (C), U1.16 (UN_REG_+V_IN); also elsewhere on the board
/peripherals/-SALT_VIN: U1.15 (UN_REG_-V_IN); also elsewhere on the board
/peripherals/CASSOUT: J4.5, U3.17 (CASOUT)
/peripherals/CASS_DATA_IN: C20.1, C23.2, J4.4, R4.1, R23.2
/peripherals/CASS_DATA_OUT_TTL: U1.7 (CASS_DATA_OUT(TTL)), U2.2 (PA0)
/peripherals/CASS_MTR_OUT: CR9.2 (A), K1.8 (-), K2.A2, U1.9 (CASS_MTR_OUT)
/peripherals/CASS_M_IN_TTL: U1.10 (CASS_MTR_IN(TTL)), U2.39 (CA2)
/peripherals/CASS_PIN1: J4.1, K1.14 (NO), K2.14
/peripherals/CASS_PIN3: J4.3, K1.9 (COM), K2.11
/peripherals/CD_IN: CR5.1 (K), J3.1, R27.2
/peripherals/CD_OUT_TTL: U1.5 (CD_OUT(TTL)), U2.40 (CA1)
/peripherals/CSS: U2.13 (PB3); also elsewhere on the board
/peripherals/GM1: U2.15 (PB5); also elsewhere on the board
/peripherals/GM2: U2.16 (PB6); also elsewhere on the board
/peripherals/HI: RP1.10 (R9), U2.22 (CS0), U2.24 (CS1), U7.22 (CS0), U7.24 (CS1)
/peripherals/HI_LO: U3.9 (HI/LO), U7.9 (PA7)
/peripherals/JOY0: C17.2, J2.1, U3.16 (JOY0)
/peripherals/JOY1: C16.1, J2.2, U3.15 (JOY1)
/peripherals/KR1: CR8.2 (A), J5.1, RP1.2 (R1), U7.2 (PA0)
/peripherals/KR2: CR7.2 (A), J5.2, RP1.3 (R2), U7.3 (PA1)
/peripherals/KR3: J5.4, RP1.5 (R4), U7.4 (PA2)
/peripherals/KR4: J5.5, RP1.6 (R5), U7.5 (PA3)
/peripherals/KR5: J5.6, RP1.7 (R6), U7.6 (PA4)
/peripherals/KR6: J5.7, RP1.8 (R7), U7.7 (PA5)
/peripherals/KR7: J5.8, RP1.9 (R8), U7.8 (PA6)
/peripherals/RP1-4: RP1.4 (R3), U3.12 (SELB), U7.19 (CB2)
/peripherals/SELA: R12.1, U3.11 (SELA), U7.39 (CA2)
/peripherals/SERIAL_DATA_IN: CR6.1 (K), J3.2, R28.2
/peripherals/SER_DATA_IN_TTL: U1.6 (SER_DATA_IN_(TTL)), U2.3 (PA1)
/peripherals/SER_DATA_OUT: J3.4, R3.2
/peripherals/SER_DATA_OUT_TTL: U1.4 (SER_DATA_OUT(TTL)), U2.10 (PB0)
/peripherals/~A~_G: U2.17 (PB7); also elsewhere on the board
/peripherals/~INT~_EXT: U2.14 (PB4); also elsewhere on the board
/video/RF_SND: R8.1, U3.1 (SNDOUT); also elsewhere on the board
/~CART: R16.1, U2.18 (CB1); also elsewhere on the board
/~CSPIA1: U2.23 (~CS2); also elsewhere on the board
/~CS_PIA0: U7.23 (~CS2); also elsewhere on the board
/~FIRQ: U2.37 (~IRQB), U2.38 (~IRQA); also elsewhere on the board
/~FS: U7.18 (CB1); also elsewhere on the board
/~HS: U7.40 (CA1); also elsewhere on the board
/~IRQ: U7.37 (~IRQB), U7.38 (~IRQA); also elsewhere on the board
/~RESET: U2.34 (~RESET), U7.34 (~RESET); also elsewhere on the board
GNDS: C2.2, C5.2, C6.1, C11.2, C13.1, C14.1, C15.1, C16.2, C17.1, C18.1, C19.1, C22.2, C23.1, C28.1, C29.1, C60.1, CR5.2 (A), CR6.2 (A), J1.3, J1.6, J2.3, J2.6, J3.3, J4.2, J5.3, R23.1, U1.8 (GND), U2.1 (VSS), U3.10 (GND), U7.1 (VSS); also elsewhere on the board
unnamed: C13.2, J1.2, U3.13 (JOY3)
unnamed: C14.2, J1.1, U3.14 (JOY2)
unnamed: C15.2, CR7.1 (K), J1.4
unnamed: C18.2, CR8.1 (K), J2.4
unnamed: C20.2, U3.19 (SND1)
unnamed: C22.1, J1.5, J2.5, R11.2
unnamed: J5.9, U7.10 (PB0)
unnamed: J5.10, U7.11 (PB1)
unnamed: J5.11, U7.12 (PB2)
unnamed: J5.12, U7.13 (PB3)
unnamed: J5.13, U7.14 (PB4)
unnamed: J5.14, U7.15 (PB5)
unnamed: J5.15, U7.16 (PB6), W1.1 (A)
unnamed: J5.16, U7.17 (PB7)
unnamed: Q1.1 (B), U1.1 (PASS_TRANS_BASE_DRIVE)
unnamed: Q1.2 (E), R1.1, R2.2
unnamed: R1.2, U1.2 (PASS_TRANS_SENSE)
unnamed: R3.1, U1.12 (SER_DATA_OUT(RS232))
unnamed: R4.2, U1.11 (CASS_DATA_IN(0_CROSSING))
unnamed: R7.2, U2.12 (PB2), W1.2 (B)
unnamed: R8.2, U2.11 (PB1)
unnamed: R27.1, U1.13 (CD_IN(RS-232))
unnamed: R28.1, U1.14 (SER_DATA_IN_(RS232))
unnamed: U2.4 (PA2), U3.3 (D0)
unnamed: U2.5 (PA3), U3.4 (D1)
unnamed: U2.6 (PA4), U3.5 (D2)
unnamed: U2.7 (PA5), U3.6 (D3)
unnamed: U2.8 (PA6), U3.7 (D4)
unnamed: U2.9 (PA7), U3.8 (D5)
unnamed: U2.19 (CB2), U3.2 (SNDEN)

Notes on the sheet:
The SALT chip (Supply and Level Translator)
is responsible for supply regulation, RS-232
interface level translation, cassette read
operations, and driving the cassette relay.
http://roust-it.dk/coco/coco2_service_manual.pdf
R27 & R28 are not in the schematic provided in the service manual. However they are on the board I am using as a reference. It seems this board is a later revision.
K2 is not the original relay but it was added in parallel with the original because the original is no longer made.

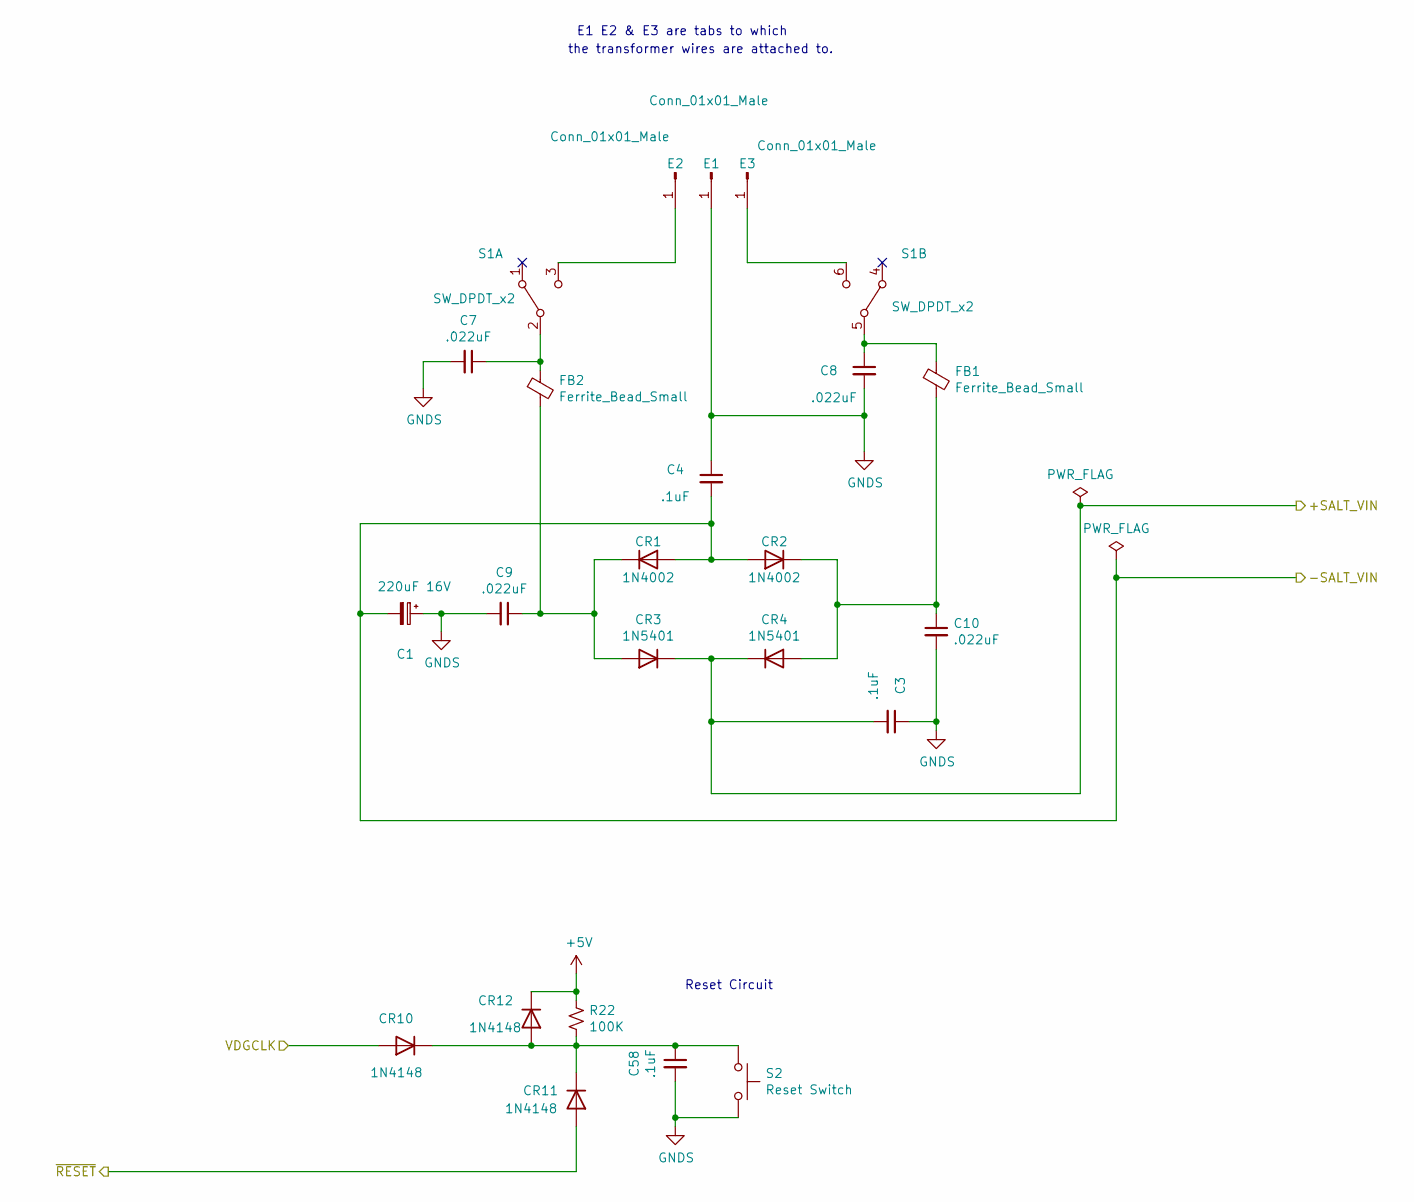
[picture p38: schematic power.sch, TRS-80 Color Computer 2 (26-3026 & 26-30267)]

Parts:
C1: 220uF 16V; CP_Radial_D8.0mm_P5.00mm; Manufacturer part# URS1C221MPD1TA
C3, C4, C58: .1uF; C_Axial_L3.8mm_D2.6mm_P10.00mm_Horizontal; Manufacturer part# A104K15X7RF5TAA
C7, C8, C9, C10: .022uF; C_Disc_D8.0mm_W2.5mm_P5.00mm; Manufacturer part# C317C223M5U5TA7301
CR1, CR2: 1N4002; D_DO-41_SOD81_P10.16mm_Horizontal; Manufacturer part# 1N4002G-T
CR3, CR4: 1N5401; D_DO-201AD_P15.24mm_Horizontal; Manufacturer part# 1N5401G-T
CR10, CR11, CR12: 1N4148; D_DO-35_SOD27_P7.62mm_Horizontal; Manufacturer part# 1N4148
E1, E2, E3: Conn_01x01_Male; Pin_D1.4mm_L8.5mm_W2.8mm_FlatFork; Manufacturer part# 1211
FB1, FB2: Ferrite_Bead_Small; ferrite_bead; Manufacturer part# 2743007111
R22: 100K; R_Axial_DIN0207_L6.3mm_D2.5mm_P10.16mm_Horizontal; Manufacturer part# CF14JT100K
S1: SW_DPDT_x2; F2UEE; Manufacturer part# F2UEE
S2: Reset Switch; B3F3152; Manufacturer part# B3F-3152

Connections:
+5V: CR12.1 (K), R22.1; also elsewhere on the board
/peripherals/+SALT_VIN: C3.2, CR3.1 (K), CR4.1 (K); also elsewhere on the board
/peripherals/-SALT_VIN: C1.2, C4.2, CR1.2 (A), CR2.2 (A); also elsewhere on the board
/power/VDGCLK: CR10.2 (A); also elsewhere on the board
/~RESET: CR11.2 (A); also elsewhere on the board
GNDS: C1.1, C3.1, C4.1, C7.2, C8.2, C9.2, C10.2, C58.2, E1.1, S2.2; also elsewhere on the board
unnamed: C7.1, FB2.1, S1.2 (B)
unnamed: C8.1, FB1.1, S1.5 (B)
unnamed: C9.1, CR1.1 (K), CR3.2 (A), FB2.2
unnamed: C10.1, CR2.1 (K), CR4.2 (A), FB1.2
unnamed: C58.1, CR10.1 (K), CR11.1 (K), CR12.2 (A), R22.2, S2.1
unnamed: E2.1, S1.3 (C)
unnamed: E3.1, S1.6 (C)

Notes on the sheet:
Reset Circuit
E1 E2 & E3 are tabs to which
the transformer wires are attached to.

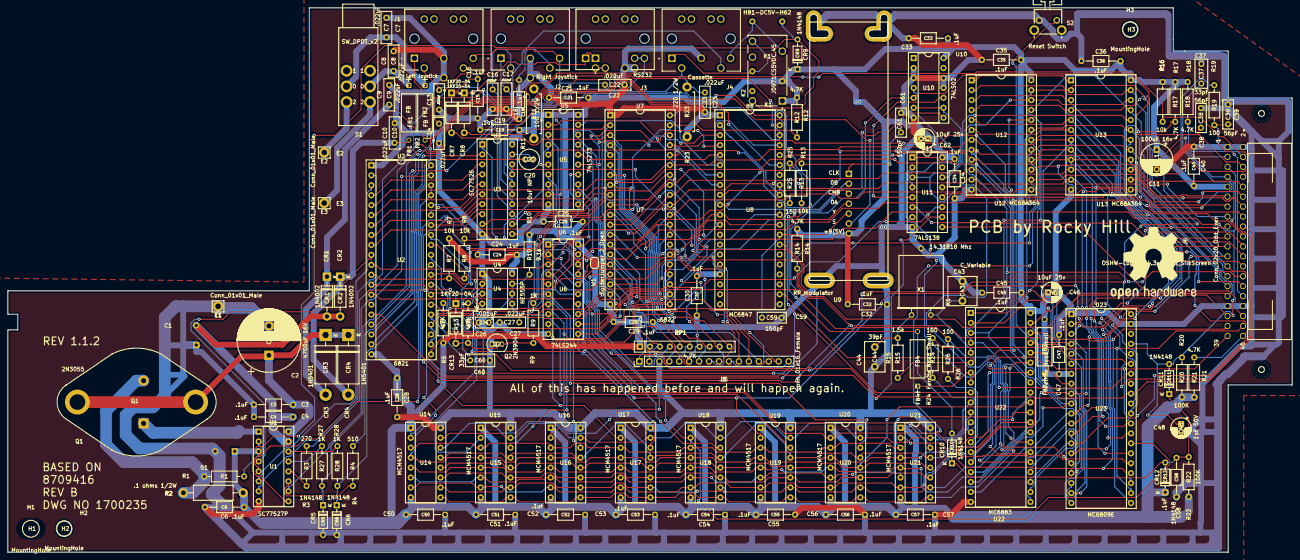
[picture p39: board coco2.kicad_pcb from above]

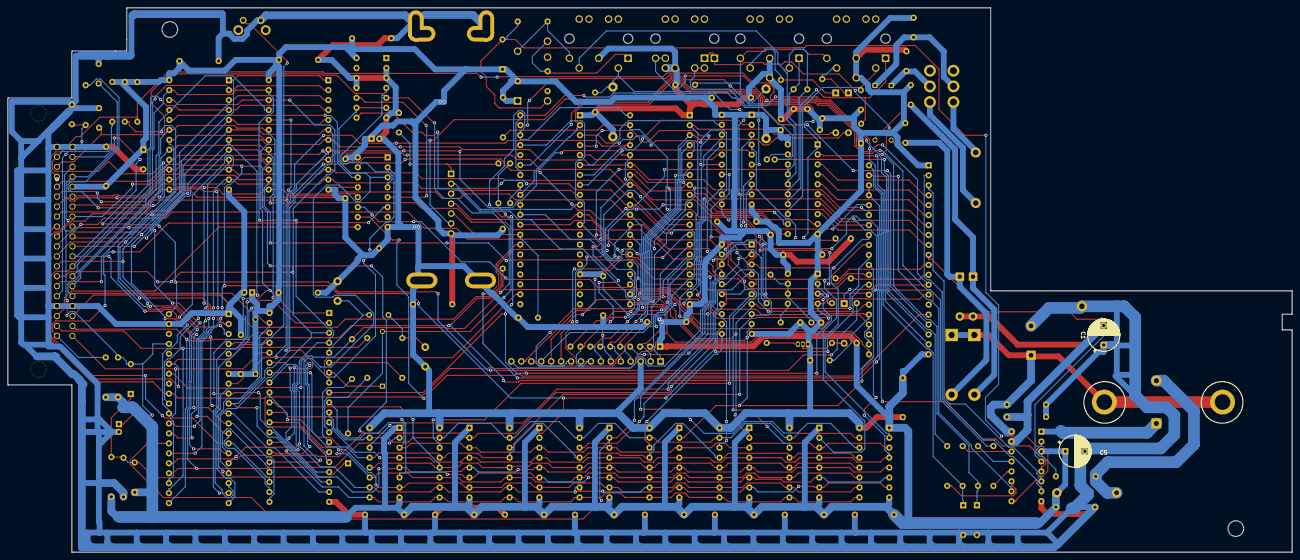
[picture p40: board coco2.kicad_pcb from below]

Board: 2 copper layers, 327.9 x 139.0 mm, 146 parts (2 on the bottom side), 169 nets.

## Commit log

2022-07-08 Added design files for the 26-313xA CoCo 2 motherboards
    [022182121.stp, B3F-3152.step, DIN-4.stp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]
2022-07-08 added design files for the 26-302x TRS-80 Color Computer motherboard
    [B3F-3152.step, DIN-4.stp, DIN-6.step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]
2022-07-08 added the design files for the 26-3334 Tandy Color Computer 3
    [009652038.stp, 022182121.step, 28L0138-10R-10.step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]
2022-07-08 added board renderings, schematics and layouts
2022-07-18 added a bill of materials for the 26-302x boards
    [26-302x_bill_of_materials.csv, coco2_bom_26-3026_26-3027.csv]
2022-07-18 removed items from the BOM that are not on this board
    [26-302x_bill_of_materials.csv]
2022-07-18 added component to BOM for 26-302x
    [26-302x_bill_of_materials.csv]
2022-07-18 fixed duplicated items
    [26-302x_bill_of_materials.csv]
2022-07-18 added bill of materials for the CoCo 3
    [26-3334_bill_of_materials.csv]
2022-07-23 -updated some component part numbers. -added a bill of materials
    [26-313xA_bill_of_materials.csv, cpu.sch, peripherals.sch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]
2022-08-04 -Corrected some part numbers in the BOM -Updated paret numbers for some parts in the schematic.
    [26-313xA_bill_of_materials.csv, coco2.sch, cpu.sch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]
2022-08-06 -moved power switch 4mm into the board. -moved reset switch 1mm towards the DIN connectors. -moved channel select switch .5mm into the DIN connectors. -shortened length of board from cart to power co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
    [coco2_bom_26-3026_26-3027.csv, dram.sch, power.sch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]
2022-09-11 Update 26-313xA_bill_of_materials.csv
    updated pins A1 A2 and A3 to ones with a slightly larger diameter.
    [26-313xA_bill_of_materials.csv]
2022-10-24 added 26-3134B T1 CoCo 2 board
    [022182121.stp, 26-313xB_bill_of_materials.csv, B3F-3152.step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]
2023-11-05 -modified CoCo 3 board layout to better match the original. -routed CoCo 3 board to better match original routing. -pin 39 of the GIME is connected to VCC1 on the CoCo 3 board but the original schema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
    -BOM, IBOM, rendered image and schematic have all been updated.
    -this version of the project now requires KiCAD 7 or above.
    [26-3334_bill_of_materials.csv, EDAC Card_Edge_Connector.step, coco3.kicad_sch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]
2023-11-05 removed gerber files
    [coco3-B_Adhes.gbr, coco3-B_CrtYd.gbr, coco3-B_Cu.gbr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]
2023-11-05 added a log file to record changes made to the CoCo 3 board.
2023-12-13 fixed some spelling mistakes in the 26-313x schematic
    [coco2.kicad_sch, cpu.kicad_sch, dram.kicad_sch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]
2025-07-20 Update 26-3334_bill_of_materials.csv with new capacitor part number
    The 24 decoupling are supposed to be .1uF however, the part number in the BOM called for .01uF capacitors. This was replaced with a part number for a .1uF capacitor from digikey
    [26-3334_bill_of_materials.csv]

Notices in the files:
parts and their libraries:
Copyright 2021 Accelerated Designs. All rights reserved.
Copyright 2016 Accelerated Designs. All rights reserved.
